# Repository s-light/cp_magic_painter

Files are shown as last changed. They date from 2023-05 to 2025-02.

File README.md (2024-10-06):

# cp_magic_painter - Malen mit Licht
POV (Persistance Of Vision) Zauberstab

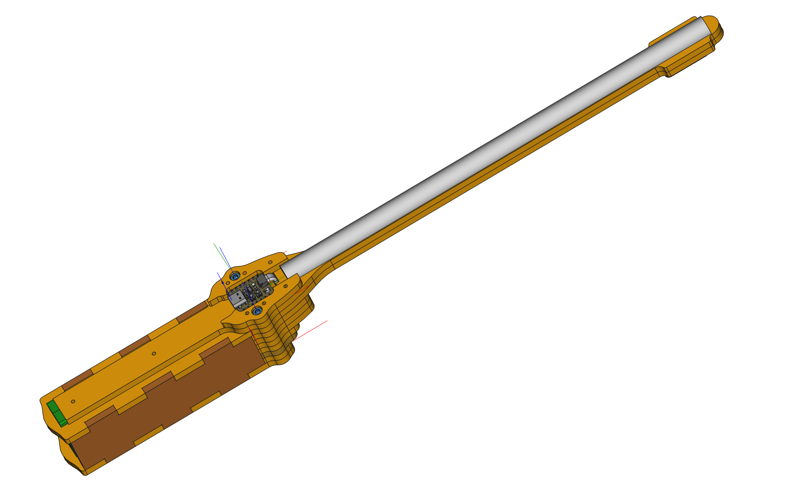
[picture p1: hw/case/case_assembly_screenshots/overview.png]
Zauberstab (CAD)

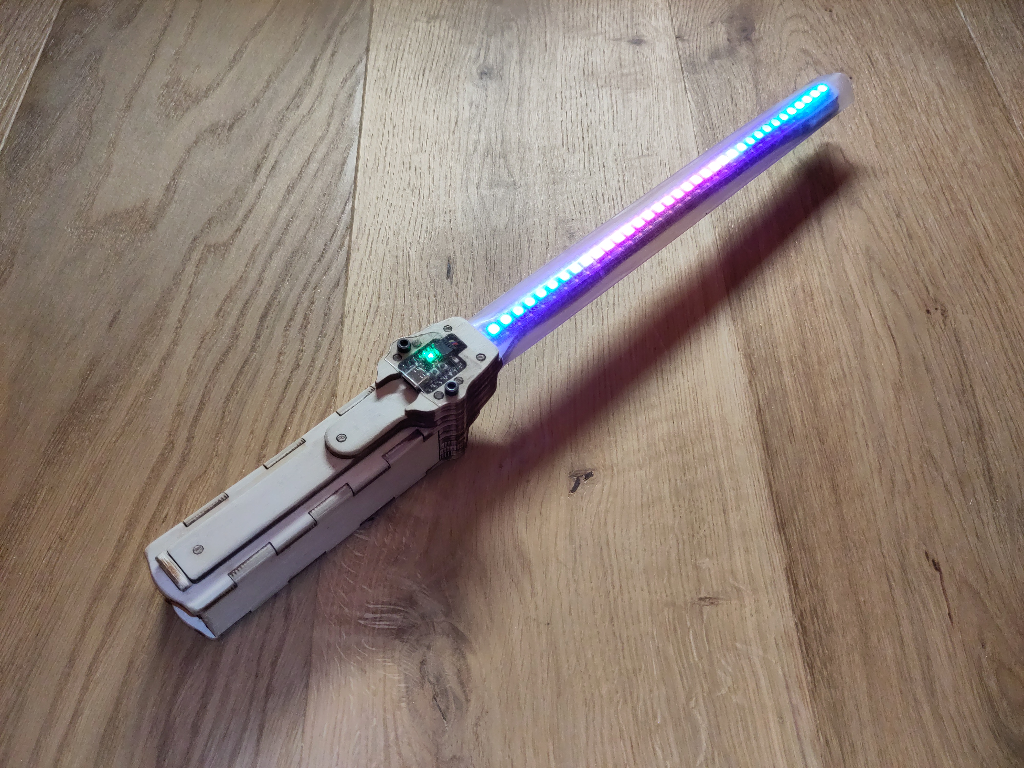
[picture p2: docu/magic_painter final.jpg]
Zauberstab Photo


https://github.com/s-light/cp_magic_painter/assets/1340319/28aa995e-11ee-43ee-a761-ba1665ddfda5

## documentation
have a look at [the documentation](https://s-light.github.io/cp_magic_painter/docu/)

Wichtige Dokumentations-Seiten:
- [Firmware Aktualisieren](https://s-light.github.io/cp_magic_painter/docu/update_firmware/de.html)
- [Bilder Vorbereiten](https://s-light.github.io/cp_magic_painter/docu/prepare_images/de.html)
- [Bedienung](https://s-light.github.io/cp_magic_painter/docu/usage/de.html)

## origin
this project / Workshop was first created for the [`Make Your School MakerFestival 2023`](https://www.makeyourschool.de/maker-festival/)

it is based on these two excellent Adafruit tutorials:
- [circuitpython painter](https://learn.adafruit.com/circuitpython-painter)
- [clue light paintstick](https://learn.adafruit.com/clue-light-paintstick)

## needed circuitpython libraries

- nonblocking_serialinput
- adafruit_lis3dh
- adafruit_pioasm
- adafruit_debouncer
- adafruit_pixelbuf
- adafruit_neopxl8
- adafruit_dotstar
- adafruit_ticks
- neopixel
- adafruit_msa3xx
- adafruit_bus_device
- ansi_escape_code
- adafruit_fancyled
- adafruit_imageload
- adafruit_register

## HW
have a look in [hw/](./hw/)

- uC: [Adafruit QT Py S3](https://learn.adafruit.com/adafruit-qt-py-esp32-s3/)
- sensor: [Adafruit LIS3DH Triple-Axis Accelerometer Breakout](https://learn.adafruit.com/adafruit-lis3dh-triple-axis-accelerometer-breakout/overview)
- LEDs: APA102 / Dotstar ([z.B. this one](https://www.adafruit.com/product/2241) - we need 36Pixel (25cm))

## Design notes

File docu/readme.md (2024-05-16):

# cp_magic_painter - Malen mit Licht 
POV (Persistance Of Vision) Zauberstab

Zauberstab (CAD)
Zauberstab Photo
<video src="mode%20POVPainter.mp4" controls title="Mode: POVPainter - showing two different images"></video>

currently some documentation is only written in german.
an english version will follow hopefully some day...

## Build / Zusammenbauen
- [build documentation / Bau-Workshop Anleitung (DE)](workshop_DE.md)

## Prepare / Vorbereitungen

- [prepare images / Bilder Vorbereiten (DE)](prepare_images/de.md)
- [update firmware / Software Aktualisiseren (DE)](update_firmware/de.md)

## Usage / Benutzung

- [Benutzung (DE)](usage/de.md)
- [usage (EN)](usage/en.md)

to take lightpainting photos have a look at [my simple lightpaint web-app](https://s-light.github.io/quasar_lightpaint/dist/spa/#/)
([repro](https://github.com/s-light/quasar_lightpaint))

## HW

-   APA102 ('Dotstar') LED-Pixel-Strip 144Pixel/m - **36 LEDs**
-   [Adafruit QT Py ESP32-S3](https://www.adafruit.com/product/5426) as controller
-   [Adafruit LIS3DH Triple-Axis Accelerometer](https://www.adafruit.com/product/2809)
-   USB PowerBank [PNY PowerPack T2600 (P-B-2600-1-K01-RL)](https://www.pny.com/File%20Library/Support/PNY%20Products/Resource%20Center/PowerPacks/PowerPack_T-Series_web.pdf) i got some old stock - nice form factor: 101,9 mm x 24 mm x 22,3 mm
  sadly its getting hard to get these Lithium-ion cylindrical cell packs..
-   some [lasercut wood](hw/case/export/case_parts_mod.svg) for the case..

for more details have a look at the [order_overview.pdf](hw/order__overview.pdf)

## project state

next steps
- firmware
  - fix touch buttons
  - add gesture recognition
- docu
  - how to update firmware
  - how to change configuration

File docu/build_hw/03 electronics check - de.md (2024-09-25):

# Elektronik vorbereiten

<style>
    html, body {
        background: hsl(270,100%,10%);
        color: hsl(40, 100%, 50%);
        font-size: 1.2em;
    }
    img {
        max-width: 90vw;
        max-height: 60vh;
    }
</style>

<!-- LED-Streifen
![LED-Streifen](<pictures/03 test electronics/20230913_132513_HDR.jpg>)
Controller
![Controller](<pictures/03 test electronics/20230916_224711.jpg>)
adapter
![adapter](<pictures/03 test electronics/20230917_012738.jpg>) -->

alle bauteile zurecht legen
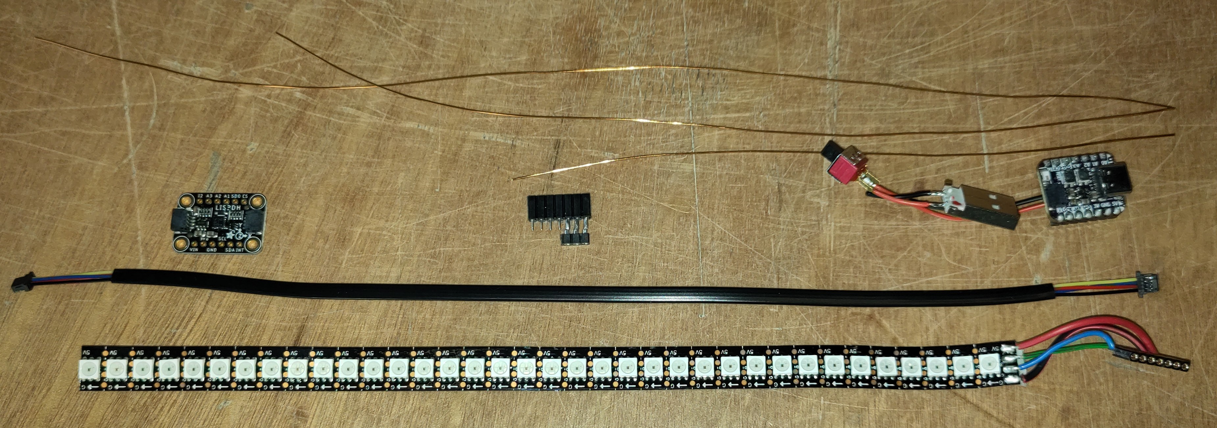
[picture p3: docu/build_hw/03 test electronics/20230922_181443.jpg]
electronic parts


In den Fotos sind noch \*Touch-Buttons zu sehen.
Diese habe ich wegen unzuverlässigkeit raus genommen.

## Beschleunigungssensor

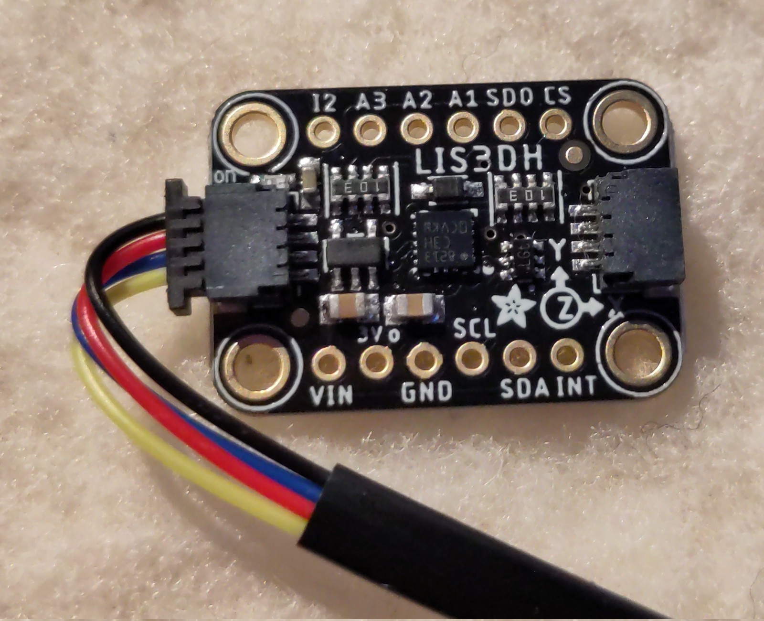
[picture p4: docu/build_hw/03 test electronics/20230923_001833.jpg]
sensor


im bild oben rechts ist die Power-LED sichtbar.
Unten auf der Platine ist `VIN` aufgedruckt.
auf dieser Seite möchte das Kabel eingesteckt werden.
schon mal etwas vorsichtig umbiegen wie im bild hilft später für die Positionierung.

# Elektronik testen

## LED-Streifen

nun den led-streifen an den controller anschließen
dabei auf die beschriftungen auf der Controller-Platine achten:

-   rotes Kabel auf +5V
-   schwarzes Kabel auf GND
-   Blaue sollte bei SCK (clock) landen
-   Grün bei MOSI (Master Out Slave In)

## Beschleunigungssensor

das freie Ende nun in den Controller stecken

## Buttons

falls vorhanden:
die drei Buttons kommen in die Pins mit den Namen

-   `SDA` unterster Button
-   `SCL` mittlerer Button
-   `TX` oberer Button

## alle bauteile zusammengesteckt

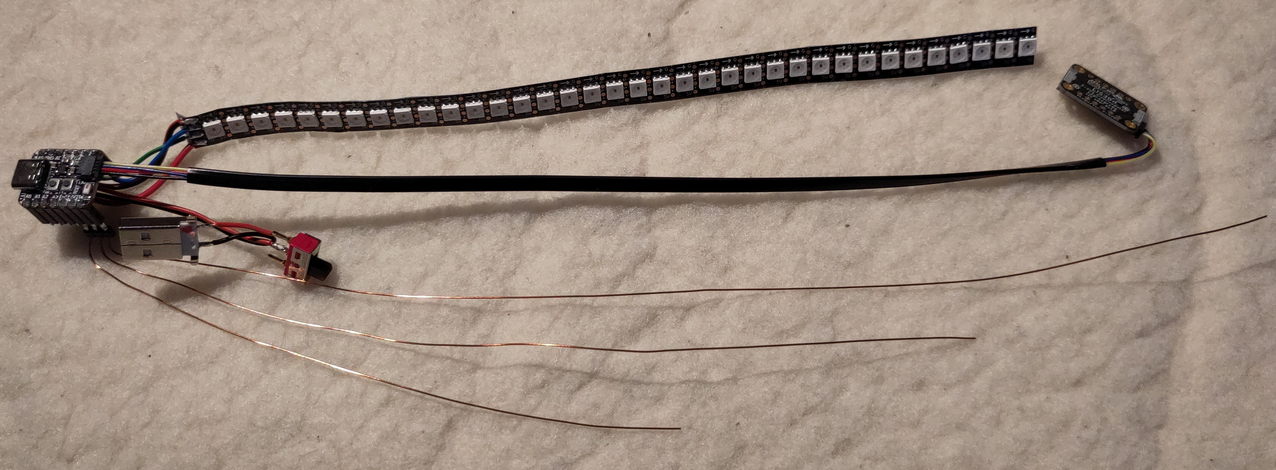
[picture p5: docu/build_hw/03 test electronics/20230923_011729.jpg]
alle bauteile zusammengesteckt


> vorsichtig das sich keine metallteile berühren!

nun Vorsichtig die Powerbank anstecken..
Schalter einschalten
und....

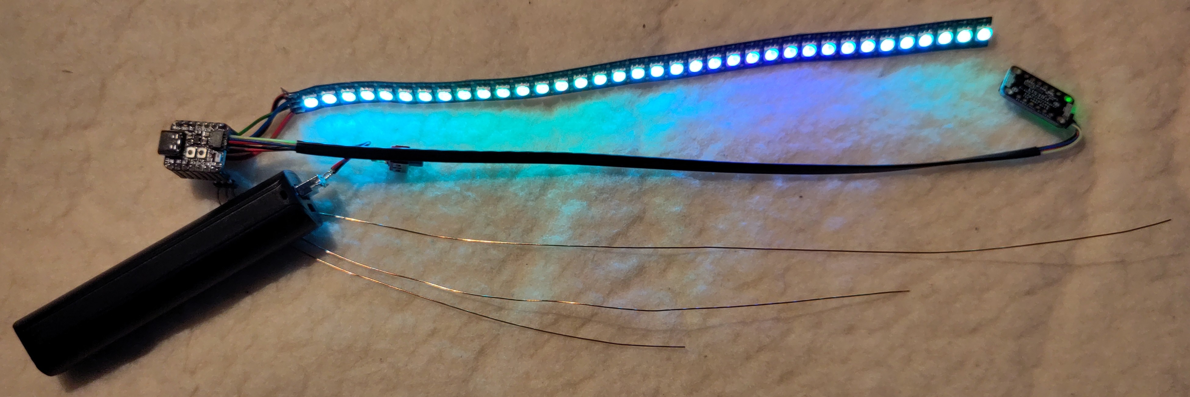
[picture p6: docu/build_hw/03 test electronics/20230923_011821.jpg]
und einmal testen

und alles geht :-)

## Test

-   erst sollte auf dem Controller die LED in verschiedenen Farben Leuchten.
-   dann der Streifen einen grünen _ladebalken_ anzeigen
-   dann einmal vorsichtig den Sensor in der Y-Achse schütteln
-   darauf hin sollte der Streifen flackern
-   dann den Taster D0 auf dem Controller drücken
-   dies schaltet in den Lampen modus um
-   nun leuchtet eine LED ganz am ende des Streifens
-   nun den längsten Draht / Button _oben_ mehrfach berühren
-   darauf hin sollten auf dem Streifen immer mehr LEDs an gehen / es wird heller
-   beim mittleren Button sollten diese wieder ausgehen / dunkler werden
-   beim untersten Button sollte die Helligkeit wieder auf minimum (1 LED) springen

damit sind alle Funktionen getestet.
→ Power-Schalter wieder ausschalten und Powerbank abziehen

→ Bauteile wieder auseinander stecken !!

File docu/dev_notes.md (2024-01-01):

# Notes from development

## Gesture / Sensor Data / Filter
- https://courses.ideate.cmu.edu/16-223/f2021/text/code/pico-signals.html#hysteresis-py
- https://stackoverflow.com/questions/4611599/smoothing-data-from-a-sensor
- https://hackaday.com/2019/09/06/sensor-filters-for-coders/    
- https://stackoverflow.com/questions/29330792/weighted-averaging-a-list
- https://stackoverflow.com/questions/18517722/weighted-moving-average-in-python

## Others
- https://learn.adafruit.com/key-pad-matrix-scanning-in-circuitpython/keys-one-key-per-pin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
- [Cooperative Multitasking in CircuitPython with asyncio](https://learn.adafruit.com/cooperative-multitasking-in-circuitpython-with-asyncio/communicating-between-tasks)
    - https://github.com/adafruit/Adafruit_CircuitPython_asyncio/blob/main/examples/serial_examples.py
- https://learn.adafruit.com/clue-light-paintstick/make-pixel-art
- https://github.com/adafruit/Adafruit_CircuitPython_DotStar/issues/64
- https://github.com/hfg-gmuend/openmoji.org/issues/182

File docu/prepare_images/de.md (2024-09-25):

<style>
    html, body {
        background: hsl(270,100%,10%);
        color: hsl(40, 100%, 50%);
        font-size: 1.2em;
    }
    img {
        max-width: 80vw;
        max-height: 50vh;
    }
</style>

# Vorbereitung der Bilder

Momentan werden Bilder in Folgendem Format unterstützt:

```
Datei-Typ: BMP
Farb-Tiefe: 3x8bit
Auflösung: 36x36 Pixel
```

als Symbole eignen sich _icons_ aus dem Schriftsatz Bereich -
das was wir als _emoji_ & _smiley_ kennen...
diese sind optimiert in sehr klein - also mit wenig Pixeln - gut erkennbar zu sein.

alternativ kannst du natürlich auch andere bild-quellen nehmen oder etwas selbst malen..

Damit der Zauberstab die Bilder anzeigen kann müssen diese in einem Speziellen Format gepeichert sein.
dieses nennt sich `Windows Bitmap` - und es ist wichtig das es als `24bits` `8R 8G 8B` gespeichert wird.

ich habe dir eine Anleitung geschrieben die genau das mit eben einem emoji macht.

am einfachsten ist es du suchst dir solch ein symbol auf dieser Website heraus:
https://openmoji.org/

alternative gibt es auch apps für den computer um diese als eine liste zu haben..
für linux z.B. den `emoji selector`

## Video Anleitung

Ich habe dir zwei kurze Videos gemacht:

1. Emoji suchen und kopieren
   <video src="openmoji.org%20search%20and%20copy%20%20candle.mp4" controls title="Title"></video>
2. Gimp - einfügen und ausrichten
   <video src="gimp%20paste%20candle.mp4" controls title="Title"></video>

## Text Anleitung

und hier als schritt für schritt text Anleitung:

1. Emoji suchen und kopieren

-   rufe die website [openmoji.org](https://openmoji.org/) auf
-   suche nach einem begriff (englisch)
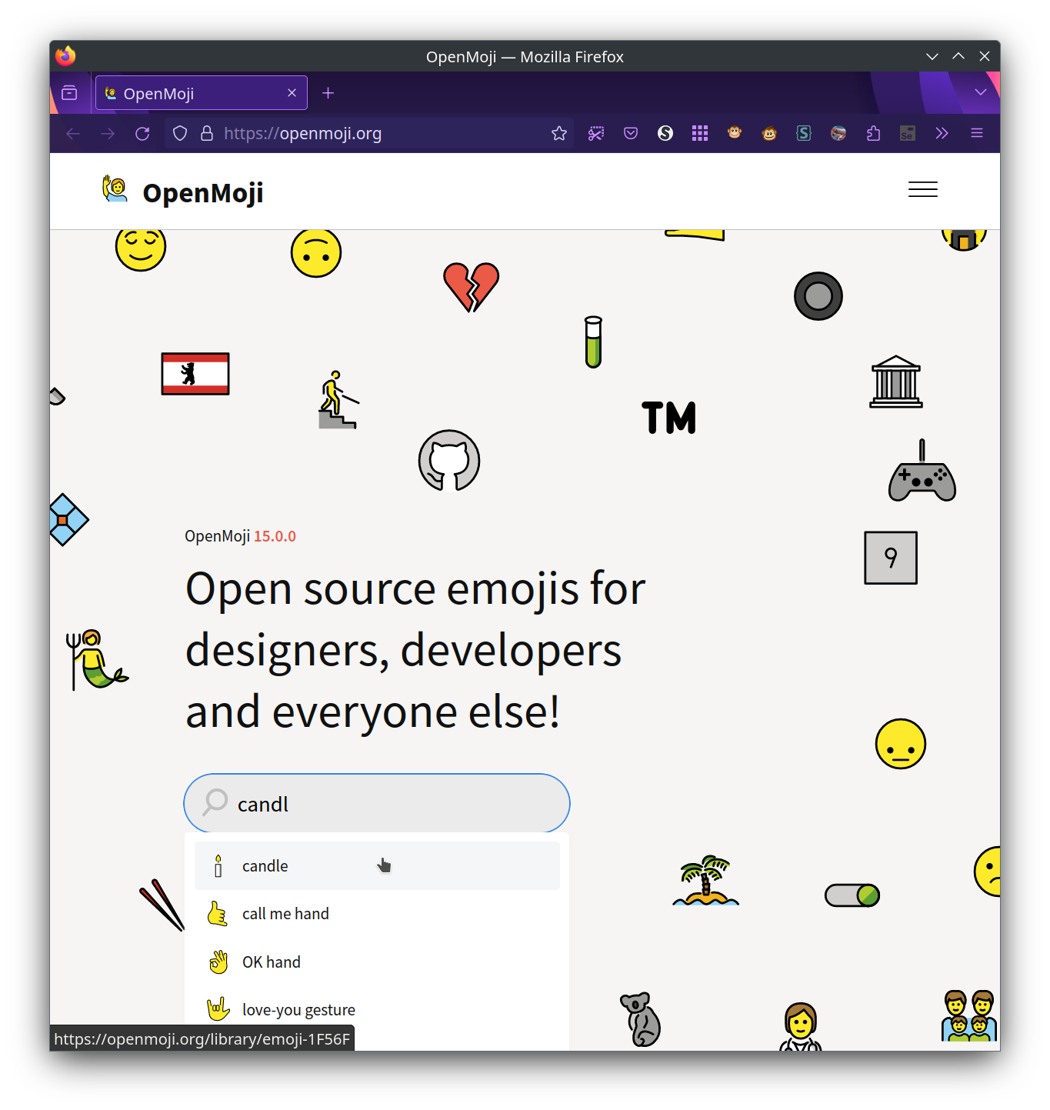
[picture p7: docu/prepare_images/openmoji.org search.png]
openmoji.org search
    
-   und öffne die detail Ansicht des emoji
-   nun in die zwischenablage kopiere 
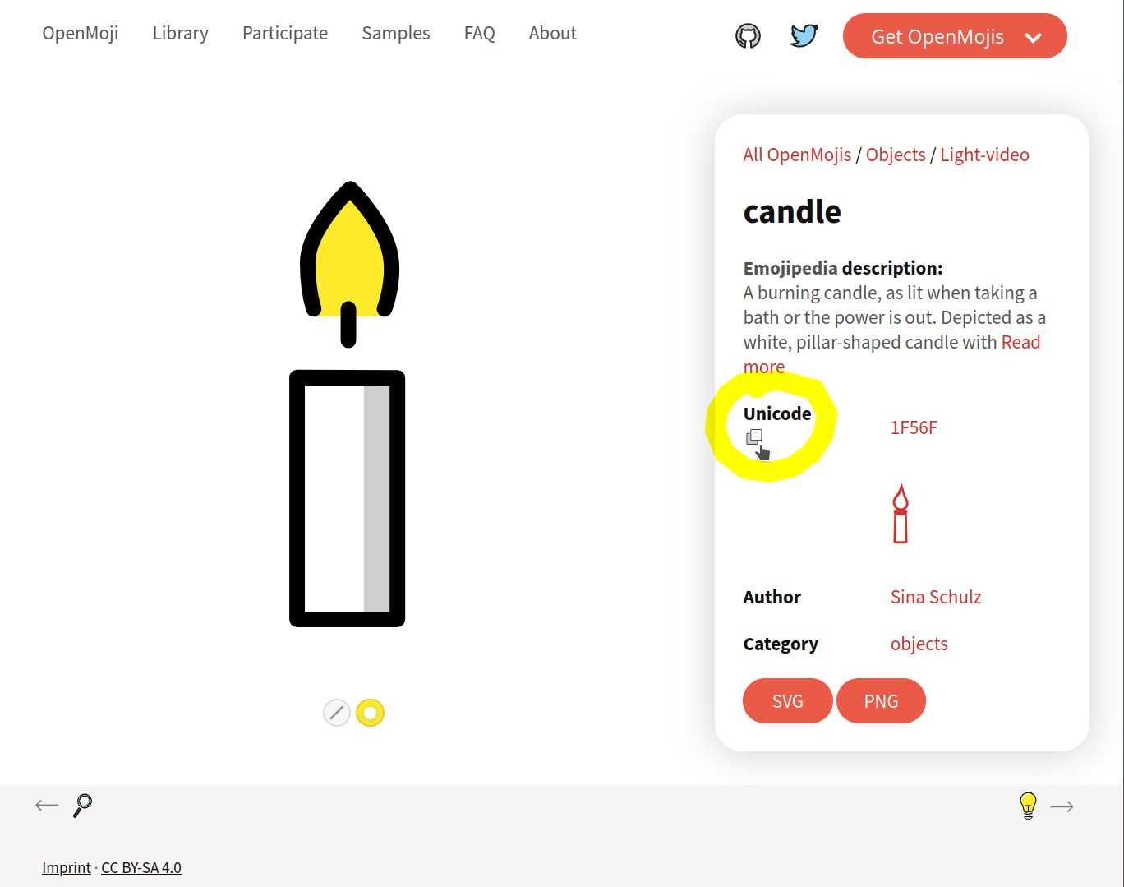
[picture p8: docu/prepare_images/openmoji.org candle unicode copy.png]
openmoji.org candle
    
-   das *Unicode-Zeichen* mit dem kleinen *CopyButton*
    <!-- - **oder** alternative das openmoji Bild mit Strg + click auf den PNG button -->

2. Gimp - einfügen und ausrichten

ich verwende hier [Gimp (GNU Image Manipulation Program)](https://www.gimp.org/).
dies ist ein Frei Verfügbares Bild-Bearbeitungsprogramm welches auf allen gängigen PCs laufen sollte.
die Schritte können jedoch ansich auch mit jedem anderen Grafik-Program durchgeführt werden.

-   [Gimp (GNU Image Manipulation Program) installieren](https://www.gimp.org/)
-   Gimp Starten
-   lade das Beispielbild [`images/01_testpattern_smile.xcf`](./../../CIRCUITPY_disc/images/01_testpattern_smile.xcf) herunter
-   das Beispielbild `01_testpattern_smile.xcf` öffnen: `Datei - Öffnen`
-   dort gibt es nun ein _text_ object.
-   aktivieren des `text tool` (shortcut: `t`):
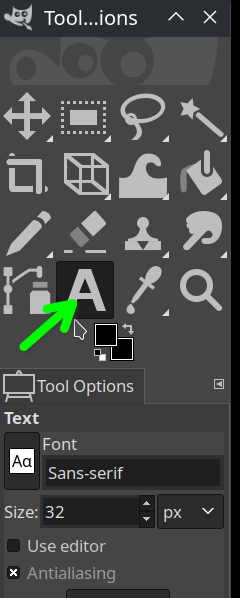
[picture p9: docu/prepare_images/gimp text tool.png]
text tool anwählen
    
-   nun mit einem click auf den smiley das object anwählen
-   nun ist der Text Modus aktiv.
-   unsere Schrift Größe ist ca 32pixel - so füllt das symbol die ganze Höhe aus.
-   du kannst jetzt das alte symbol löschen
-   und mit `Strg + V` das neue aus der zwischenablage einfügen
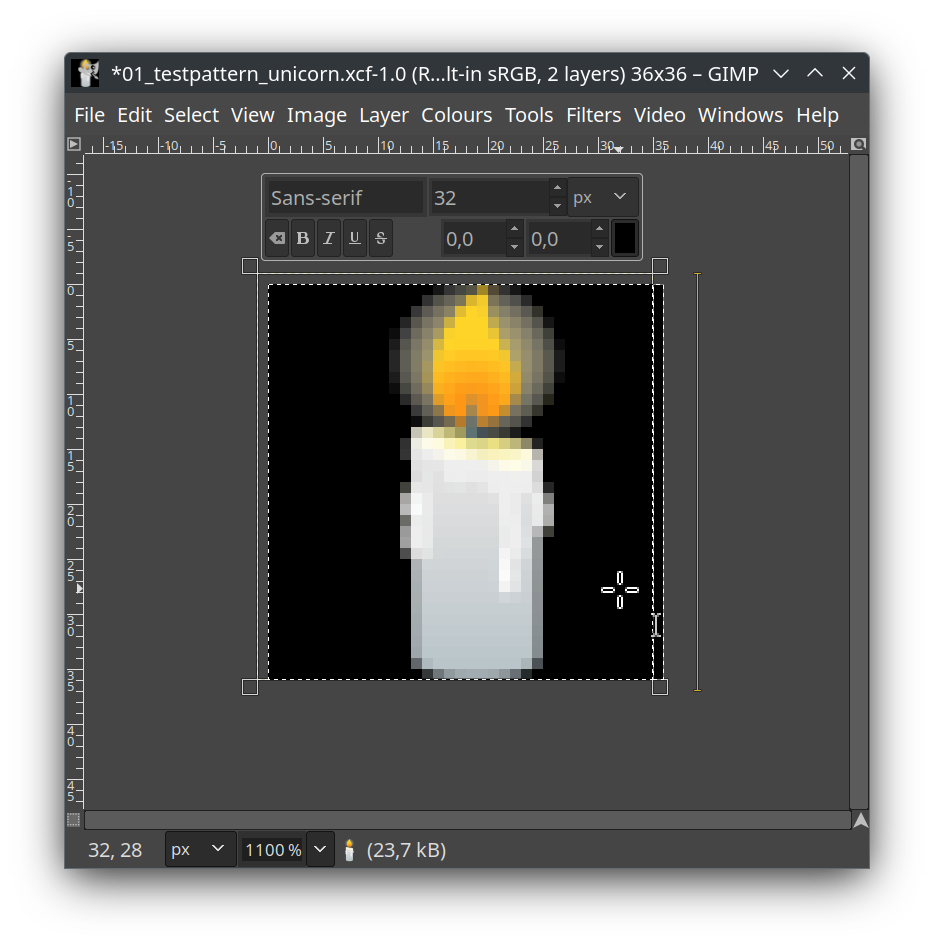
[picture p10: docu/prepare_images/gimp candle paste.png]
gimp pasted
    
-   eventuell jetzt noch die font-größe anpassen..
-   und dann falls nötig mit dem verschiebe tool passend positionieren:
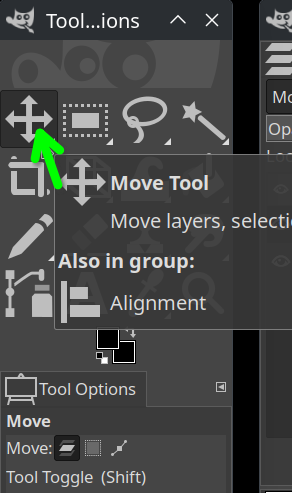
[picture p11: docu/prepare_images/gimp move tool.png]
gimp move tool
    
-   am einfachsten lässt es sich mit den pfeiltasten verschieben..
-   nun noch speichern: `Datei - Exportieren als`
    -   name wählen und als Dateiendung `bmp` angeben.
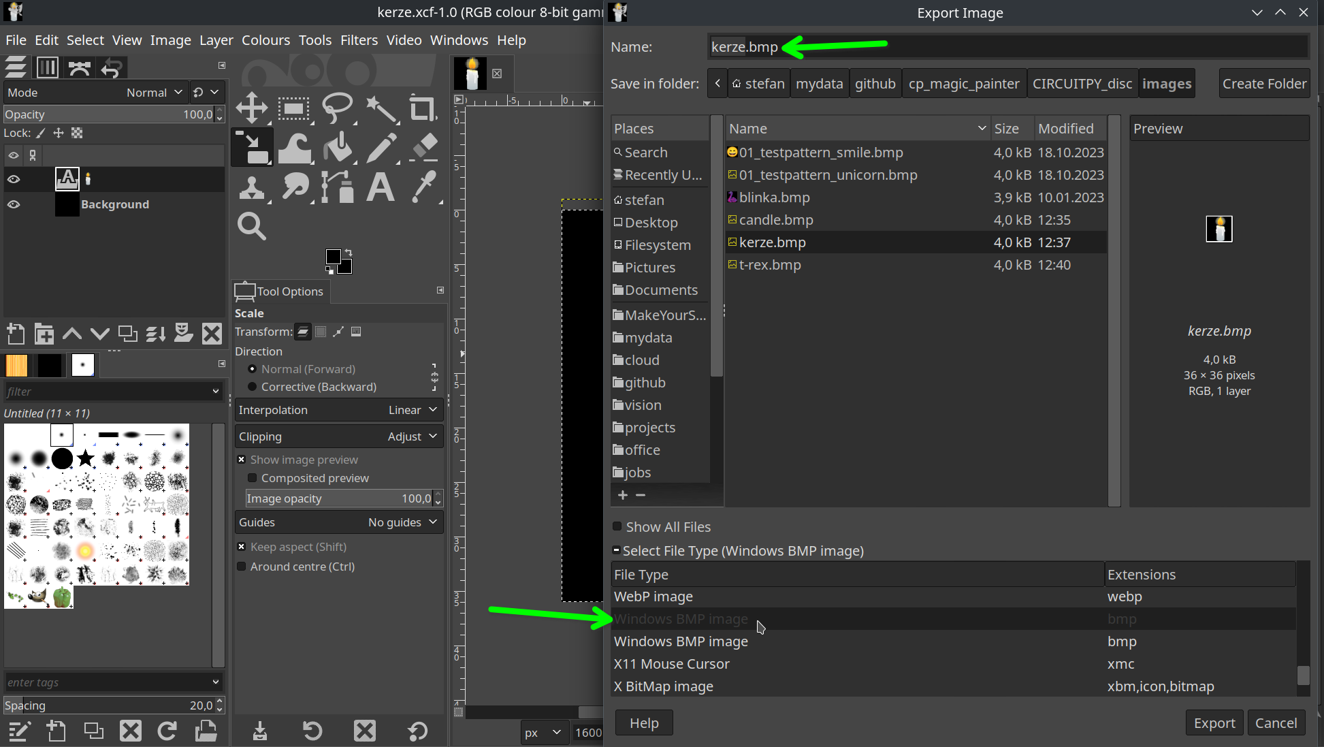
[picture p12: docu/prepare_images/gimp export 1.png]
gimp export 1
        
    -   export drücken
    -   und nun `advanced options` aufklappen und `24bits` `8R 8G 8B` auswählen
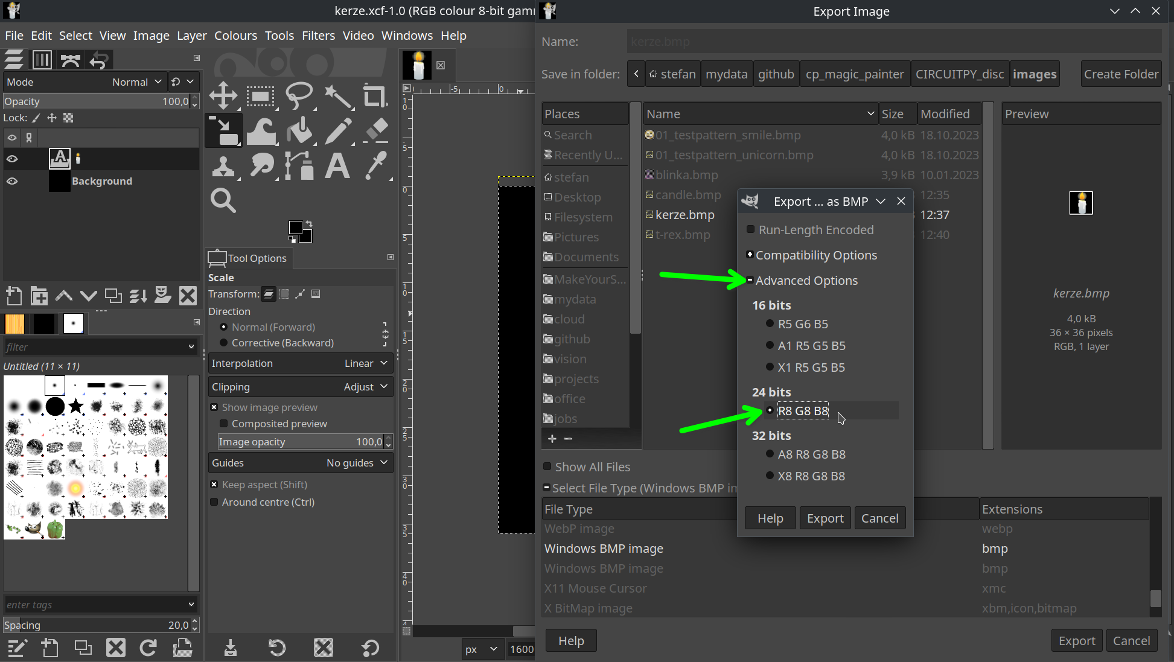
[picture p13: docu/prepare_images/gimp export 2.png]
gimp export 2
        
-   nun noch das neue Bild auf den Zauberstab kopieren
    -   dafür den Zauberstab an den computer anschließen
    -   den Datei-Explorer öffnen
    -   es sollte ein neuer USB-Speicherstick mit dem Namen `CIRCUITPY` erschienen sein.
    -   dort gibt es einen Ordner `images`
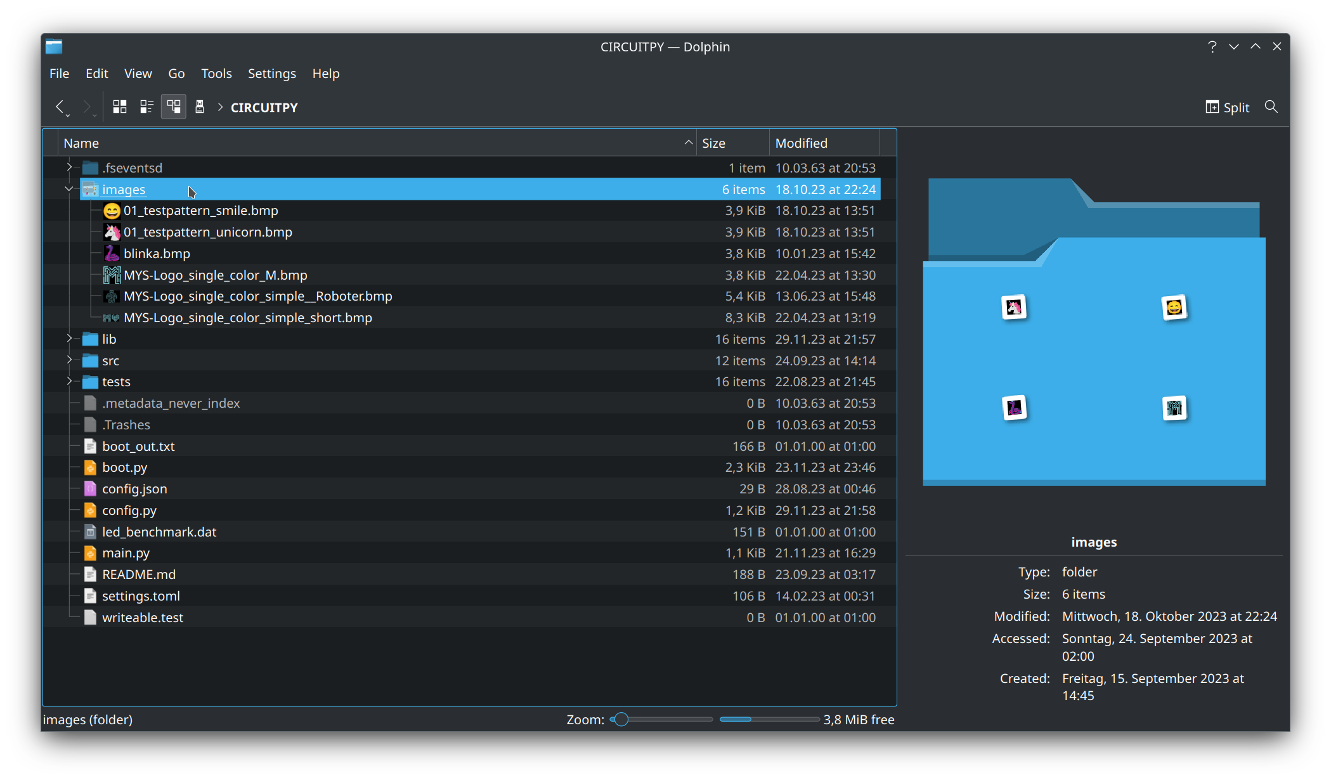
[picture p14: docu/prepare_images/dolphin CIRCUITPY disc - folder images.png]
CIRCUITPY disc - folder images
        
    -   dort hinein gehört das neue bild.

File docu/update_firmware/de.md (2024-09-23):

# Update *Firmware*

hier eine kurze Anleitung wie du die Firmware - 
also das Program auf dem Zauberstab-controller -
auf die neuste Version aktualisierst:

hier im beispiel auf meinem Linux System - 
doch ich denke das du das gut auf dein eigenes System übertragen kannst..

## Video

<video src="update_firmware.mp4" controls title="Update Firmware"></video>

## Schritt für Schritt Text

- download der aktuellen version von [github.com/s-light/cp_magic_painter](https://github.com/s-light/cp_magic_painter)
- entpacken des ZIP-Archives
- in den unterordner `CIRCUITPY_disc` gehen
- dort alle Dateien markieren
- kopieren (RechtsClick `Kopieren` oder mit Tastatur: `Strg+C`)
- den Zauberstab mit dem Computer verbinden
- es taucht ein neues USB-Massenspeicher-Laufwerk mit dem Namen `CIRCUITPY` auf
- dort RechtsClick einfügen oder ShortCut `STrg+V`
- abfrage: alles überschreiben? `JA`
- prüfen das KEIN `code.py` vorhanden ist.

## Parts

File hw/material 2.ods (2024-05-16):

Material übersicht / Sammlung |  |  | bestellt am | preis |  |  | anteil je TN |  | für WS je TN |  | Für WS ges.
 |  |  |  | gesamt |  |  |  |  |  |  | Menge | Summe
Bereich | Produkt | url |  | inkl. vers. | menge | Preis | anteil | preis | verwendet | 55,04 € | 12TN | 662,05 € | comment 1 | comment 2 | comment 3
 | Powerbank Sacramento - blau | https://www.highflyers.de/product_info.php/products_id/122607 | - | 93,97 € | 23 | 4,09 € | 1 | 4,09 € |  |  |  |  | 92 mm x 25 mm x 25 mm | 2200mAh, microUSB, 1A, min 22x | mind. 23
 | Aluminium Powerbank POWERALU - silber matt | https://www.highflyers.de/product_info.php/products_id/89293 | - | 96,31 € | 18 | 5,35 € | 1 | 5,35 € |  |  |  |  | 95 mm x 21 mm x 21 mm | 2200mAh, microUSB, 1A, min 16x | mind. 18
 | Powerbank ENDURANCE - blau (metal) | https://www.highflyers.de/product_info.php/products_id/75415 | - | 216,52 € | 50 | 4,33 € | 1 | 4,33 € |  |  |  |  | 100 mm x 20 mm x 20 mm | 2200mAh, microUSB, 1A, min 50x | mind. 50
 | Metallpowerbank Port Hope | https://www.highflyers.de/product_info.php/products_id/112119 | - | 93,12 € | 21 | 4,43 € | 1 | 4,43 € |  |  |  |  | 95 mm x 21 mm x 22 mm | 2200mAh, microUSB | mind. 21
 | Livepac Office - Powerbank aus Aluminium | https://www.ebay.de/itm/125127449122?itmmeta=01HRJJ77C5Z9E78R9E8C7FH46N | - | 61,83 € | 12 | 5,15 € | 1 | 5,15 € |  |  |  |  | 95 mm x 21 mm x 22 mm | 2200mAh, microUSB
 | Powerbank aus Aluminium 2.200 mAh Einzeln Restposten | https://www.amazon.de/gp/product/B07RS3WMG1 | 10.03.24 | 60,00 € | 12 | 5,00 € | 1 | 5,00 € | 1 | 5,00 € | 12 | 60,00 € | 95 mm x 21 mm x 22 mm | 2200mAh, microUSB
 | Powerbank aus Aluminium 2.200 mAh 20Stück | https://www.amazon.de/gp/product/B07H36LNGX | - | 85,00 € | 20 | 4,25 € | 1 | 4,25 € |  |  |  |  | 95 mm x 21 mm x 22 mm | 2200mAh, microUSB
 | Powerbank aus Aluminium 2.200 mAh Einzeln | https://www.amazon.de/gp/product/B076TGKS37 | - | 62,88 € | 12 | 5,24 € | 1 | 5,24 € |  |  |  |  | 95 mm x 21 mm x 22 mm | 2200mAh, microUSB
LEDs | SK9822 144LEDs/m offen | https://www.amazon.de/dp/B07BPX2KFD | 10.03.24 | 112,29 € | 3 | 37,43 € | 0,25 | 9,36 € | 1 | 9,36 € | 12 | 112,29 € | BFT-Lighting bekannter amazon shop
 | SK9822 144LEDs/m offen | https://www.amazon.de/dp/B0BYSHDDWT?th=1 | - | 83,70 € | 3 | 27,90 € | 0,25 | 6,98 € |  |  |  |  | unbekannter amazon shop
 | APA102 Narrow 5mm 2020SMD 200LEDs/M | https://www.superlightingled.com/apa102-narrow-5mm019in-wide-2020smd-high-density-200ledsm-dc5v-individually-addressable-rgb-led-strip-lights-p-3353.html | - | 201,07 € | 3 | 67,02 € | 0,2 | 13,40 € |  |  |  |  | unbekannter shop | higher density - a little more pixels: nicer picture..
 | APA102 Narrow 5mm 2020SMD 200LEDs/M | https://www.ledlightinghut.com/apa102-2020-digital-rgb-led-strip.html | - | 208,50 € | 3 | 69,50 € | 0,2 | 13,90 € |  |  |  |  | unbekannter shop | higher density - a little more pixels: nicer picture..
controller | Adafruit QT Py ESP32-S3 | https://www.mouser.de/ProductDetail/Adafruit/5700?qs=mELouGlnn3fE0chohESxSg%3D%3D | - | 166,08 € | 12 | 13,84 € | 1 | 13,84 € |  |  |  |  | 4MB Flash 2MB PSRAM | not in stock :-(
 | Adafruit QT Py S3 2MB PSRAM | https://eckstein-shop.de/Adafruit-QT-Py-S3-WiFi-Dev-Board-with-2MB-PSRAM-STEMMA-QT | 11.03.24 | 186,00 € | 12 | 15,50 € | 1 | 15,50 € | 1 | 15,50 € | 12 | 186,00 € | 4MB Flash 2MB PSRAM | in stock
accel sensor | LIS3DH Triple-Axis Accelerometer | https://www.mouser.de/ProductDetail/485-2809 | 10.03.24 | 65,69 € | 12 | 5,47 € | 1 | 5,47 € | 1 | 5,47 € | 12 | 65,69 € | very common part
cable / power | STEMMA QT JST SH 4-pin Cable - 300mm | https://eckstein-shop.de/Adafruit-STEMMA-QT-Qwiic-JST-SH-4Pin-Cable-300mm-Long | - | 33,60 € | 12 | 2,80 € | 1 | 2,80 € |  |  |  |  | für sensor..
 | STEMMA QT JST SH 4-pin Cable - 300mm | https://www.mouser.de/ProductDetail/485-5384 | 10.03.24 | 16,56 € | 12 | 1,38 € | 1 | 1,38 € | 1 | 1,38 € | 12 | 16,56 € | für sensor..
 | SS 13ASP Schiebeschalter 1x UM, stehend, Print, RM 4,7 | https://www.reichelt.de/schiebeschalter-1x-um-stehend-print-rm-4-7-ss-13asp-p112182.html?trstct=pol_13&nbc=1 | 12.03.24 | 20,40 € | 12 | 1,70 € | 1 | 1,70 € | 1 | 1,70 € | 12 | 20,40 € | powerbank - controller | simple on off switch..
 | USB AWF USB-Einbaustecker, Serie A, gewinkelt, ultraflach | https://www.reichelt.de/usb-einbaustecker-serie-a-gewinkelt-ultraflach-usb-awf-p51993.html?&nbc=1 | 12.03.24 | 9,67 € | 12 | 0,81 € | 1 | 0,81 € | 1 | 0,81 € | 12 | 9,67 € | powerbank - controller | hier versand reichelt mit drin.
gehäuse & co | SDB 19,1 TR (5m, transparent, Ø19,1mm) | https://www.reichelt.de/schrumpfschlauch-box-5m-transparent-19-1mm-sdb-19-1-tr-p53814.html | 13.03.24 | 5,45 € | 5 | 1,09 € | 0,3 | 0,33 € | 1 | 0,33 € | 12 | 5,45 €
 | holz | https://cwwh.de/ |  | 185,99 € | 12 | 15,50 € | 1 | 15,50 € | 1 | 15,50 € | 12 | 185,99 €
 |  |  |  | 95,96 €

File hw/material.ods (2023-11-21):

Material übersicht / Sammlung |  |  |  |  |  | Für WS
 |  |  |  |  |  | Menge | Summe |  |  |  | order
Bereich | Produkt | url | Preis | menge je TN | preis TN | 10TN | 261,30 € | comment 1 | comment 2 | comment 3 | date | shop | orig manufacture link
Power | INTENSO Powerbank 10000mAh (https://www.reichelt.de/powerbank-li-po-10000-mah-usb-c-petrol-intenso-7313537-p283039.html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) | https://www.reichelt.de/powerbank-li-po-10000-mah-usb-c-petrol-intenso-7313537-p283039.html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 | 16,95 € | 0 | 0,00 € | 0 | 0,00 € | 91 mm x 63 mm x 22 mm | 10000mAh, USB-C, 2,4A | housing to big
 | INTENSO Powerbank 5000mAh (https://www.reichelt.de/powerbank-li-po-5000-mah-usb-c-petrol-intenso-7313527-p283036.html) | https://www.reichelt.de/powerbank-li-po-5000-mah-usb-c-petrol-intenso-7313527-p283036.html | 12,80 € | 0 | 0,00 € | 0 | 0,00 € | 90 mm x 63 mm x 12,6 mm | 5000mAh, USB-C, 2,4A | housing to big
 | NanoWave 3 5000mAh USB-C | https://shop.pimoroni.com/products/nanowave-3-5000mah-usb-c-a-power-bank | 15,39 € | 0 | 0,00 € | 0 | 0,00 € | 76 mm x 35 mm x 27 mm | 5000mAh, USB-C, 2,4A
 | Realpower PB-Lipstick | https://www.smdv.de/products/869639/RealPower-PB-Lipstick-Powerbank-2500-mAh-Li-Ion-Gruen.html | 6,90 € | 0 | 0,00 € | 0 | 0,00 € | 93 mm x 22 mm x 22 mm | 2500mAh, microUSB, 1A
 | Powerbank Sacramento - schwarz | https://www.highflyers.de/product_info.php/products_id/122606 | 3,23 € | 0 | 0,00 € | 0 | 0,00 € | 92 mm x 25 mm x 25 mm | 2200mAh, microUSB, 1A, min 22x
 | Aluminium Powerbank POWERALU - silber matt | https://www.highflyers.de/product_info.php/products_id/89293 | 4,58 € | 0 | 0,00 € | 0 | 0,00 € | 95 mm x 21 mm x 21 mm | 2200mAh, microUSB, 1A, min 16x
 | Powerbank ENDURANCE - blau (metal) | https://www.highflyers.de/product_info.php/products_id/75415 | 3,50 € | 0 | 0,00 € | 0 | 0,00 € | 100 mm x 20 mm x 20 mm | 2200mAh, microUSB, 1A, min 50x
 | EnergyQC USB C 5000mAh | https://www.amazon.de/dp/B0B158K8KK/ | 18,99 € | 0 | 0,00 € | 0 | 0,00 € | 110 mm x 27 mm x 27 mm | 5000mAh, USB-C, 2,4A
 | EnergyQC Slim 2 5000mAh | https://www.amazon.de/dp/B0BNDLT6TB/?th=1 | 16,99 € | 0 | 0,00 € | 0 | 0,00 € | 105 mm x 27 mm x 29 mm | 5000mAh, microUSB, 2,1A
 | REALPOWER PB-5000mini | https://www.mediamarkt.de/de/product/_realpower-pb-5000mini-2472251.html | 10,98 € | 0 | 0,00 € | 0 | 0,00 € | 96 mm x 45mm x 23mm | 5000mAh, microUSB, 2,1A
 | Realpower PB-5000mini | https://www.amazon.de/dp/B07HRVKZ3G | 13,80 € | 0 | 0,00 € | 0 | 0,00 € | 96 mm x 45mm x 23mm | 5000mAh, microUSB, 2,1A | this seems to be the best in between version..
 | RealPower PB-260 ALU Multipack 3x | https://shop.okluge.de/realpower-pb-260-alu-multipack-3x-2600mah-powerbank-mobiles-ladegeraet-taschenlampe.html | 3,30 € | 0 | 0,00 € | 0 | 0,00 € | 102 mm x 28 mm x 28 mm | 2600mAh, microUSB, 1A
 | PNY Tseries T2600 | https://talk-point.de/products/10052260-0 | 1,99 € | 1 | 1,99 € | 10 | 19,90 € | 101,9 mm x 24 mm x 22,3 mm | 2600mAh, microUSB, 1A | 10€ versand
LEDs | SK9822 144LEDs/m offen | https://www.amazon.de/dp/B07BPX2KFD | 39,00 € | 0,25 | 9,75 € | 2,5 | 97,50 € | BFT-Lighting bekannter amazon shop
 | SK9822 144LEDs/m offen | https://www.amazon.de/dp/B0BYSHDDWT?th=1 | 27,50 € | 0 | 0,00 € | 0 | 0,00 € | unbekannter amazon shop
 | SK9822 144LEDs/m vergossen | https://www.amazon.de/dp/B0BYSKP1TD?th=1 | 28,50 € | 0 | 0,00 € | 0 | 0,00 € | unbekannter amazon shop
 | SK9822 144LEDs/m Silikon Hülle | https://www.amazon.de/dp/B0BYSMJ8QJ | 28,50 € | 0 | 0,00 € | 0 | 0,00 € | unbekannter amazon shop
controller | Adafruit ESP32-S3 TFT reverse | https://www.adafruit.com/product/5691 | 29,67 € | 0 | 0,00 € | 0 | 0,00 € | 4MB Flash 2MB PSRAM | display, buttons, USB-C | Einfuhr Ust: 23,75€/Board + 19% = 28,26€/Board + 6€/12Boards = 28,76€ | 19.04.23 | adafruit.com |  | 23,8933333333333 | 5,76833333333333 | 29,6616666666667
 | Adafruit ESP32-S3 TFT | https://eckstein-shop.de/Adafruit-ESP32-S3-TFT-Display-Feather-Board-4MB-Flash-2MB-PSRAM-STEMMA-QT | 33,00 € | 0 | 0,00 € | 0 | 0,00 € | 4MB Flash 2MB PSRAM
 | FeatherS3 - ESP32-S3 | https://www.exp-tech.de/plattformen/esp32/10679/feathers3-esp32-s3-development-board | 29,00 € | 0 | 0,00 € | 0 | 0,00 € | 16MB Flash 8MB PSRAM | not on stock
 | Adafruit ESP32-S3 Feather 8 | https://www.exp-tech.de/plattformen/esp32/10678/adafruit-esp32-s3-feather-with-stemma-qt/qwiic | 17,50 € | 0 | 0,00 € | 0 | 0,00 € | 8MB Flash No PS | in stock
 | Adafruit ESP32-S3 Feather 4/2 | https://www.exp-tech.de/plattformen/esp32/11087/adafruit-esp32-s3-feather-with-4mb-flash-2mb-psram | 16,50 € | 0 | 0,00 € | 0 | 0,00 € | 4MB Flash 2MB PSRAM | in stock
 | ProS3 - ESP32-S3 | https://www.exp-tech.de/plattformen/esp32/10681/pros3-esp32-s3-development-board | 32,00 € | 0 | 0,00 € | 0 | 0,00 € | 16MB Flash 8MB PSRAM
 | Adafruit QT Py ESP32-S3 | https://www.adafruit.com/product/5426 | 14,39 € | 1 | 14,39 € | 10 | 143,90 € | 8 MB Flash / No PSRAM | in stock |  | 08.05.23 | adafruit.com | https://www.adafruit.com/product/5426 | 14,39 | 0
 | ESP32-S3-DevKitC-1-N8R8 | https://www.mouser.de/c/?q=ESP32-S3-DevKitC-1-N8R8 | 14,10 € | 0 | 0,00 € | 0 | 0,00 € | 8MB Flash 8MB PSRAM
 | ESP32-S3-DevKitC-1-N32R8V | https://www.mouser.de/c/?q=ESP32-S3-DevKitC-1-N32R8V | 17,00 € | 0 | 0,00 € | 0 | 0,00 € | 32MB Flash 8MB PSRAM
accel sensor | LIS3DH Triple-Axis Accelerometer | https://www.mouser.de/ProductDetail/485-2809 | 5,53 € | 1 | 5,53 € | 10 | 55,34 € | very common part
 | MSA301 Triple Axis Accelerometer | https://eckstein-shop.de/Adafruit-MSA311-Triple-Axis-Accelerometer-STEMMA-QT-Qwiic | 6,00 € | 0 | 0,00 € | 0 | 0,00 € | should work
 | BNO085 - 9-DOF Orientation IMU Fusion | https://learn.adafruit.com/adafruit-9-dof-orientation-imu-fusion-breakout-bno085/python-circuitpython | 31,00 € | 0 | 0,00 € | 0 | 0,00 € | mega nices spielzeug..
cable / power | STEMMA QT JST SH 4-pin Cable - 100mm | https://eckstein-shop.de/STEMMAQT2FQwiicJSTSH4-pinCable-100mmLongforallSensor2FDriverBoardswithQwiic | 1,50 € | 0 | 0,00 € | 0 | 0,00 € | für sensor.. | kompromiss-variante
 | STEMMA QT JST SH 4-pin Cable - 300mm | https://www.mouser.de/ProductDetail/485-5384 | 1,40 € | 1 | 1,40 € | 10 | 14,04 € | für sensor..
 | usb c - freie enden 0.2m | https://www.reichelt.de/usb-c-stecker-auf-freie-enden-sw-20-cm-usb-c-awg22-20-p292505.html | 2,05 € | 0 | 0,00 € | 0 | 0,00 € | powerbank - led streifen
 | usb c - freie enden 0.5m | https://www.reichelt.de/usb-c-stecker-auf-freie-enden-sw-50-cm-usb-c-awg22-50-p292506.html | 2,41 € | 0 | 0,00 € | 0 | 0,00 € | powerbank - led streifen
 | usb A - usb A 1 m | https://www.reichelt.de/usb-2-0-kabel-a-stecker-auf-a-stecker-1-m-ak-670-2-1-0-efb-p227384.html | 1,29 € | 0 | 0,00 € | 0 | 0,00 € | halbiert für powerbank - led streifen | und led-streifen-controller
 | usb c - usb c 0.5m | https://www.reichelt.de/usb-2-0-kabel-c-stecker-auf-c-stecker-0-5-m-efb-usbcusb20ck5-p330175.html | 3,20 € | 0 | 0,00 € | 0 | 0,00 € | powerbank - board | half: powerbank - led streifen
 | usb c - usb c 1m | https://www.reichelt.de/usb-2-0-kabel-c-stecker-auf-c-stecker-1-0-m-efb-usbcusb20ck1-p330176.html | 3,80 € | 0 | 0,00 € | 0 | 0,00 € | halbiert für powerbank - led streifen
 | usb c - usb c 2m | https://www.reichelt.de/usb-2-0-kabel-c-stecker-auf-c-stecker-2-0-m-efb-usbcusb20ck2-p330177.html | 5,30 € | 0 | 0,00 € | 0 | 0,00 € | praktisch fürs testen
 | usb c - usb a 1.0m 3A | https://www.reichelt.de/sync-ladekabel-usb-a-usb-c-1-0m-schwarz-vt-5322-b-p287217.html | 1,65 €
 | usb c - usb a 1.8m 3A | https://www.reichelt.de/sync-ladekabel-usb-a-usb-c-8482-1-8-m-schwarz-goobay-55468-p231527.html | 3,30 €
 | usb c - usb a 2.0m 3A | https://www.reichelt.de/sync-ladekabel-usb-a-usb-c-8482-2-0-m-schwarz-goobay-59122-p215848.html | 3,59 €
 | usb c - usb a 0.2m 3A → 5X → 1,54€/stück | https://www.amazon.de/dp/B08QM7MY26 | 7,70 € | 0 | 0,00 € | 0 | 0,00 € | powerbank - controller
 | usb c - usb a 0.3m 3A → 5X → 1,6€/stück | https://www.amazon.de/dp/B08RXQJJ9Z/ | 7,99 €
 | usb c - usb a 1.8m 3A → 2X →5€/stück | https://www.amazon.de/dp/B0BPCZLFS4/ | 9,99 €
 | usb c - usb a 1-2m 3A → 4X →3,25€/stück | https://www.amazon.de/dp/B07Y2R5FDY/ | 12,99 €
 | usb c - usb a 2.0m 3A → 3X →3€/stück | https://www.amazon.de/dp/B0BRXKZYLP/ | 8,99 €
 | high side switch - AP228X4AW5-7 | https://www.mouser.de/ProductDetail/Diodes-Incorporated/AP22814BW5-7?qs=lqAf%2FiVYw9gFAqm%252B3YvdqA%3D%3D | 0,44 € | 0 | 0,00 € | 0 | 0,00 € | led strip power controll | combine with QT Py ESP32-S3 | discussion for high side switch: https://electronics.stackexchange.com/questions/664527/irlml9301pbf-as-high-side-switching-for-5-v-2-a-load-from-a-3-3-v-uc
 | 1N 4001 Gleichrichterdiode, 50 V, 1 A, DO-41 | https://www.reichelt.de/gleichrichterdiode-50-v-1-a-do-41-1n-4001-p1723.html?&trstct=pos_0&nbc=1 | 0,05 € | 0 | 0,00 € | 0 | 0,00 € | led-streifen - controller | combine with ESP32-S3 TFT reverse | to protect against reverse powering the powerbank when the controller is connected to a computer
 | SS 13ASP Schiebeschalter 1x UM, stehend, Print, RM 4,7 | https://www.reichelt.de/schiebeschalter-1x-um-stehend-print-rm-4-7-ss-13asp-p112182.html?trstct=pol_13&nbc=1 | 1,80 € | 1 | 1,80 € | 10 | 18,00 € | powerbank - controller | simple on off switch..
 | USB AWF USB-Einbaustecker, Serie A, gewinkelt, ultraflach | https://www.reichelt.de/usb-einbaustecker-serie-a-gewinkelt-ultraflach-usb-awf-p51993.html?&nbc=1 | 0,31 € | 1 | 0,31 € | 10 | 3,10 € | powerbank - controller
 | KB 1181 12MM Kupferband, glatt, 12 mm x 16,5 m | https://www.reichelt.de/kupferband-glatt-12-mm-x-16-5-m-kb-1181-12mm-p220526.html | 3,18 € | 0,2 | 0,64 € | 2 | 6,35 € | touch sensoren
gehäuse & co | Schrumpfschlauch transparent - Ø25,4mm 2:1; 5m | https://www.reichelt.de/schrumpfschlauch-box-5m-transparent-25-4mm-sdb-25-4-tr-p53815.html?trstct=pos_7&nbc=1 | 7,01 € | 0 | 0,00 € |  |  | zu groß
 | SDB 19,1 TR (5m, transparent, Ø19,1mm) | https://www.reichelt.de/schrumpfschlauch-box-5m-transparent-19-1mm-sdb-19-1-tr-p53814.html | 5,45 € | 0,08 | 0,44 €
 | holz | https://cwwh.de/ | 10,00 € | 1 | 10,00 € |  |  | TO BE DEFINED
Summe |  |  |  |  | 46,25 €

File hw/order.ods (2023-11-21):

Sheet: overview
 |  |  |  |  | . |  |  | . | bestell status |  |  |  |  |  |  |  |  |  |  |  |  |  |  |  |  |  |  |  | .
 |  |  |  |  |  |  |  |  | date |  | 21.04.23 |  | 08.05.23 |  | 08.05.23 |  | 08.05.23 |  | 30.05.23 |  | 30.05.23 |  | 06.07.23 |  | 01.08.23 |  | ??
 |  |  |  |  |  |  |  |  | shop |  | mouser.de |  | adafruit |  | smdv.de |  | reichelt.de |  | reichelt.de |  | amazon |  | Talk-Point |  | ??? |  | ???
 |  |  | ~ je TN |  |  | benötigt für WS | Für WS |  | ordered by |  | stefan |  | stefan |  | stefan |  | stefan |  | stefan |  | micha |  | stefan |  | ?? |  | ??
Bereich | Produkt | Preis | menge | preis |  | Menge | Summe |  | sum | 703,2524 |  | 83,25 € |  | 208,00 € |  | 18,00 € |  | 14,47 € |  | 48,65 € |  | 117,00 € |  | 33,88 € |  | 180,00 € |  | 0,00 € |  | comment 1 | comment 2 | shop url
 |  |  |  | 51,51 € |  | 11 TN | 577,35 € |  | offen |  | count | price | count | price | count | price | count | price | count | price | count | price | count | price | count | price | count | price |  |  |  |  | orig manufacture link
Power | PNY Tseries T2600 | 1,99 € | 1 | 1,99 € |  | 11 | 21,89 € |  | -3 |  |  |  |  |  | 2 | 12,00 € |  |  |  |  |  |  | 12 | 23,88 € |  |  |  |  |  | 101,9 mm x 24 mm x 22,3 mm | 2600mAh, microUSB, 1A | https://talk-point.de/products/10052260-0
controller | Adafruit QT Py ESP32-S3 | 14,00 € | 1 | 14,00 € |  | 11 | 154,00 € |  | -1 |  |  |  | 12 | 168,00 € |  |  |  |  |  |  |  |  |  |  |  |  |  |  |  | 8 MB Flash / No PSRAM | in stock | https://www.adafruit.com/product/5426 | https://www.adafruit.com/product/5426 | #VALUE! | 0
accel sensor | LIS3DH Triple-Axis Accelerometer | 5,53 € | 1 | 5,53 € |  | 11 | 60,87 € |  | -1 |  | 12 | 66,40 € |  |  |  |  |  |  |  |  |  |  |  |  |  |  |  |  |  | very common part →lots of tutorials |  | https://www.mouser.de/ProductDetail/485-2809
cable | STEMMA QT JST SH 4-pin Cable - 300mm | 1,40 € | 1 | 1,40 € |  | 11 | 15,45 € |  | -1 |  | 12 | 16,85 € |  |  |  |  |  |  |  |  |  |  |  |  |  |  |  |  |  | sensor - controller |  | https://www.mouser.de/ProductDetail/485-5384
cable | KUPFER 0,5MM Kupferlackdraht, Ø 0,5mm, Länge: 23M | 2,60 € | 0,04 | 0,11 € |  | 1 | 2,60 € |  | 0 |  |  |  |  |  |  |  |  |  | 1 | 2,60 € |  |  |  |  |  |  |  |  |  |  |  | https://www.reichelt.de/kupferlackdraht-0-5mm-laenge-23m-kupfer-0-5mm-p9617.html?&trstct=pol_4&nbc=1
 | LITZE SWGNRTBL Kupferlitze isoliert, 10 m, 4 x 0,25 mm² | 9,70 € | 0,02 | 0,19 € |  | 1 | 9,70 € |  | 0 |  |  |  |  |  |  |  |  |  | 1 | 9,70 € |  |  |  |  |  |  |  |  |  | verbindung controller- led-streifen |  | https://www.reichelt.de/kupferlitze-isoliert-10-m-4-x-0-25-mm-sw-gn-rt-bl-litze-swgnrtbl-p245114.html?nbc=1
mounting | SDB 19,1 TR (5m, transparent, Ø19,1mm) | 5,45 € | 0,08 | 0,44 € |  | 1 | 5,45 € |  | 0 |  |  |  |  |  |  |  |  |  | 1 | 5,45 € |  |  |  |  |  |  |  |  |  | montage & schutz led-streifen |  | https://www.reichelt.de/schrumpfschlauch-box-5m-transparent-19-1mm-sdb-19-1-tr-p53814.html
 | MPE 006-1-050 Präzisions-Sockelstreifen 2,54 mm, 50-polig | 2,79 € | 0,16 | 0,45 € |  | 2 | 5,58 € |  | 0 |  |  |  |  |  |  |  |  |  | 2 | 5,58 € |  |  |  |  |  |  |  |  |  | verbindung controller - touch stellen |  | https://www.reichelt.de/praezisions-sockelstreifen-2-54-mm-50-polig-mpe-006-1-050-p119951.html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
 | Präz.-Buchsenleisten 2,54 mm, 1X36, gerade | 2,12 € | 0,25 | 0,53 € |  | 3 | 6,36 € |  | 0 |  |  |  |  |  |  |  | 3 | 6,36 € |  |  |  |  |  |  |  |  |  |  |  | verbindung controller- led-streifen |  | https://www.reichelt.de/praez-buchsenleisten-2-54-mm-1x36-gerade-mpe-115-1-036-p119957.html
LEDs | SK9822 144LEDs/m offen | 39,00 € | 0,25 | 9,75 € |  | 2,75 | 107,25 € |  | -0,25 |  |  |  |  |  |  |  |  |  |  |  | 3 | 117,00 € |  |  |  |  |  |  |  | BTF-Lighting amazon shop - bekannt |  | https://www.amazon.de/dp/B07BPX2KFD
power | USB AWF USB-Einbaustecker, Serie A, gewinkelt, ultraflach | 0,31 € | 1 | 0,31 € |  | 11 | 3,41 € |  | -2 |  |  |  |  |  |  |  | 1 | 0,31 € | 12 | 3,72 € |  |  |  |  |  |  |  |  |  | powerbank - controller |  | https://www.reichelt.de/usb-einbaustecker-serie-a-gewinkelt-ultraflach-usb-awf-p51993.html
power | SS 13ASP Schiebeschalter 1x UM, stehend, Print, RM 4,7 | 1,80 € | 1 | 1,80 € |  | 11 | 19,80 € |  | -2 |  |  |  |  |  |  |  | 1 | 1,80 € | 12 | 21,60 € |  |  |  |  |  |  |  |  |  | sytem power |  | https://www.reichelt.de/schiebeschalter-1x-um-stehend-print-rm-4-7-ss-13asp-p112182.html?trstct=pol_13&nbc=1
gehäuse | holz gehäuse | 15,00 € | 1 | 15,00 € |  | 11 | 165,00 € |  | -1 |  |  |  |  |  |  |  |  |  |  |  |  |  |  |  | 12 | 180,00 € |  |  |  | Bestellt Stefan - fertigungs Kapazitäten sind bestätigt. | CWWH: pers. Kontakt | https://cwwh.de/
sonstiges
versand |  |  |  |  |  |  |  |  |  |  | 0 | 0,00 € | 1 | 20,00 € | 1 | 6,00 € | 1 | 6,00 € | 1 |  | 1 | 0,00 € | 1 | 10,00 € | 1 | 0,00 € | 1 | 0,00 €
extras
Zoll |  |  |  |  |  |  |  |  |  |  | 0 | 0,00 € | 1 | 20,00 € | 0 | 0,00 € | 0 | 0,00 € | 0 | 0,00 € | 0 | 0,00 € | 0 | 0 | 0,00 € | 0 | 0,00 € | 0

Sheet: mail
Produkt | Preis | Menge | comment 1 | shop url
 |  | 12 |  |  | orig manufacture link
RealPower PB-Lipstick Powerbank 2500 mAh Li-Ion Grün | 5,48 € | 10 | 93 mm x 22 mm x 22 mm | https://www.smdv.de/products/869639/RealPower-PB-Lipstick-Powerbank-2500-mAh-Li-Ion-Gruen.html
KUPFER 0,5MM Kupferlackdraht, Ø 0,5mm, Länge: 23M | 2,60 € | 1 |  | https://www.reichelt.de/kupferlackdraht-0-5mm-laenge-23m-kupfer-0-5mm-p9617.html?&trstct=pol_4&nbc=1
LITZE SWGNRTBL Kupferlitze isoliert, 10 m, 4 x 0,25 mm², sw/gn/rt/bl | 9,70 € | 1 | verbindung controller- led-streifen | https://www.reichelt.de/kupferlitze-isoliert-10-m-4-x-0-25-mm-sw-gn-rt-bl-litze-swgnrtbl-p245114.html?nbc=1
MPE 006-1-050 Präzisions-Sockelstreifen 2,54 mm, 50-polig | 2,79 € | 1 | verbindung controller - touch stellen | https://www.reichelt.de/praezisions-sockelstreifen-2-54-mm-50-polig-mpe-006-1-050-p119951.html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
SDB 19,1 TR (5m, transparent, Ø19,1mm) | 5,45 € | 1 | mounting led-streifen | https://www.reichelt.de/schrumpfschlauch-box-5m-transparent-19-1mm-sdb-19-1-tr-p53814.html
SK9822 144LEDs/m offen | 39,00 € | 0 | BTF-Lighting amazon shop - hier hab ich schon mal bestellt.. | https://www.amazon.de/dp/B07BPX2KFD
SK9822 144LEDs/m offen | 27,50 € | 3 | unbekannter amazon shop | https://www.amazon.de/dp/B0BYSHDDWT
USB AWF USB-Einbaustecker, Serie A, gewinkelt, ultraflach | 0,31 € | 12 | powerbank - controller | https://www.reichelt.de/usb-einbaustecker-serie-a-gewinkelt-ultraflach-usb-awf-p51993.html
SS 13ASP Schiebeschalter 1x UM, stehend, Print, RM 4,7 | 1,80 € | 12 | sytem power | https://www.reichelt.de/schiebeschalter-1x-um-stehend-print-rm-4-7-ss-13asp-p112182.html
holz gehäuse | 10,00 € | 12 | Bestellt Stefan - fertigungs Kapazitäten sind schon angefragt und bestätigt. CWWH: persönllicher Kontakt | https://cwwh.de/

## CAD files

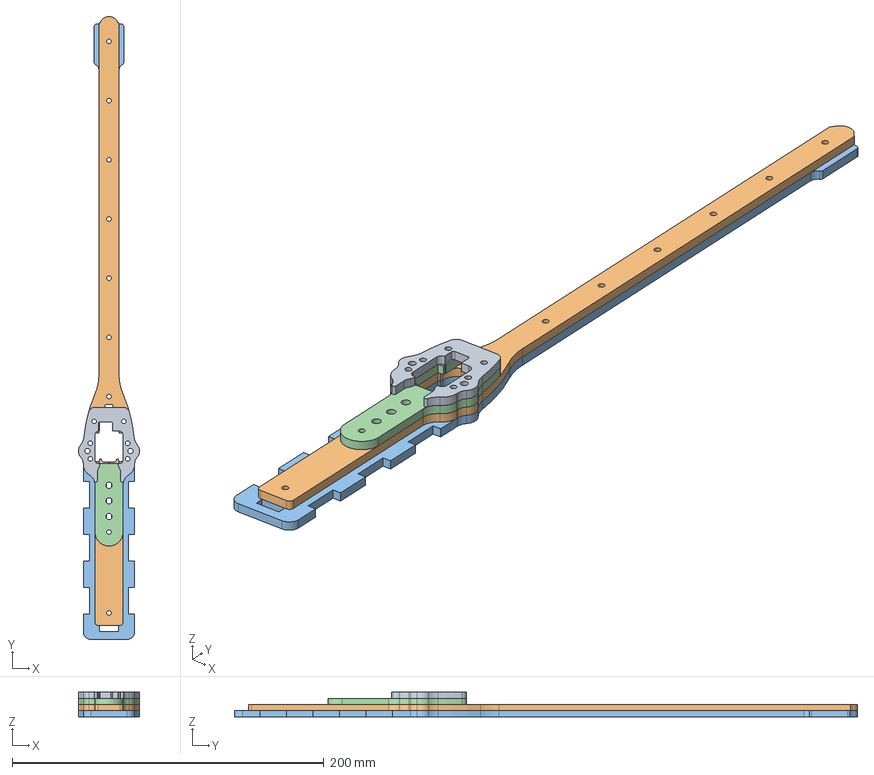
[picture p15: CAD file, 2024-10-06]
hw/case/export/case_assembly__layer-2-101.step
39.3 x 400.0 x 16.0 mm
case_layer_-2
case_layer_0
case_layer_1
case_layer_-1

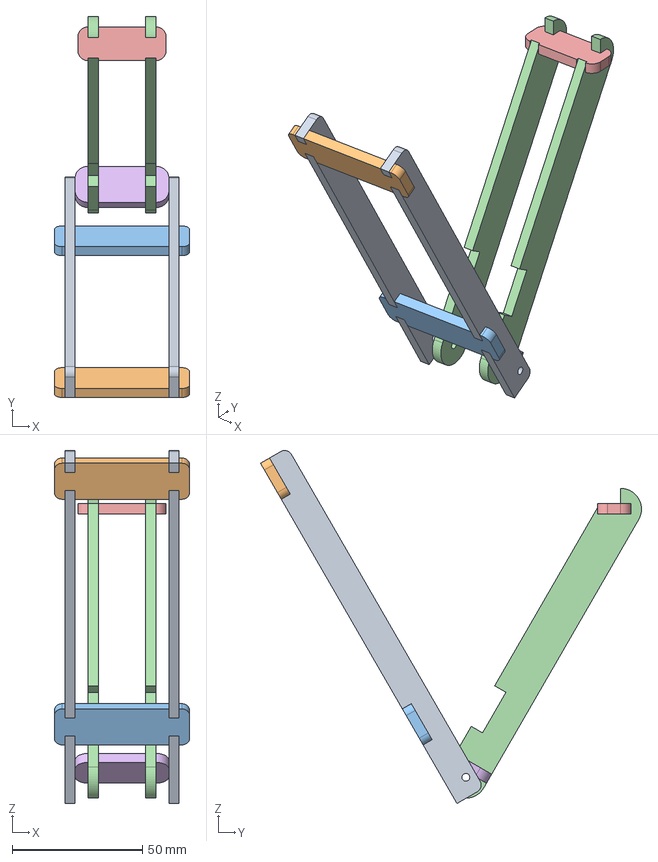
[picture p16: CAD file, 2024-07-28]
hw/case/case_assembly.FCStd
52.0 x 146.4 x 135.7 mm
bottom_join_Body x 2
bottom_front_Body
bottom_back_Body
top_attach_Body x 2
top_attach_bar_Body
top_attach_bar_bottom_body

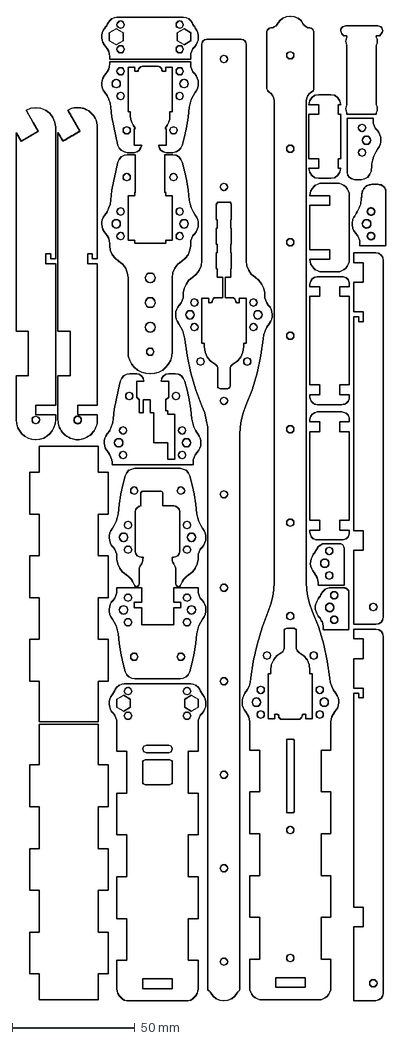
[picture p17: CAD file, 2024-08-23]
hw/case/export/case_parts_4mm.dxf
150.3 x 400.5 mm

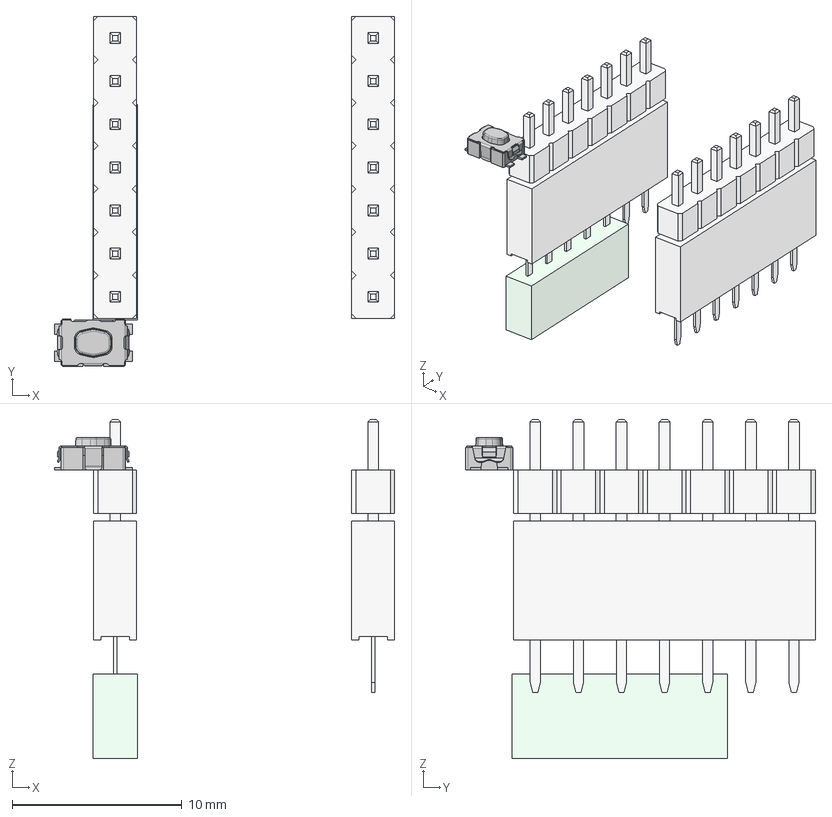
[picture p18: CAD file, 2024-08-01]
hw/case/QT Py ESP32-S3.FCStd
20.1 x 20.6 x 20.0 mm
0805-NO
BTN_KMR2_4.6X2.8
SOD-323_MINI
PinHeader_1x07_P254mm_Vertical x 2
PinSocket_1x07_P254mm_Vertical x 2

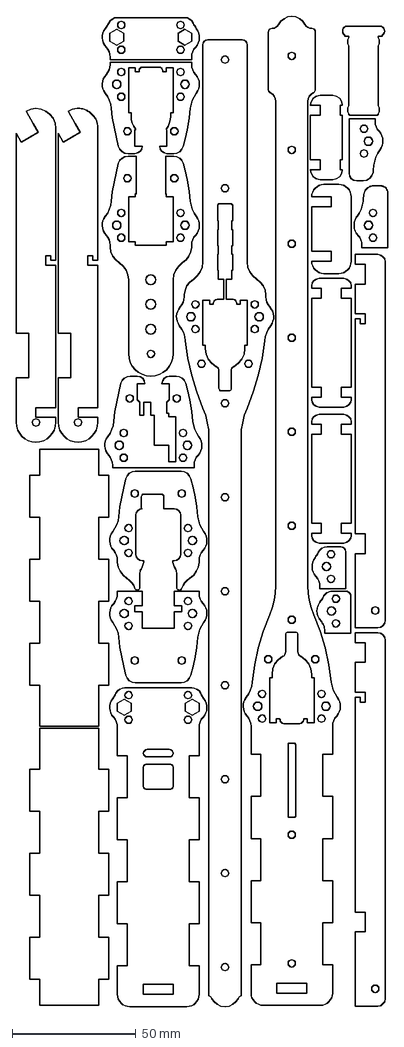
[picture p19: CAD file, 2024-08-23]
hw/case/export/case_parts_4mm_manual_cleaned.dxf
150.3 x 400.5 mm

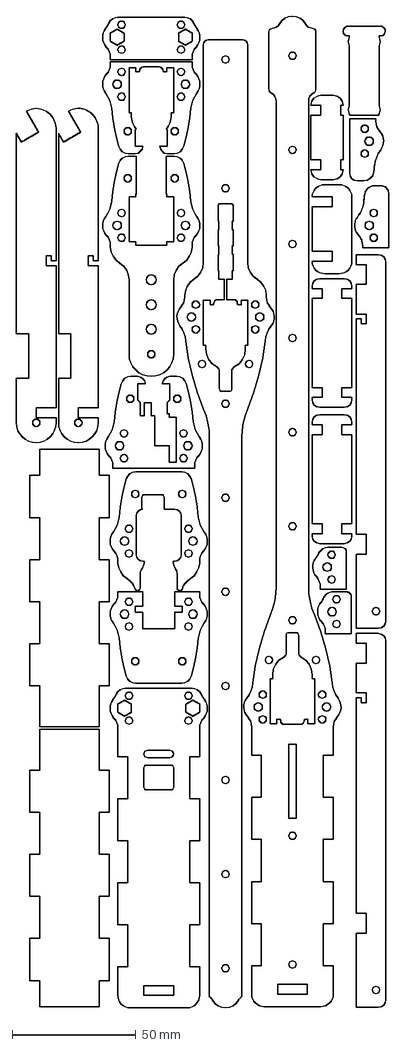
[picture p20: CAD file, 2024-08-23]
hw/case/export/case_parts_4mm_manual_cleaned freecad.dxf
150.3 x 400.5 mm

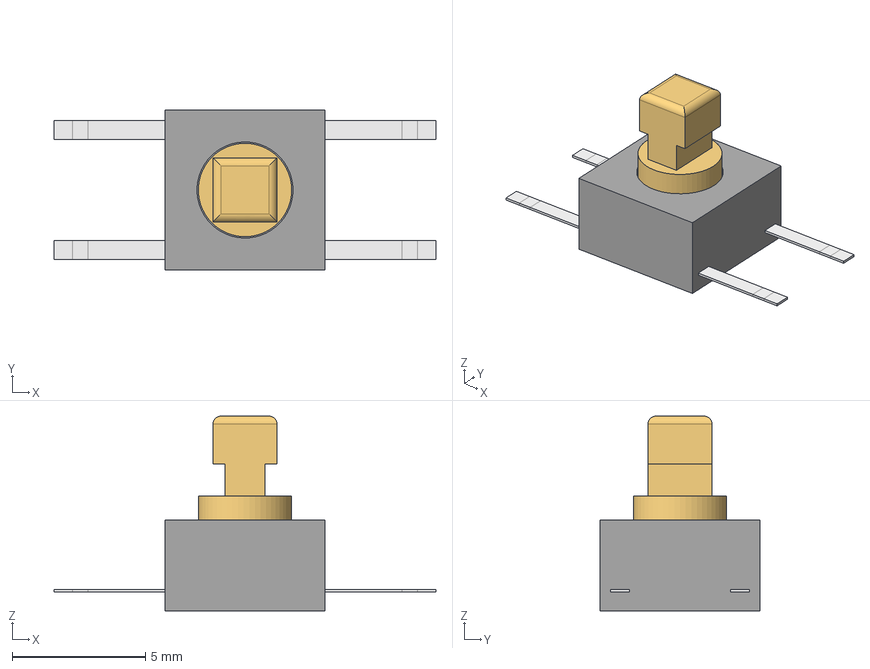
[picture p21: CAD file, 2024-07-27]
hw/case/OMRON_BF3-105x.FCStd
14.3 x 6.00 x 7.30 mm
plastic_body
plunger
pin_12_flat
pin_34_flat

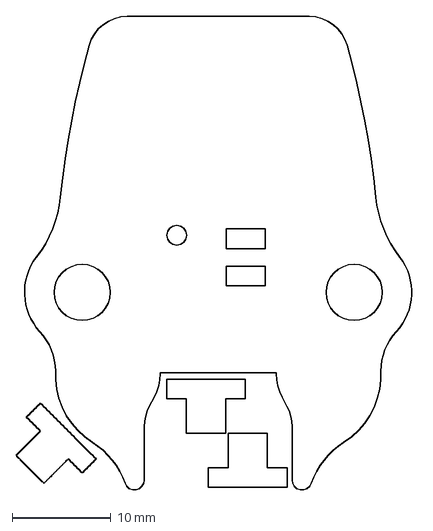
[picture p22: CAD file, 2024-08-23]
hw/case/export/case_parts_2mm_Birke4Schicht.dxf
40.7 x 48.1 mm

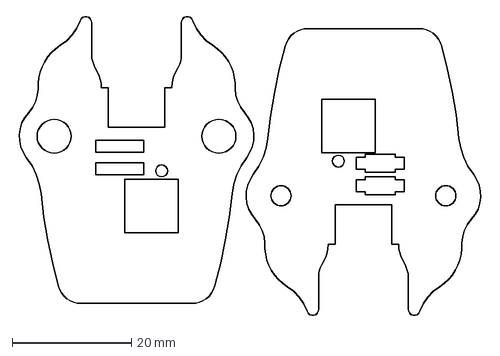
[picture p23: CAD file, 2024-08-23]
hw/case/export/case_parts_1,5mm_Kraftplex.dxf
78.4 x 50.2 mm

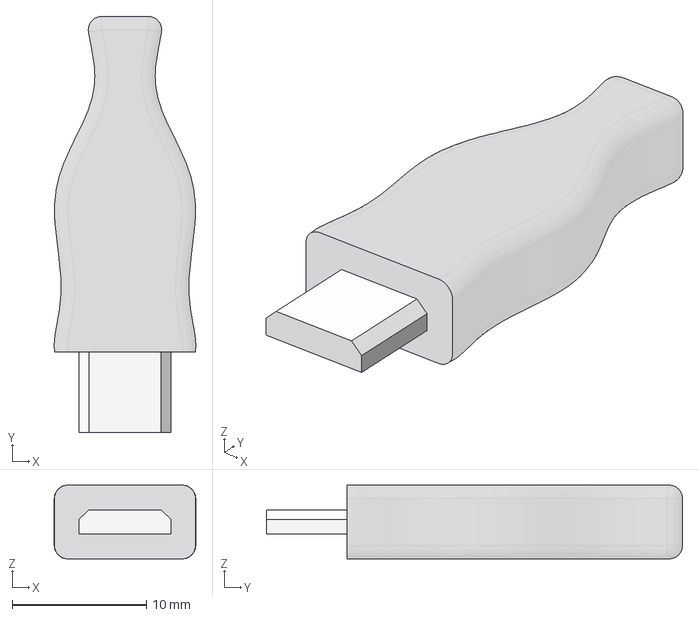
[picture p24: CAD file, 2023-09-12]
hw/case/microUSB_cable.FCStd
10.6 x 31.0 x 5.50 mm
plug_metal
plug_plastic

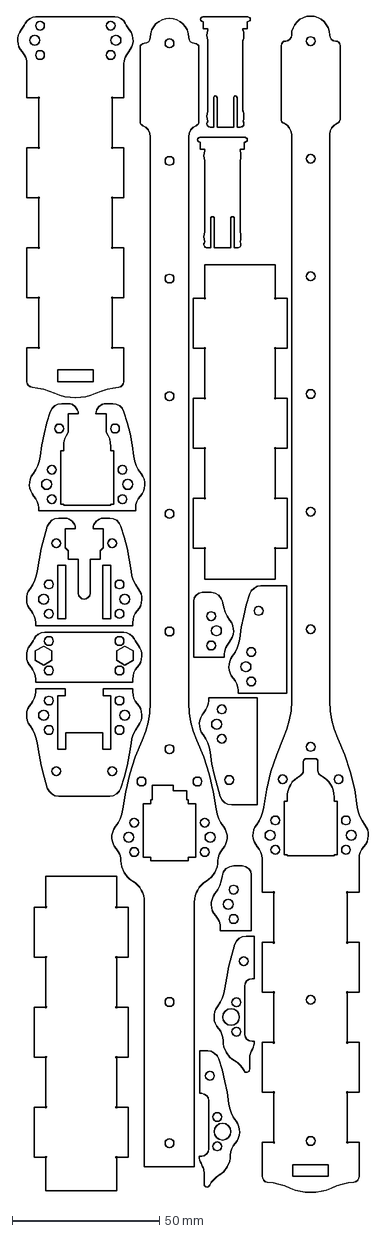
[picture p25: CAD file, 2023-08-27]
hw/case/export/case_parts_mod__test__R14.dxf
120.3 x 400.5 mm

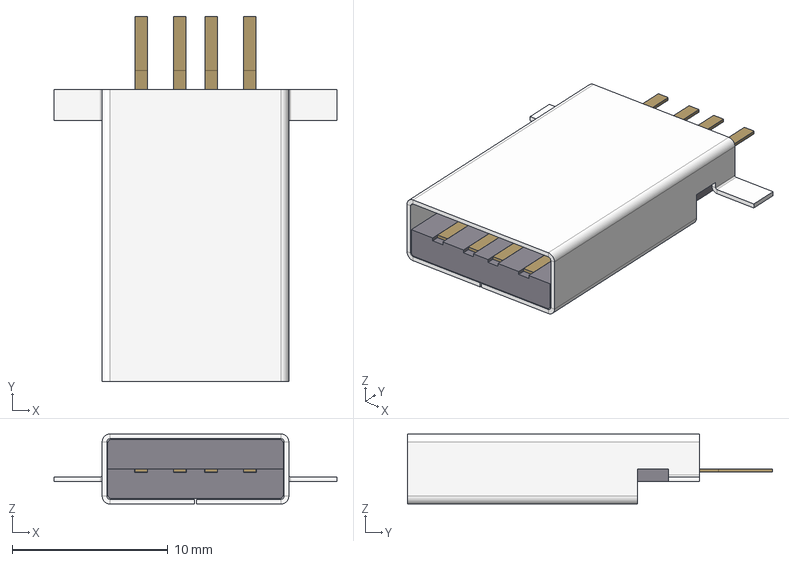
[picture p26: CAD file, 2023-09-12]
hw/case/usb_plug__mod.FCStd
18.2 x 23.5 x 4.50 mm
pin_Body x 4
fill_Body

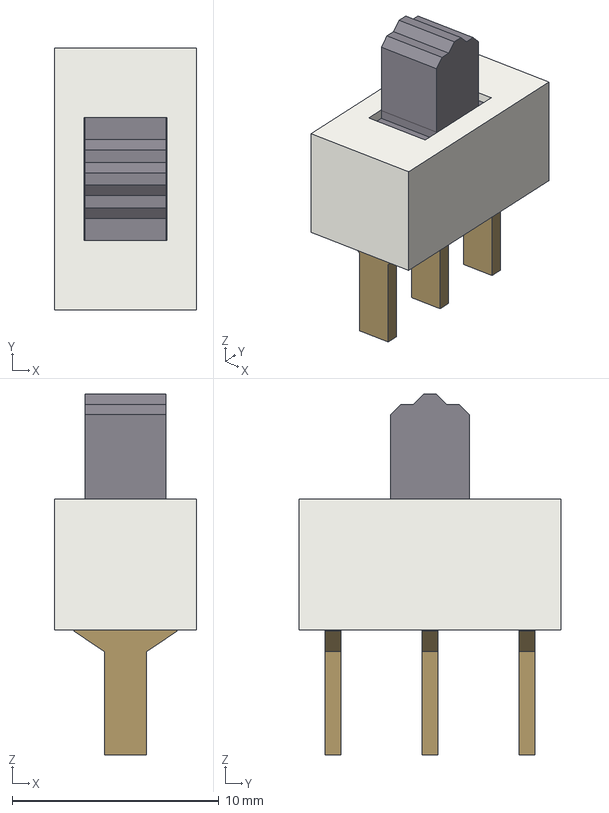
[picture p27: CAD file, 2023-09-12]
hw/case/slide_switch.FCStd
6.90 x 12.7 x 17.5 mm
pin x 3
actuator

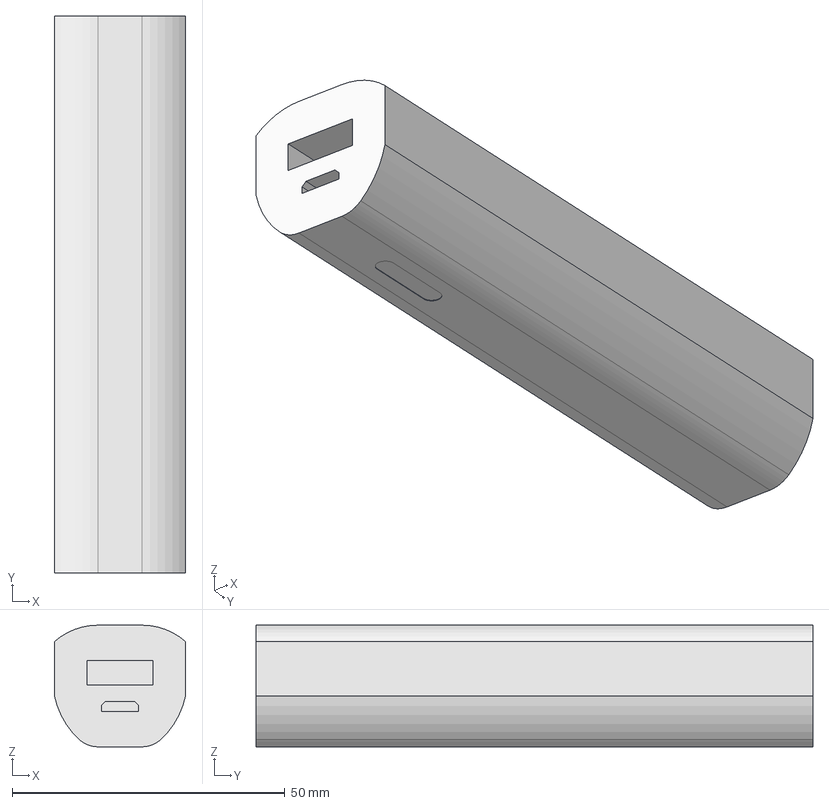
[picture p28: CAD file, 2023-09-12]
hw/case/powerbank.FCStd
24.0 x 102.0 x 22.3 mm

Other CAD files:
hw/case/case_assembly_drawings.FCStd
hw/case/case_drawings.FCStd
hw/shrinktube_check.FCStd
hw/case/led_strip.FCStd
hw/case/LIS3DH.FCStd
hw/case/case.FCStd
hw/case/cross-curve-test.FCStd
hw/case/test_LC_Interlock.FCStd
hw/case/usb_plug__original.FCStd

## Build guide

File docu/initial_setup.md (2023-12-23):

# Py QT esp32-s3 board setup

```bash
cd /circuitpython/tinyuf2-adafruit_qtpy_esp32s3-0.16.0
$ rsync esptool.py --port /dev/ttyACM0 write_flash 0x0 combined.bin 
esptool.py v4.6.2
Serial port /dev/ttyACM0
Connecting...
Detecting chip type... ESP32-S3
Chip is ESP32-S3 (revision v0.1)
Features: WiFi, BLE
Crystal is 40MHz
MAC: f4:12:fa:8d:98:88
Uploading stub...
Running stub...
Stub running...
Configuring flash size...
Flash will be erased from 0x00000000 to 0x0043afff...
Compressed 4433760 bytes to 131067...
Wrote 4433760 bytes (131067 compressed) at 0x00000000 in 12.5 seconds (effective 2834.0 kbit/s)...
Hash of data verified.

Leaving...
Hard resetting via RTS pin...
$ 
$ rsync -r --info=progress2 --info=name0  ../adafruit-circuitpython-adafruit_qtpy_esp32s3_nopsram-en_GB-8.2.6.uf2 /media/$USER/QTPYS3BOOT/
      2.809.856 100%  313,56kB/s    0:00:08 (xfr#1, to-chk=0/1)
$ rsync rsync -r --info=progress2 --info=name0 --exclude '/tests' ~/mydata/github/cp_magic_painter/fw/* /media/$USER/CIRCUITPY/
rsync: [Receiver] mkdir "/media/$USER/CIRCUITPY" failed: Permission denied (13)
rsync error: error in file IO (code 11) at main.c(791) [Receiver=3.2.7]
$ rsync -r --info=progress2 --info=name0 --exclude '/tests' ~/mydata/github/cp_magic_painter/fw/* /media/$USER/CIRCUITPY/
rsync: [Receiver] change_dir#1 "/media/$USER/CIRCUITPY/" failed: Permission denied (13)
rsync error: errors selecting input/output files, dirs (code 3) at main.c(751) [Receiver=3.2.7]
$ rsync -r --info=progress2 --info=name0 --exclude '/tests' ~/mydata/github/cp_magic_painter/fw/* /media/$USER/CIRCUITPY/
        176.743 100%   12,28kB/s    0:00:13 (xfr#56, to-chk=0/67) 
$ rsync rm /media/$USER/CIRCUITPY/code.py 
$ sync
$ 
```

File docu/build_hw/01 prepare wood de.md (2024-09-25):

# Holz Zusammenbauen

<style>
    html, body {
        background: hsl(270,100%,10%);
        color: hsl(40, 100%, 50%);
        font-size: 1.2em;
    }
    img {
        max-width: 90vw;
        max-height: 60vh;
    }
</style>

## Holz Vorbereitung

bausatz

alle einzelteile vorbereitet

### Positionierungsstifte

Dann die Positionierung-Stifte vorbereiten.
die länge lässt sich mit dem Seitenschneider am besten an den Holz-Schichten abmessen und direkt schneiden.
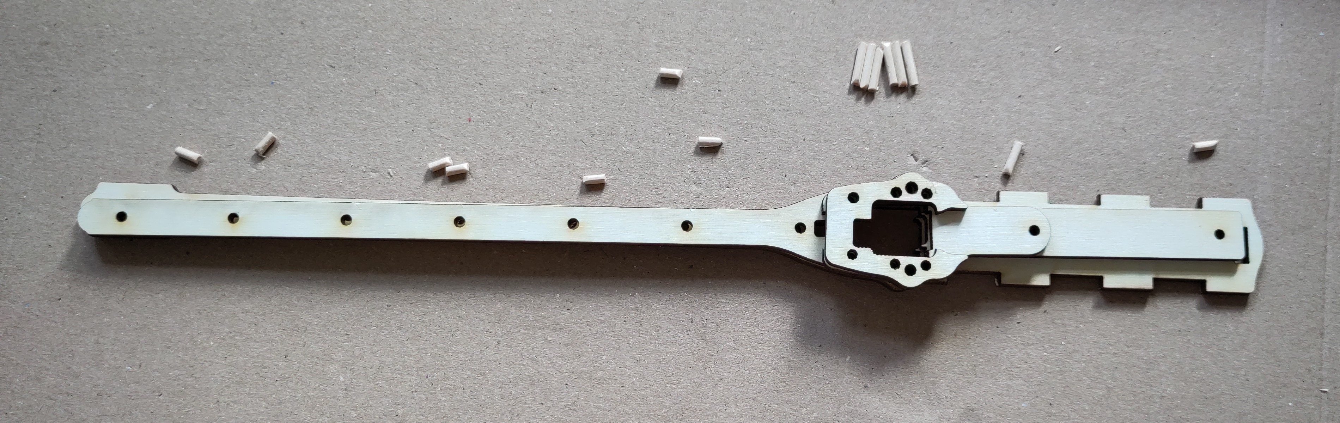
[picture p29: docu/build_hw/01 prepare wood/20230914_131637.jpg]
Positionierungsstifte


## oben

nun die oberen Teile Zusammenleimen

> WICHTIG:
> Layer 1 & 2 werden miteinander verleimt.
> und Layer 3 & 4 werden miteinader verleimt.
> Allerdings möchten die Positionierungsstifte durch alle 4 Durchgehen..

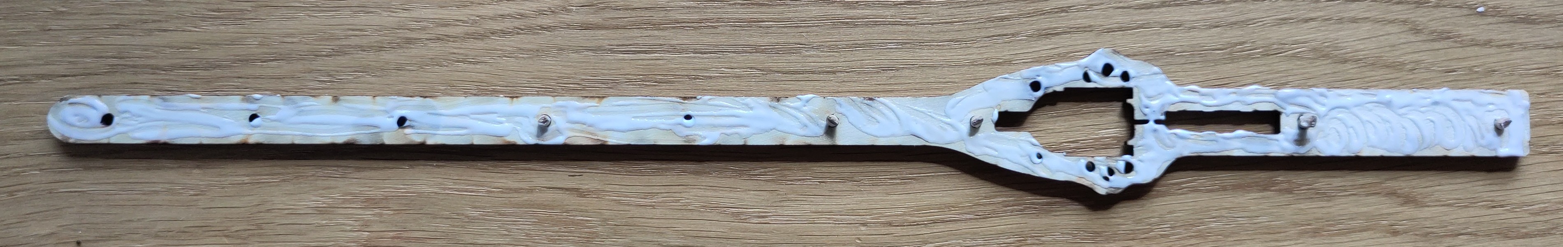
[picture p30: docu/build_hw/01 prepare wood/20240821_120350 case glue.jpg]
prepare wood - top layer glueing

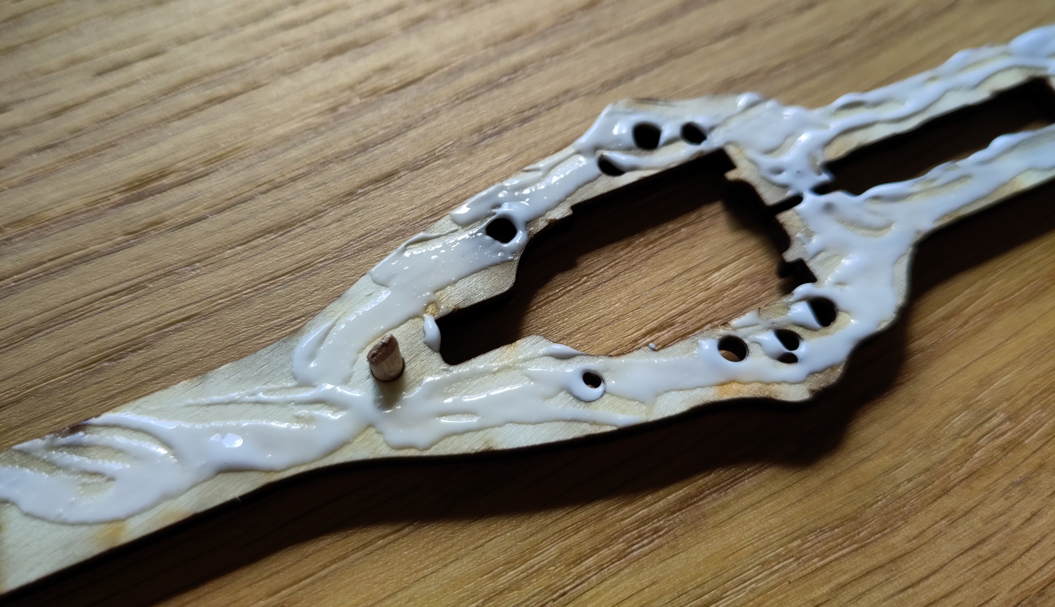
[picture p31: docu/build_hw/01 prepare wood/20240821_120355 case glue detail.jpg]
prepare wood - top layer glueing

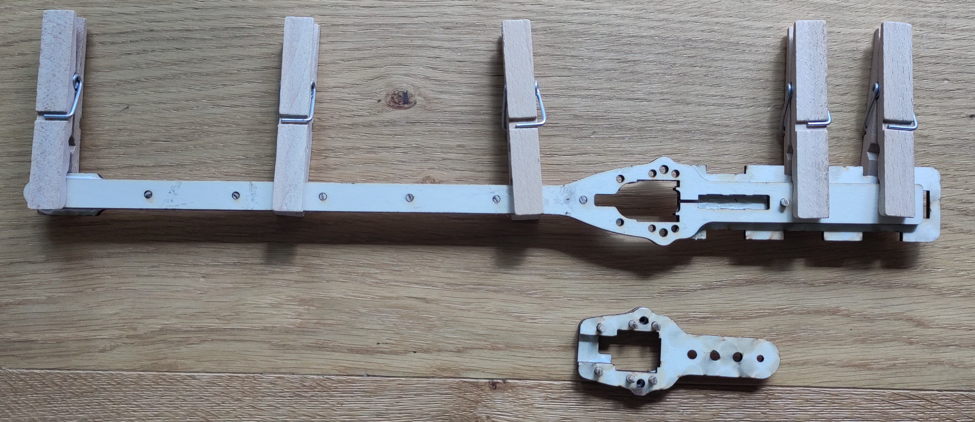
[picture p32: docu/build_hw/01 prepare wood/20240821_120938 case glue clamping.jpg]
prepare wood - top layer glueing


### unten

dann das gleiche spiel mit den unteren teilen
(drei layer)

untere Teile Leimen

### USB-Slide-In

hier werden wieder die jeweiligen zwei Layer mit einander verleimt -
die unteren beiden Layer und die Oberen beiden Layer.
diese beiden _Pakete_ werden dann später nur auf die Stifte aufgesteckt.

einschub

#### obere layer

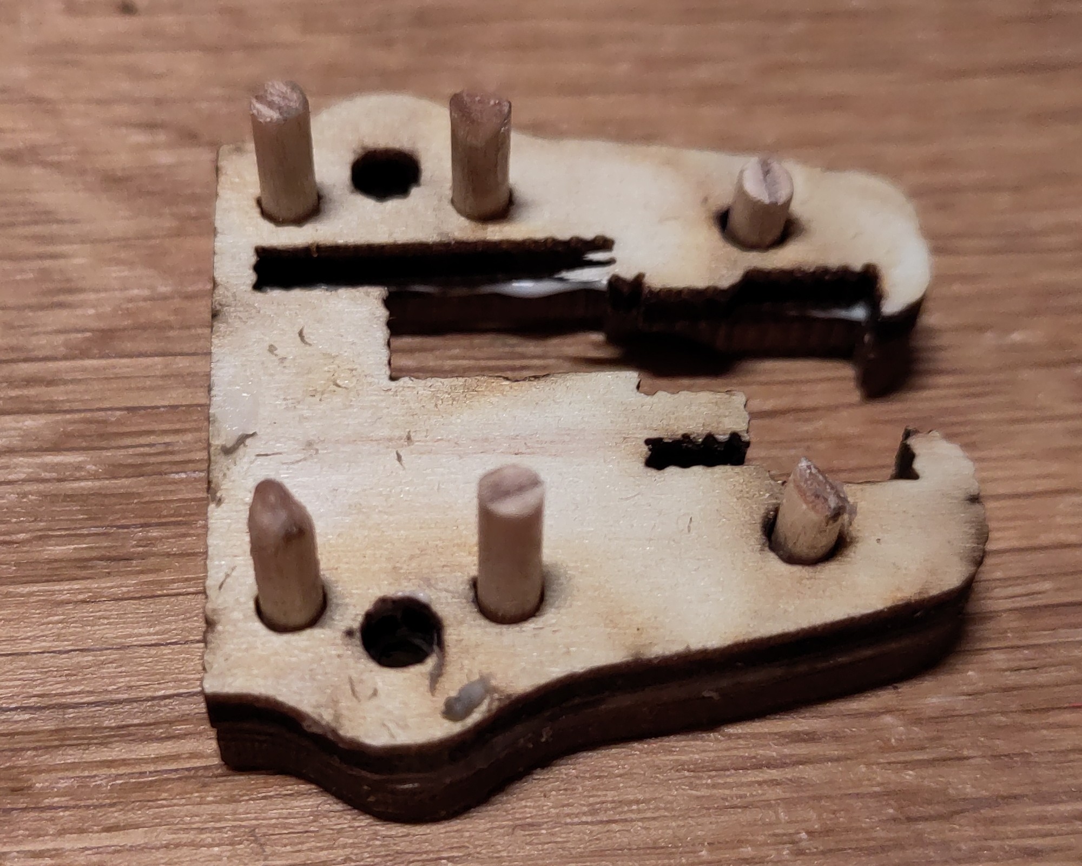
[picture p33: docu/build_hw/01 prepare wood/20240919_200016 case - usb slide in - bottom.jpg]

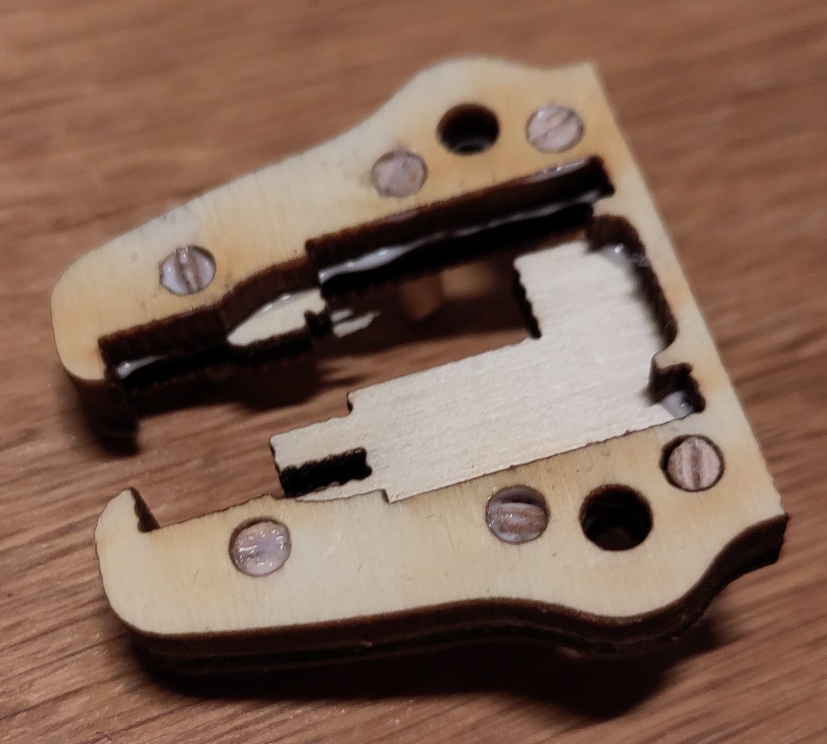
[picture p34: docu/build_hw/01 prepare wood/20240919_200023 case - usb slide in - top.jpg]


#### untere layer

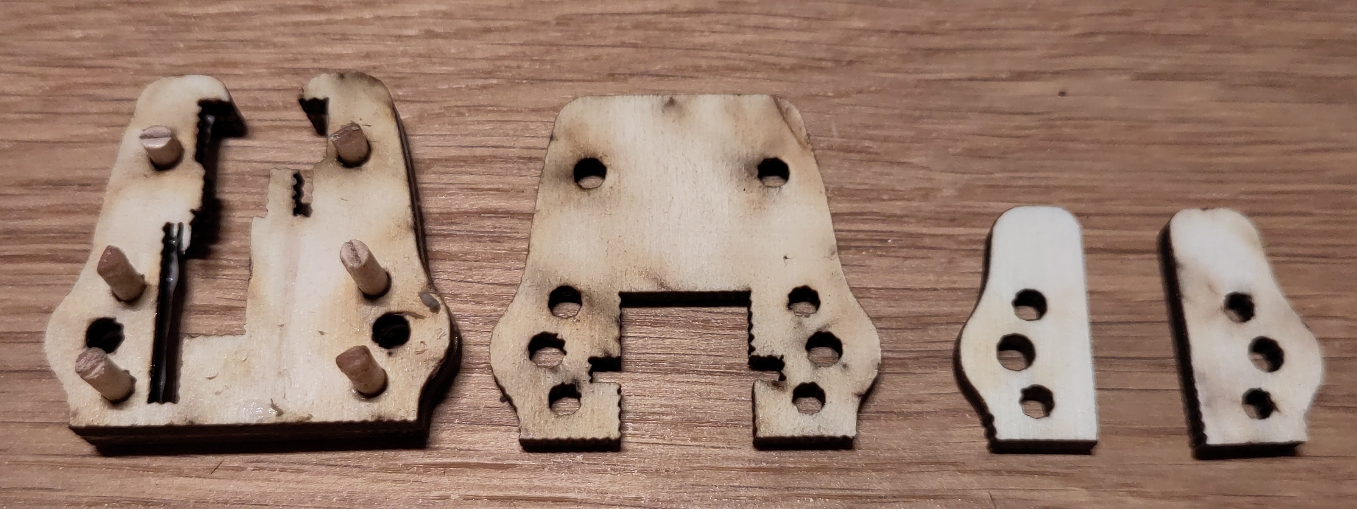
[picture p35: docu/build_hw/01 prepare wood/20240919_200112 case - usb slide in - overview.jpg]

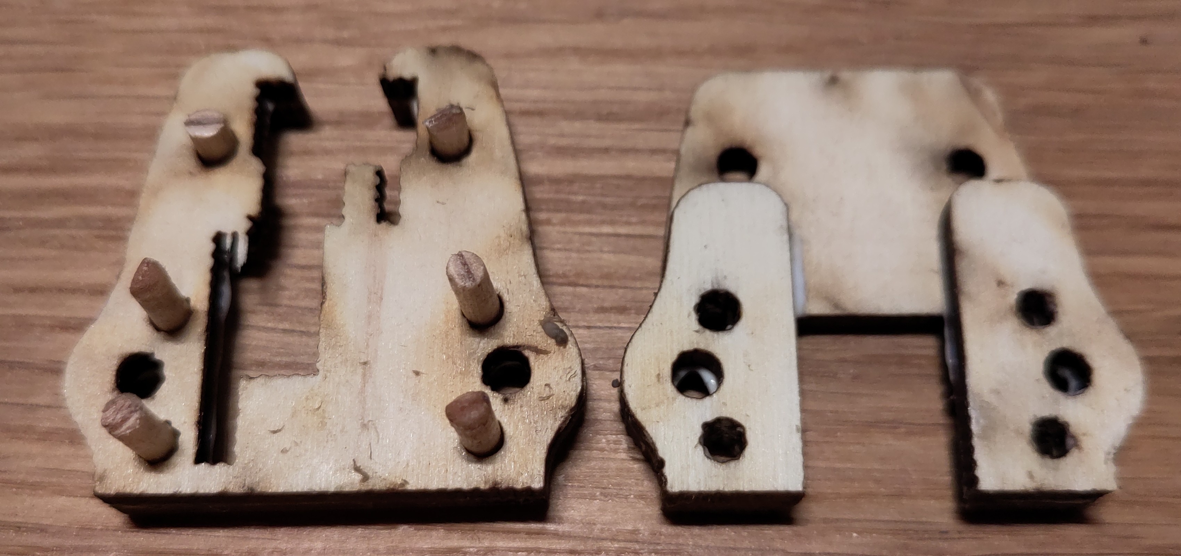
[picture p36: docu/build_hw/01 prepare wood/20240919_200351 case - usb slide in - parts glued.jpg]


### zwischenstand

zwischenstand

### box

wenn die oberen und unteren teile fest sind kommt als letzter schritt die box:

vorbereitung box

mit hilfe der gummies auch die box leimen
hier darauf achten das diese rechtwinkelig ist.
box leimen

### Cover

> Falls Vorhanden

als letztes noch die _cover-layer_ miteinander verleimen..
dabei sehr sehr sorgfältig arbeiten so das die Holz-Stößel sich frei bewegen können...
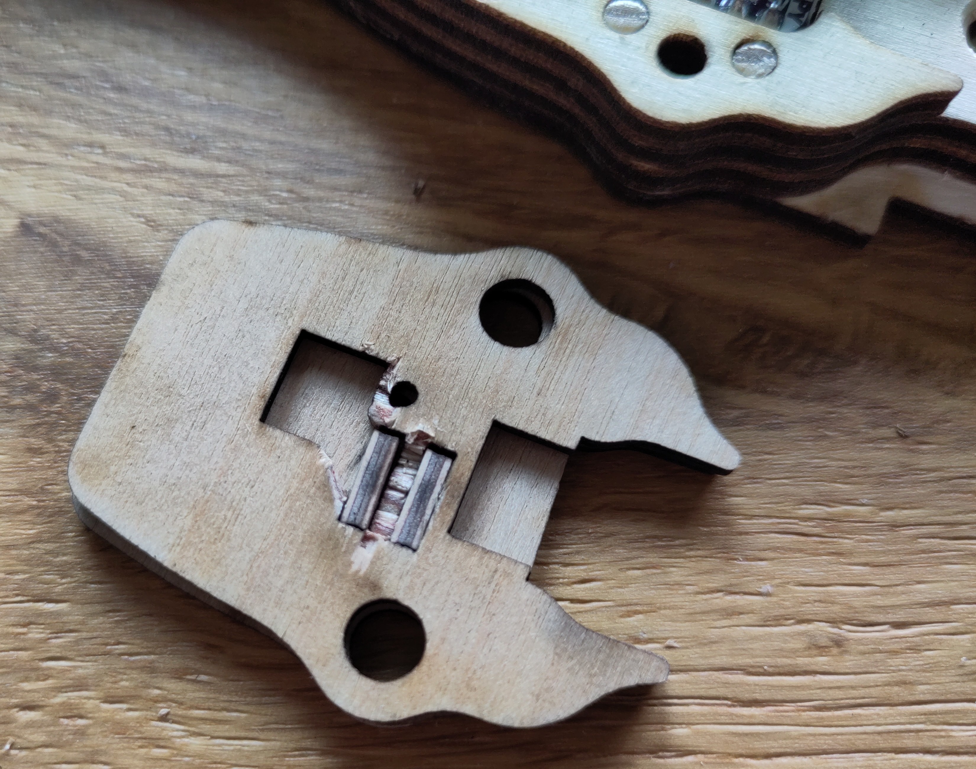
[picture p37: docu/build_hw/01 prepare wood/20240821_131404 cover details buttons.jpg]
prepare wood -

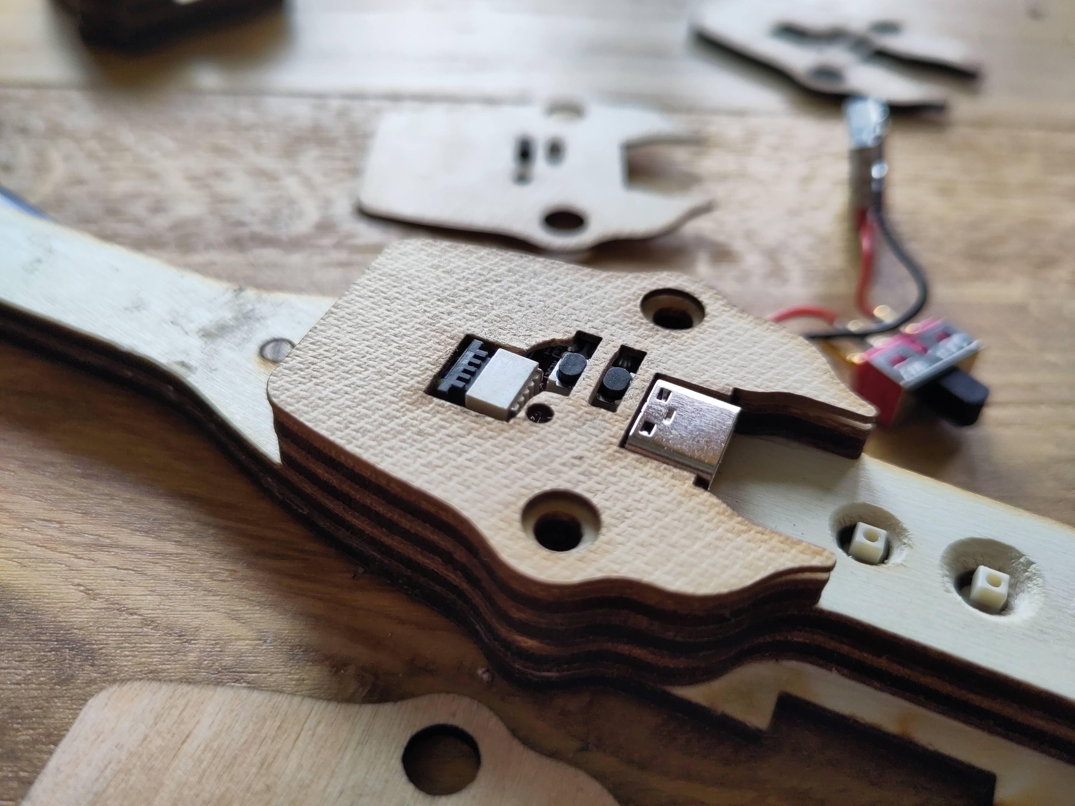
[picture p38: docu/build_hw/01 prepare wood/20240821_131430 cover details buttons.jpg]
prepare wood -


## Weiter
weiter mit [03 test electronics - de]()

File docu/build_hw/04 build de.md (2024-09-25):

# Zusammenbauen

<style>
    html, body {
        background: hsl(270,100%,10%);
        color: hsl(40, 100%, 50%);
        font-size: 1.2em;
    }
    img {
        max-width: 90vw;
        max-height: 60vh;
    }
</style>

# zusammen bauen Teil1

ein Stück Schrumpfschlauch auf Länge schneiden und bereit legen

## LED-streifen

als erstes den LED-Streifen so positionieren das alle LEDs herausschauen und dieser gut auf dem Holz aufliegt.
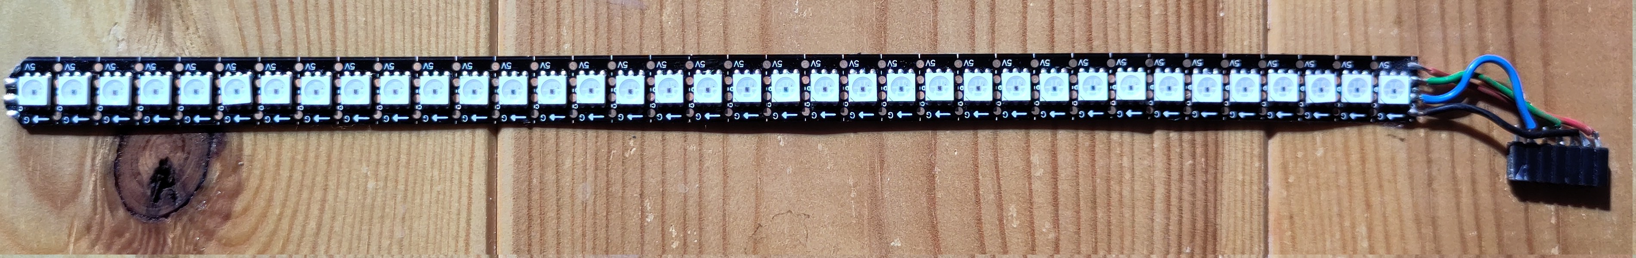
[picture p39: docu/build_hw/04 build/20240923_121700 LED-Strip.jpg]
LED-Strip

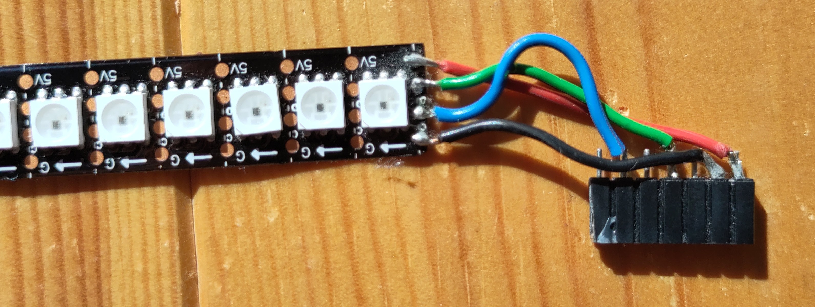
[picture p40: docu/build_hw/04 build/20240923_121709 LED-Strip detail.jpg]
LED-Strip detail


falls die oberen Beiden Layer fest verleimt sind muss der LED-Streifen durchgeschoben werden:
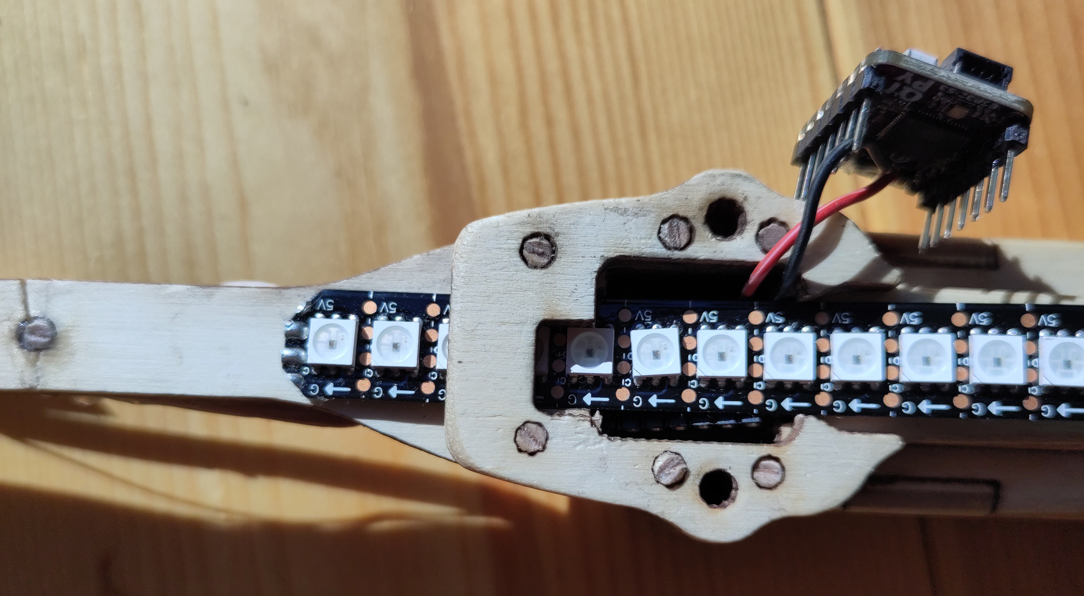
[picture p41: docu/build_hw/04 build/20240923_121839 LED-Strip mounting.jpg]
mounting if glued


## Buttons

die Buttons in die Aussparung im Gehäuse legen und dann die obersten beiden Layer zusammen stecken.

## Sensor

die Sensor Platine von Unten auf dem oberen Ende des Stabes positionieren -
eventuell mit etwas Kleber dort fixieren.
das Kabel am Stab entlang durch das Loch nach oben führen (siehe auch nächstes Bild)

## Oberer Stab fertig Vorbereitet

Das ganze sollte nun so in etwa Ausschauen:
build

zum Schluss alle steck-elemente nach oben führen
alle steck-elemente nach oben führen

# zusammen bauen Teil2

nun werden wir den USB-Stecker und Power-Schalter im Mittleren Holz-Stück befestigen.
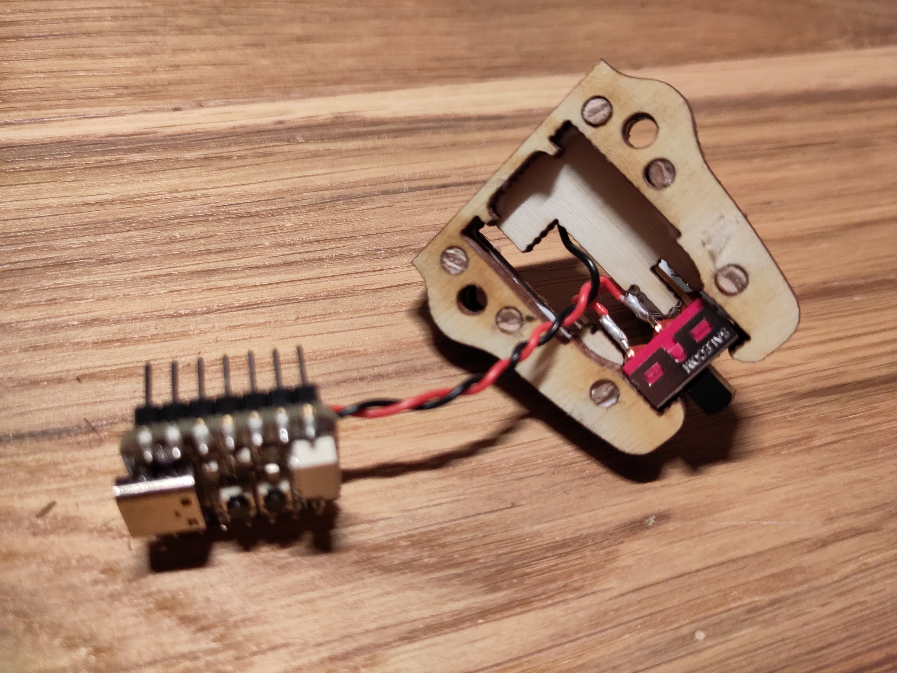
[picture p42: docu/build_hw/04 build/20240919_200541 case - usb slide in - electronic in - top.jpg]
usb slide-in mounting

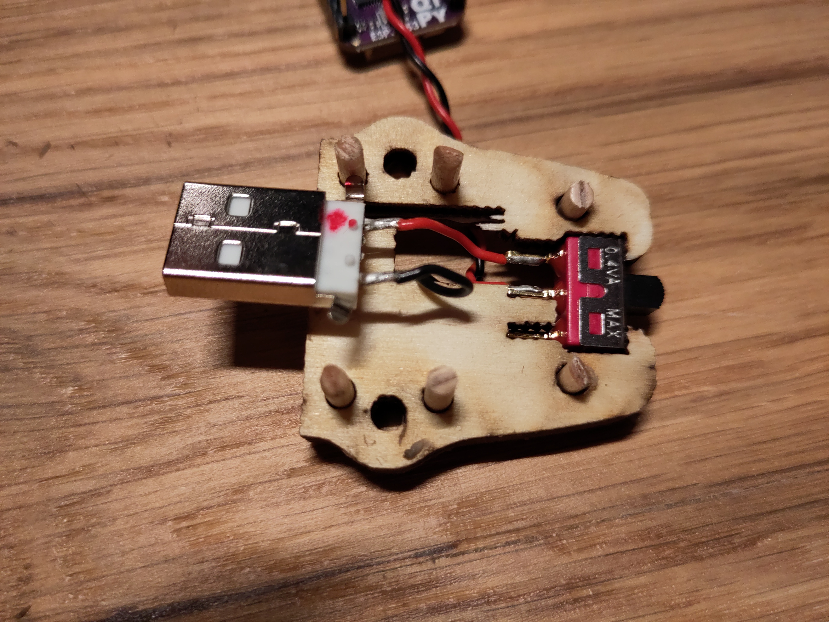
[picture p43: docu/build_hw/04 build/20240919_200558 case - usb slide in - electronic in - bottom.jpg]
usb slide-in mounting

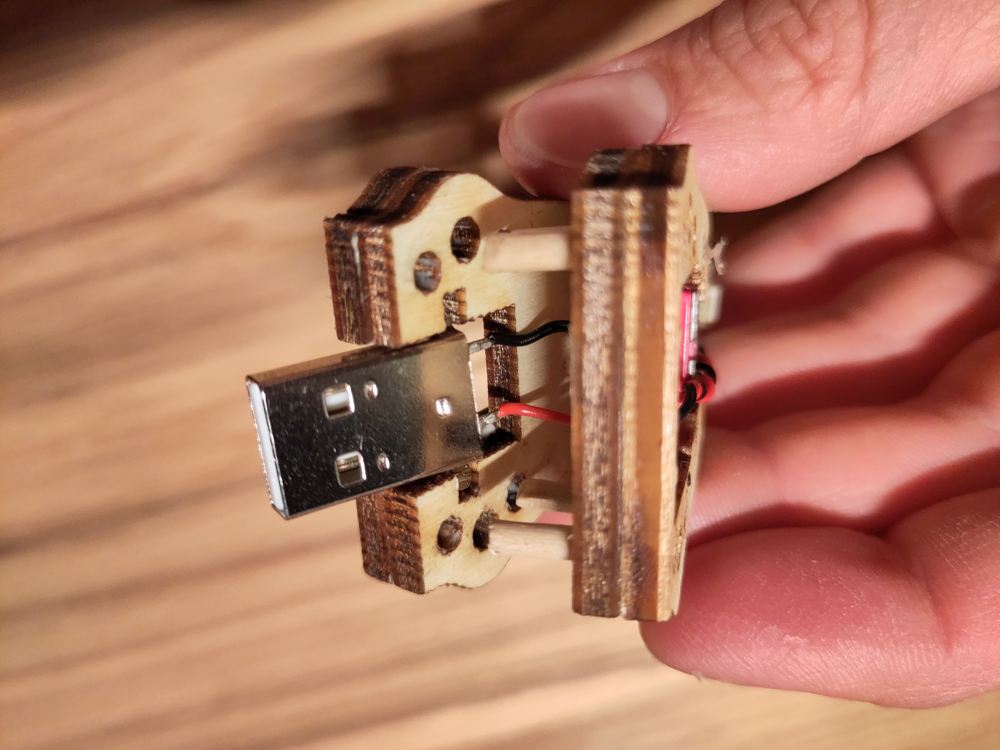
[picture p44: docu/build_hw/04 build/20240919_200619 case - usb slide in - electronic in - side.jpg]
usb slide-in mounting

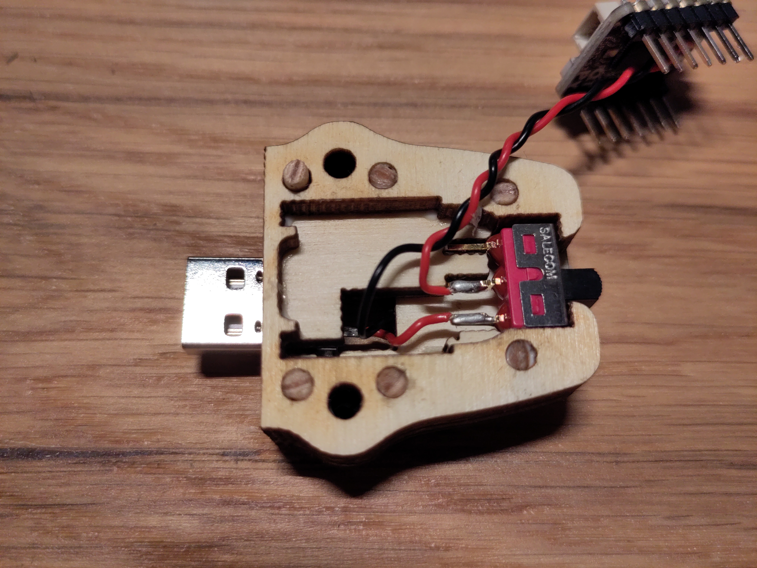
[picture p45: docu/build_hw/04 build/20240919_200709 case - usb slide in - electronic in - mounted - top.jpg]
usb slide-in mounting

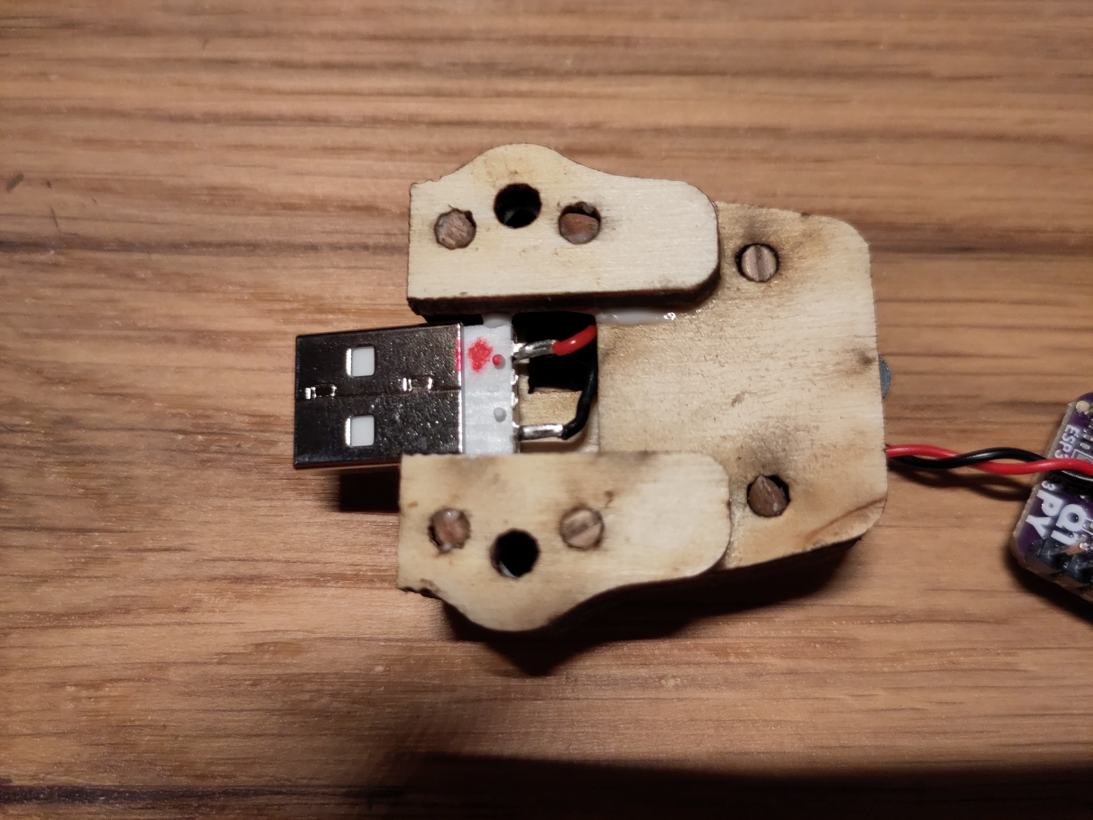
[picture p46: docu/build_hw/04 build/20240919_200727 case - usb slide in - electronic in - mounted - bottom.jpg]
usb slide-in mounting


# zusammen bauen Teil3

nun wird alles vereint

als erstes den controller vorsichtig hindurch fädeln
controller einbau

controller fertig durchgefädelt
controller fertig durchgefädelt

nun die steckverbindungen wieder achtsam zusammenfügen.
fertig
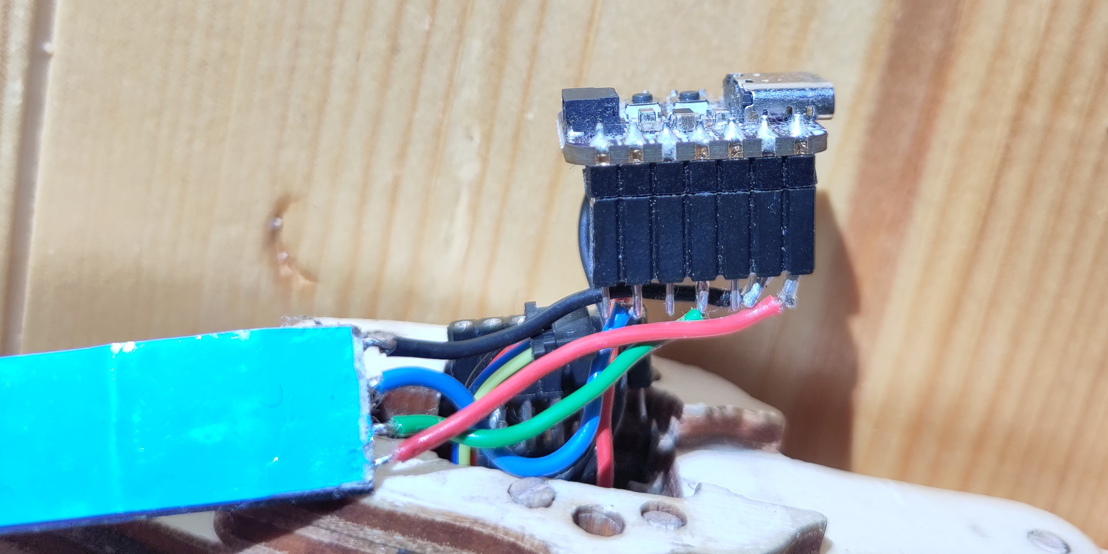
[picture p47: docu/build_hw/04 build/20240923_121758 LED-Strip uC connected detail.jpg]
LED-Strip connected

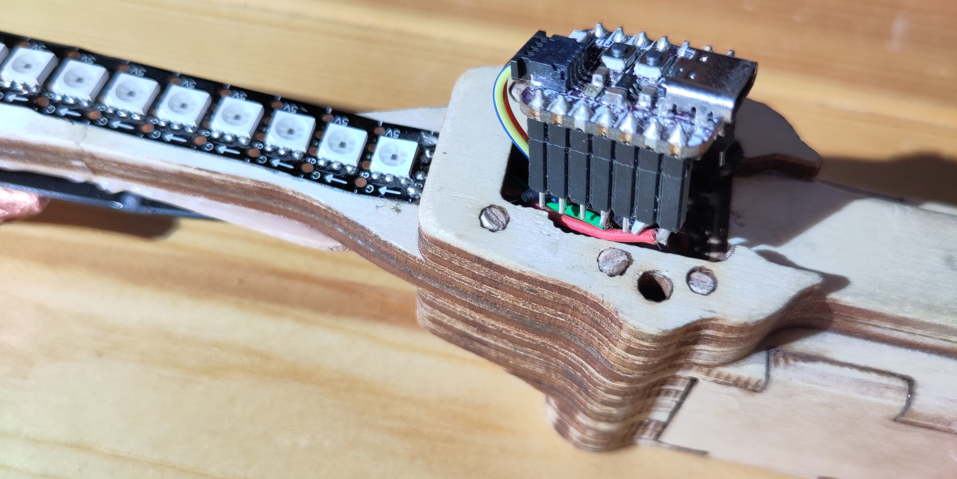
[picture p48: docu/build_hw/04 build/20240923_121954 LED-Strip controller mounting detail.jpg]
controller mounting


und dann den controller vorsichtig in den stab drücken
(am besten auf der USB-Buchse und gleichzeitig auf dem Sensor-Anschluss)
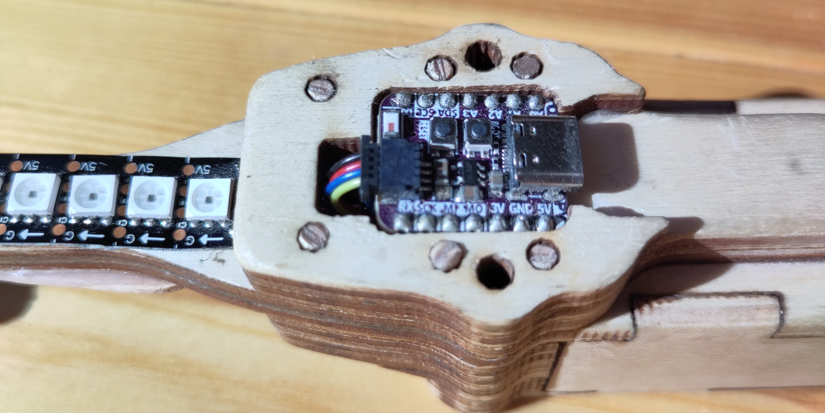
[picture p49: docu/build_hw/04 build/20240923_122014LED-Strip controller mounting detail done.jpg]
controller mounting done


# zusammen bauen Teil4
nun noch von Unten zwei Muttern in die löcher einfügen

Wenn hier noch Zeit übrig ist kann gern aus dem Kuststoff oder Schrumpfschlauch eine Abdeckung ausgeschnitten werden. (siehe [_layer-4 cover_ Schnitt-Vorlage](./../../hw/case/export/case_layer-4_mod_small_cover.svg))
diese wird dann auch mit den Schrauben fixiert.

von Oben die Schrauben durchstecken und mit einem 1,5mm Imbus fest ziehen.
Somit ist das Mittlere Holz-Teil fixiert.

Fertig ist dein Zauberstab :-)

# Weiter 
[in der Übersicht](workshop_DE.md)

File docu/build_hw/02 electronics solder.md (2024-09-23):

# Solder Electronics

## solder controller pins
solder controller pins 
solder controller pins 
solder controller pins 

## solder LED-Strip
solder LED-Strip 
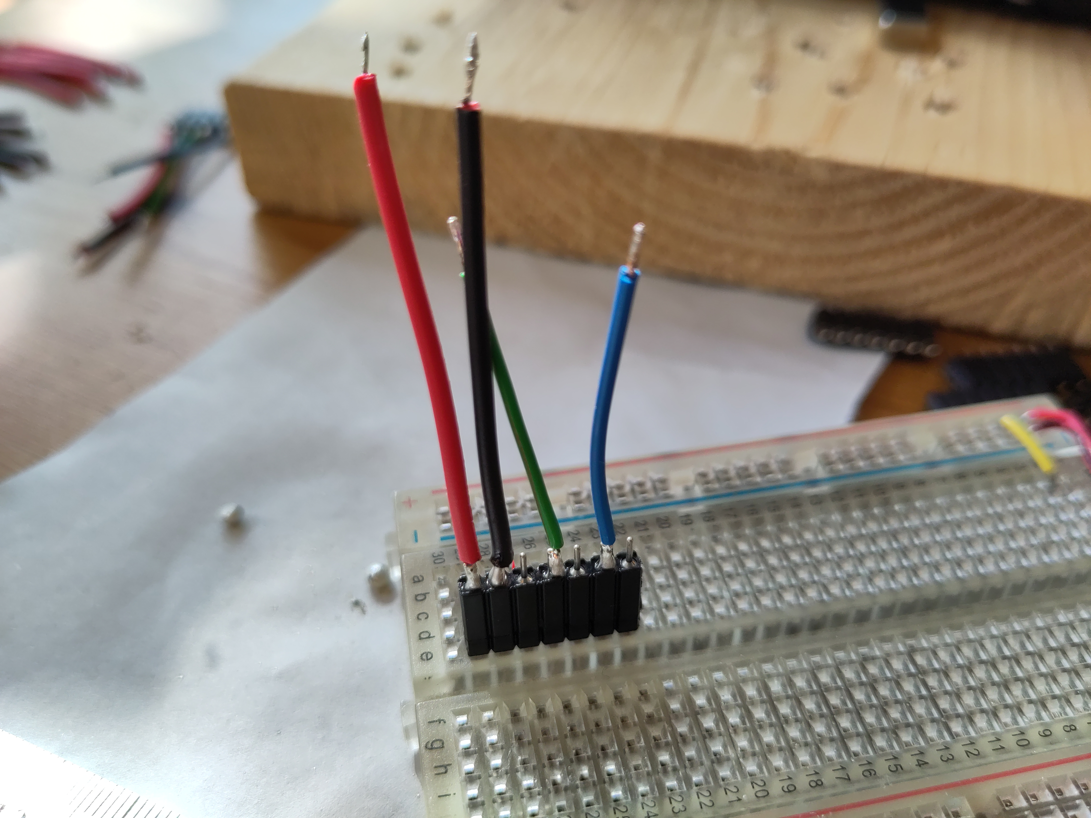
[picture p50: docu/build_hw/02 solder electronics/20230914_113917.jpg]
solder LED-Strip
 
solder LED-Strip 
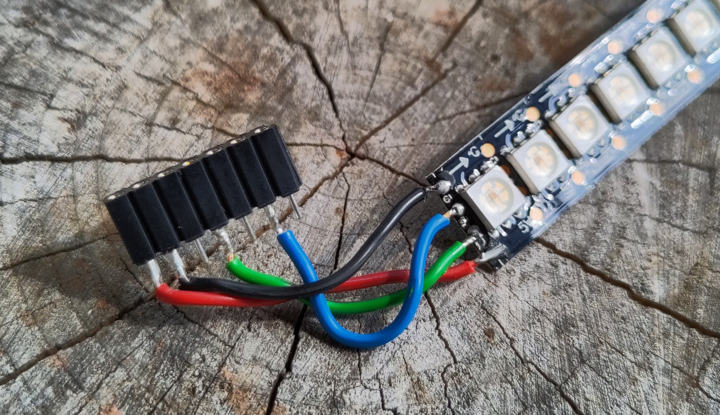
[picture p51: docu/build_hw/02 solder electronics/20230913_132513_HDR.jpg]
solder LED-Strip


## solder power cable
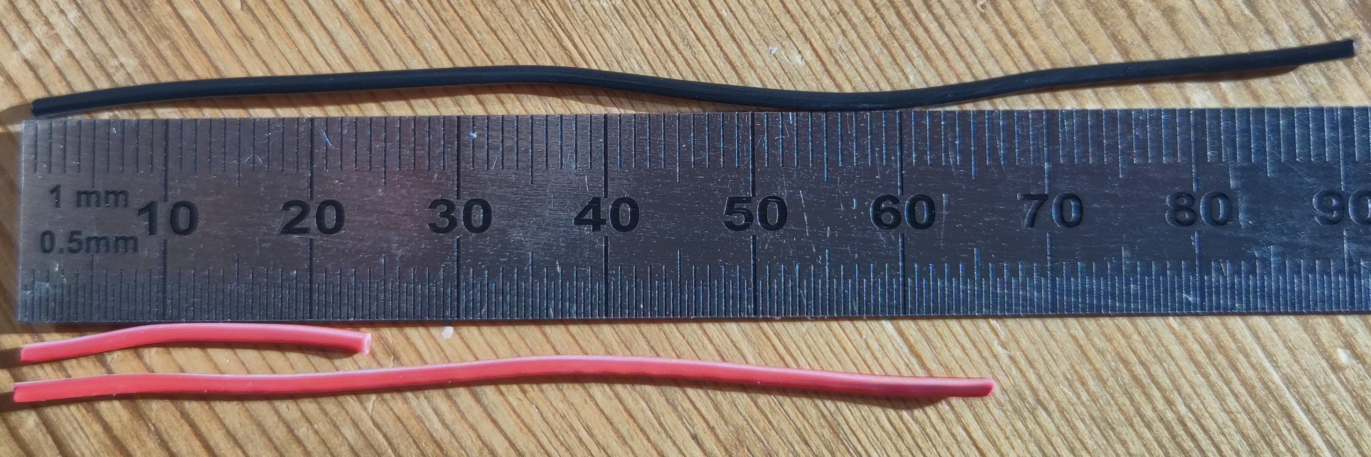
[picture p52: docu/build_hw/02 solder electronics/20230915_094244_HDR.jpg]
solder power cable
 
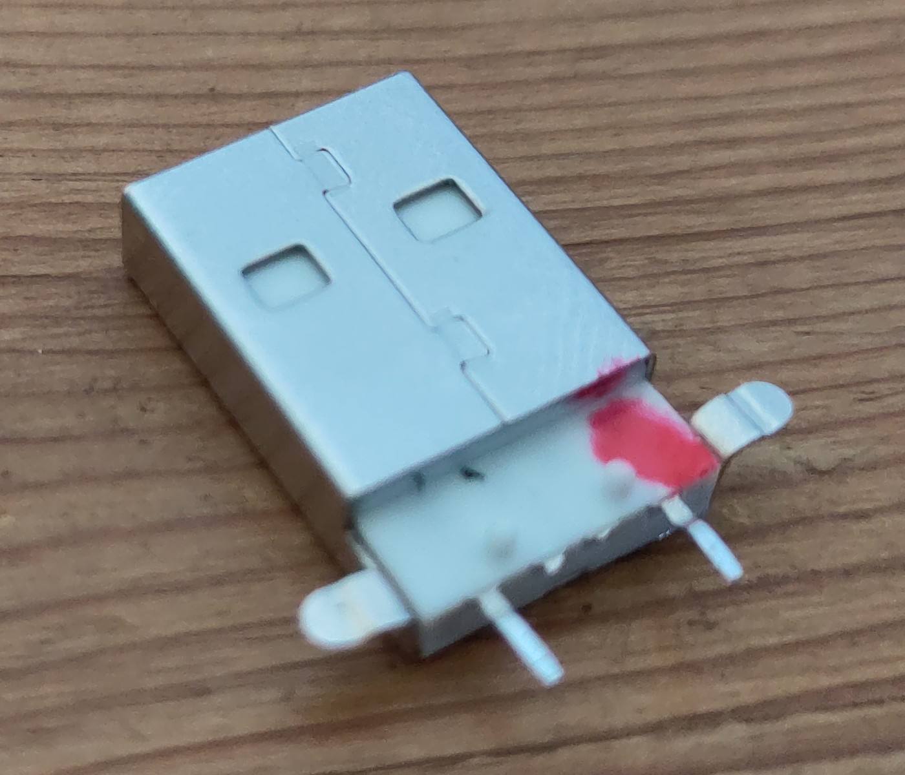
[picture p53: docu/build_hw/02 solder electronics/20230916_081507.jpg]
solder power cable
 
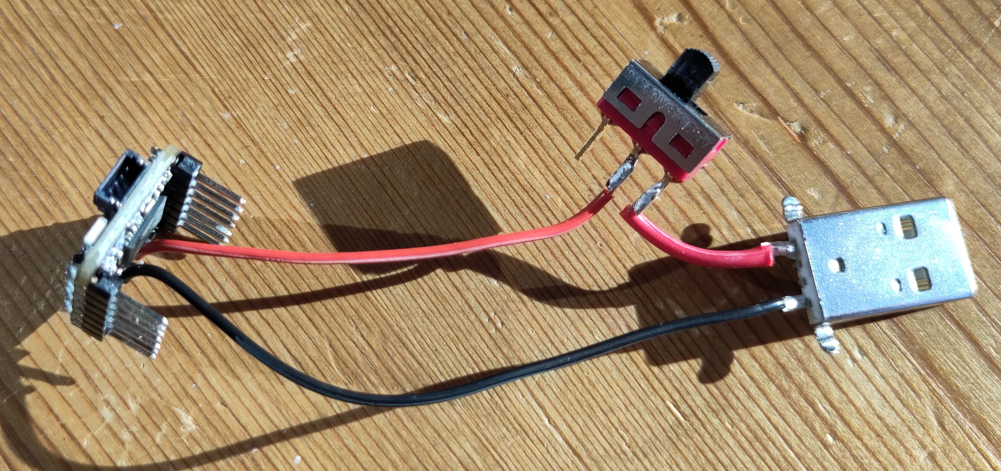
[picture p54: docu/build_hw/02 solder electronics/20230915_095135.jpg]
solder power cable
 
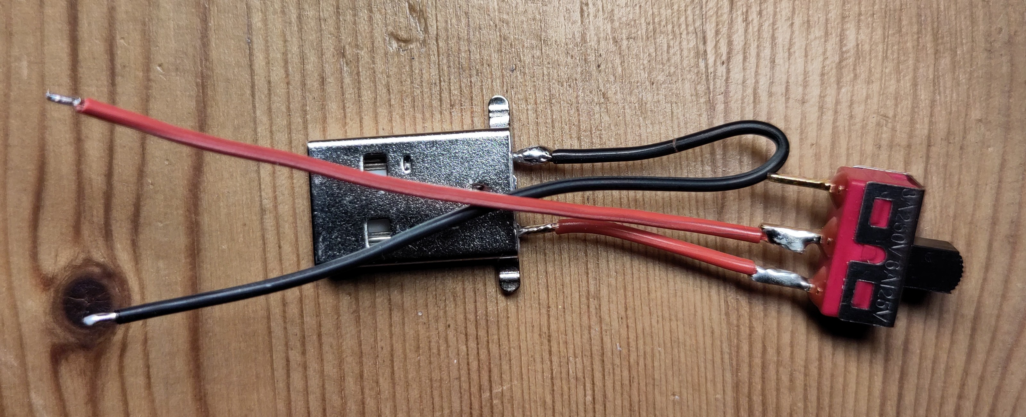
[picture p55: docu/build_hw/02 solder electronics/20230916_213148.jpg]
solder power cable
 
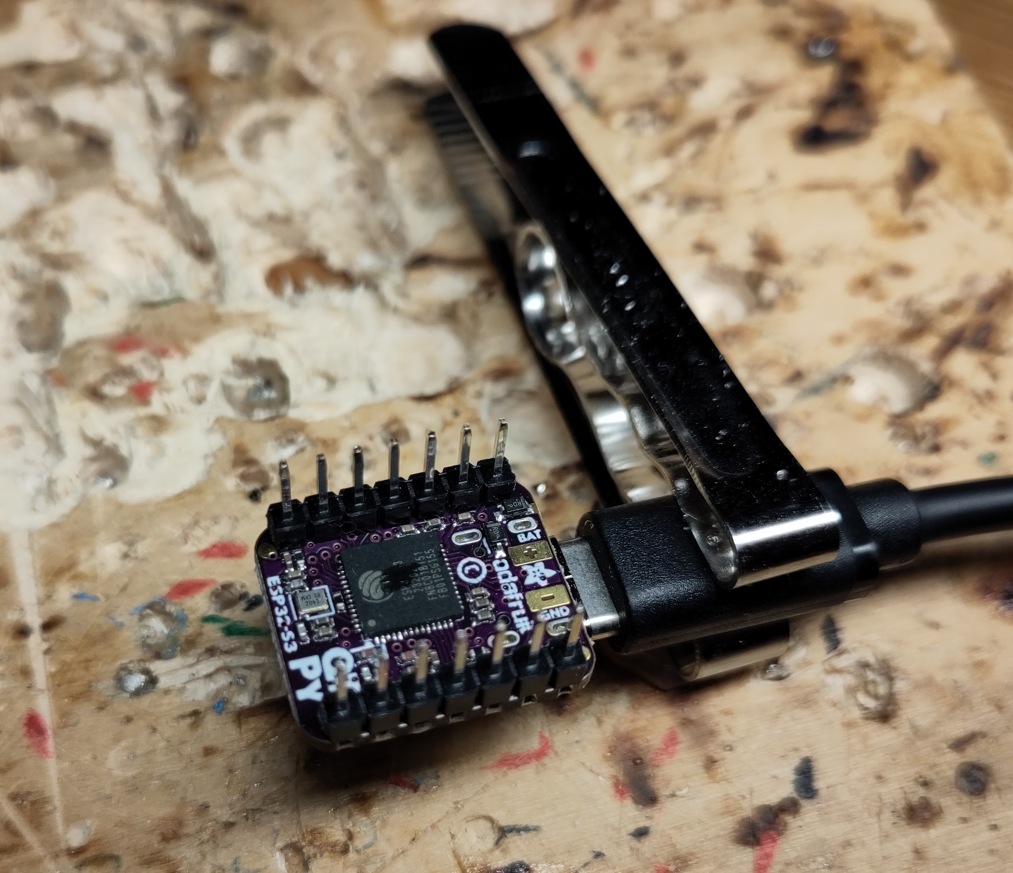
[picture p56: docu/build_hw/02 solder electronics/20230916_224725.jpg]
solder power cable
 
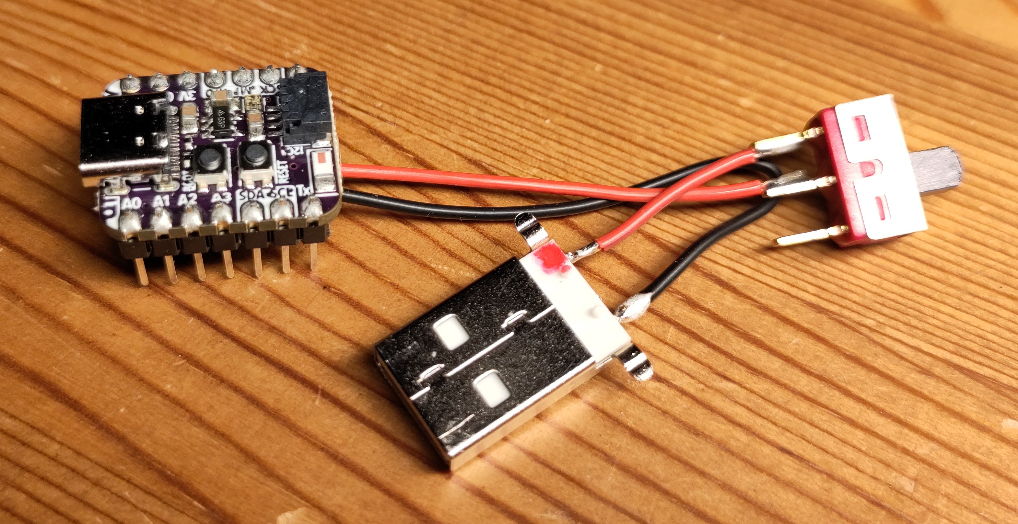
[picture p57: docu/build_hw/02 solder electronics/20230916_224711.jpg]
solder power cable


### its a good idea to strengthen the usb-power-connections with some hot-glue:
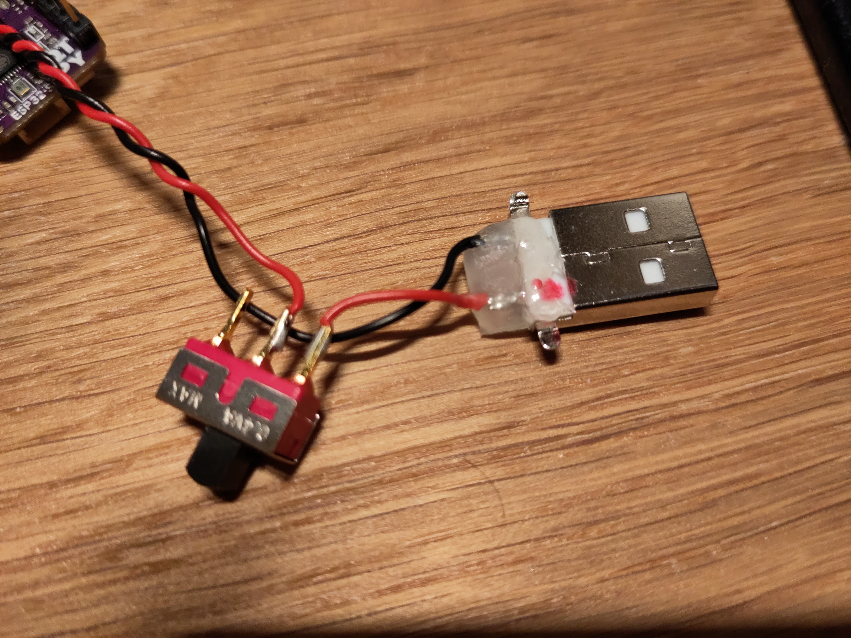
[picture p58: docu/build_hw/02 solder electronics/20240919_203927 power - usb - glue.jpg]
power - usb - hot-glue

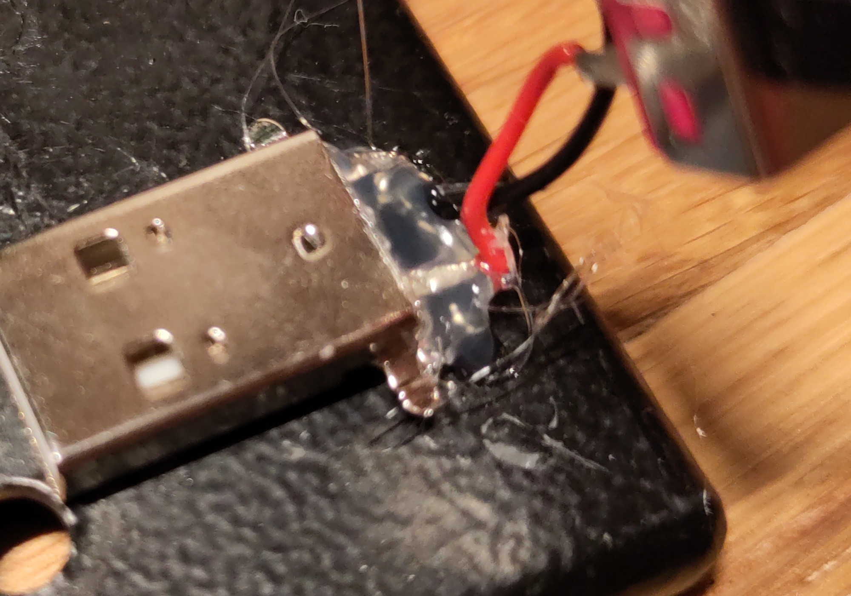
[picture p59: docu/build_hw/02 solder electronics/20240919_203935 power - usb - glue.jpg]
power - usb - hot-glue


<!-- 
not used anymore
## solder touch sensor adapter
![Alt text](<02 solder electronics/20230917_012738.jpg>) 

## prepare touch buttons
![Enameled copper wire lengths](<02 solder electronics/20230915_122823_mod.png>)
remove the enamel at both ends with some fine (320) sandpaper.
at one end 5mm at the other 40-50mm at all three peaces.

-->

## solder buttons

### cable length
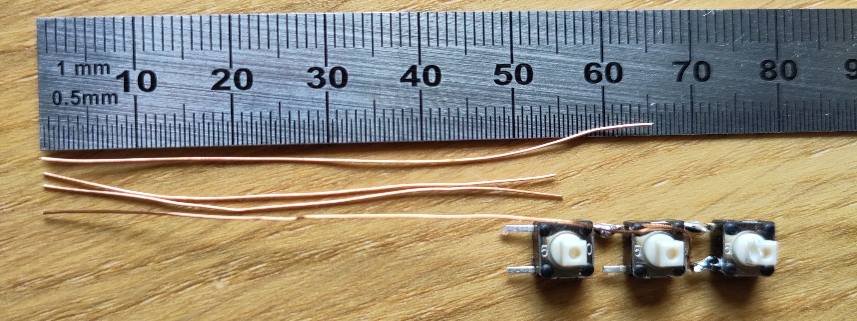
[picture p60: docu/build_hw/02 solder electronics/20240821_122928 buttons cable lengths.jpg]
buttons cable lengths.
 

- 2x 55mm
- 1x 65mm
- 1x 75mm

### solder with the help of the case

#### back
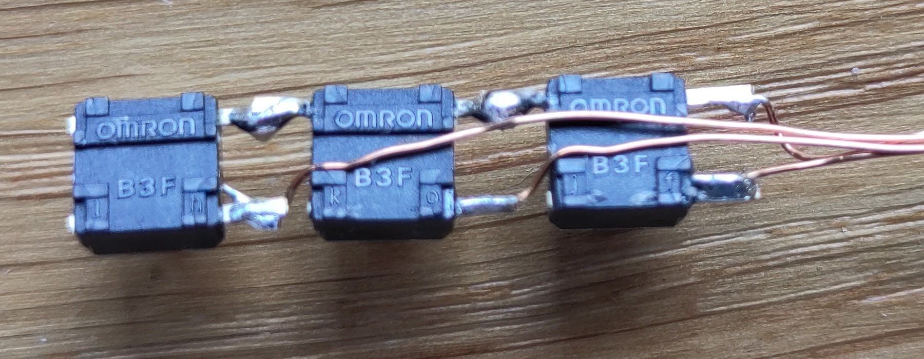
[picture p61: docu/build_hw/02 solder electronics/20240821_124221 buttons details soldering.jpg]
buttons details soldering

all wires should go in the center on the bottom of the buttons.
(in the case layer under the buttons is a slit to give space for the wires)

### mount in case
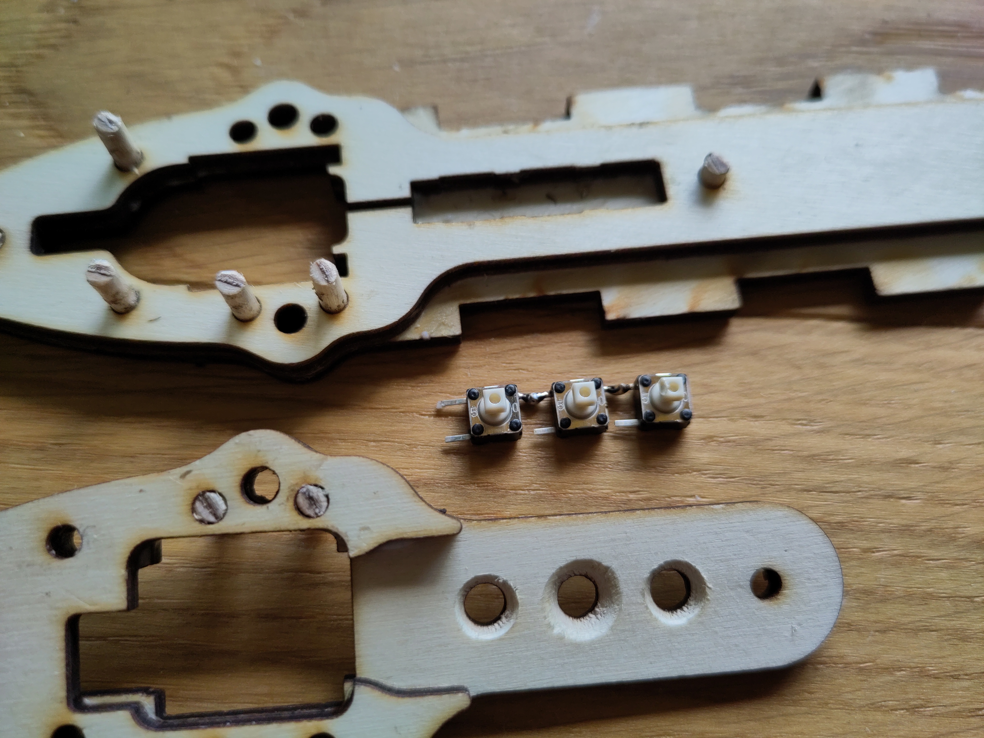
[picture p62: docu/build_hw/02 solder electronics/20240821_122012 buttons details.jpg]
buttons details.
 
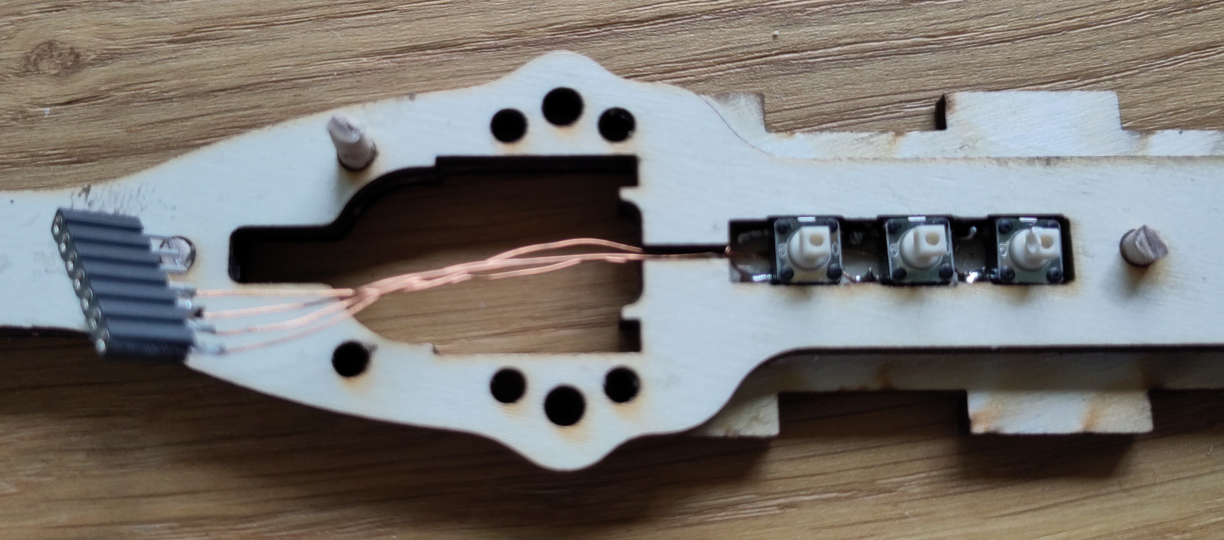
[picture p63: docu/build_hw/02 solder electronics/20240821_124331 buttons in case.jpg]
buttons in case.


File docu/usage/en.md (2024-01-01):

## Usage

The Software has 2 Modes:
- Lamp
- POV (Persistence Of Vision) 

you can switch between these two with the small button on the controller `D0`

TODO: this is outdated! currently only the german version is up to date. sorry!

### Mode: Lamp 
the three touch buttons are used to change settings:
- top: brighntess higher
- center: brighntess lower
- bottom: brighntess minimum
<!-- - top: higher
- center: lower 
- bottom: settings mode [brightness | color] (currently fixed to brighntess) -->

currently to change the color connect to a computer and open the [`config.py`](config.py) file found on the `CIRCUITPY` *usb-stick* device.
there you find a line 
```python
        "color_range": {
            "min": CHSV(0.08),
            "max": CHSV(0.12),
        },
```
define the base color hue as following:  
hue color  
(the shown example is a warm orange-yellow range..)
save the file and 
make sure you use the *safe remove* option of your system before resetting the board or unplugging!

### Mode: POV

~~the three touch buttons are used to change settings:~~
- ~~top: higher~~
- ~~center: lower~~
- ~~bottom: settings mode (brightness, color)~~

touch buttons currently deactivated as they have falls positiv during shaking..

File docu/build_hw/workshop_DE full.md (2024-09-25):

# MYS MakerFestival Workshop

<style>
    html, body {
        background: hsl(270,100%,10%);
        color: hsl(40, 100%, 50%);
        font-size: 1.2em;
    }
    img {
        max-width: 90vw;
        max-height: 60vh;
    }
</style>

@import "01 prepare wood de.md"

@import "02 electronics solder.md"

@import "03 electronics check - de.md"

@import "04 build de.md"

Fertig ist dein Zauberstab :-)

## Programmieren

<!-- TODO -->

....
schau mal in die documente:

-   [verwendung](/docu/usage/de.md)
-   [eigene bilder aufspielen](/docu/prepare_images/de.md)
-   [software aktuallisieren](/docu/update_firmware/de.md)

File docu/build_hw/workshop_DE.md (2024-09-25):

# MYS MakerFestival Workshop

<style>
    html, body {
        background: hsl(270,100%,10%);
        color: hsl(40, 100%, 50%);
        font-size: 1.2em;
    }
    img {
        max-width: 90vw;
        max-height: 60vh;
    }
</style>

Workshop Anleitung

([es gibt die vollständige Anleitung auch als PDF](<./workshop_DE full.pdf>))

## Holz Vorbereitung
[01 prepare wood de](<01 prepare wood de.md>)

## Elektronik vorbereiten
[02 electronics solder](<02 electronics solder.md>)

## Elektronik Testen
[03 electronics check](<03 electronics check - de.md>)

## Zusammenbauen
[04 build](<04 build de.md>)

Fertig ist dein Zauberstab :-)
    
## Programmieren

<!-- TODO -->
....
schau mal in die documente:
- [verwendung](/docu/usage/de.md)
- [eigene bilder aufspielen](/docu/prepare_images/de.md)
- [software aktuallisieren](/docu/update_firmware/de.md)

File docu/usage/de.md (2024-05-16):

# Bedienung

## Grundlagen

der Zauberstab hat zwei verschiedene _Modi_:

-   RGBLamp
-   POVPainter

Umschalten kann man diese mit dem kleinen Taster knapp überhalb der USB Buchse.

<!-- TODO: FOTO EINFÜGEN! -->

Auf dem Controller gibt es des weiteren eine kleine LED die in verschiedenen Farben leuchten kann.
ich nennen sie `status_led`

Die _Touch-Tasten_ sind deaktiviert.
Sie funktionieren leider zu unzuverlässig.

Dafür ist kann der Stab nun mit (einfachen) _Gesten_ eingestellt werden.
Was genau welche Geste bewirkt kannst du unten im Abschnitt [Modi](#modi) nachlesen
Alle Gesten sollten aus einer Horizontalen Ruhe-Position angefangen werden.

Der Stab kennt:

-   `TILT_RIGHT`
-   `TILT_LEFT`
-   `SHAKE_Y`

### `TILT_RIGHT` & `TILT_LEFT`

-   halte den Stab ruhig in einer Horizontalen Position.
-   `status_led` sollte _hell_ grün leuchten
-   nun den Stab um die eigene lange Achse langsam nach Rechts oder Links drehen/kippen
-   wenn weit genug gekippt wurde wechselt die `status_led` zu
    -   gelb für Links
    -   türkis für Rechts

### `SHAKE_Y`

Gut Festhalten!!
einfach _seitlich_ schütteln / wedeln.

siehe dieses Video:
<video src="./../mode%20POVPainter.mp4" controls title="Mode: POVPainter - showing two different images"></video>

## Modi

### RGBLamp

einfach Lampen Funktion

die Farbe der Lampe hat einen leichten *Schwebe*-Effekt.
Sie variiert in einem Voreingestellten Rahmen und gibt so ein bisschen *lebendigkeit*

-   `TILT_RIGHT` → Helligkeit + 10%
-   `TILT_LEFT` → Helligkeit - 10%
-   `SHAKE_Y` → keine Funktion

<video src="usage%20gesture%20brightness%20short.mp4" controls title="brightness change"></video>

##### Besonderheit bei der Helligkeit:
um auch sehr dunkle *nachtlicht* Helligkeiten zu ermöglichen, 
werden unter 50% nur ein teil der LEDs genutzt. 
bei <=10% ist damit dann nur noch eine einzelne LED an.

### POVPainter

Persistance Of Vision = Bilder Malen :-)

jedes mal wenn ein Bild _geladen_ wird wird der Vortschitt mit einem Grünen _Lade-Balken_ auf den LEDs dargestellt.

dies passiert beim ersten starten des Modus und beim Wechseln des Bildes.

Einstellungsoptionen:

-   `TILT_RIGHT` → lade nächstes Bild.
-   `TILT_LEFT` → keine Funktion
-   `SHAKE_Y` → Zeichne Bild

Wichtig: beim `SHAKE_Y` braucht es einen kurzen moment bis das Bild erscheint.
in dieser Zeit kalibriert sich der Stab auf deine Wedel-Geschwindigkeit.
Wenn du sehr hohe Schwankungen deiner Wedel-Geschwindigkeit hast kann es sein das das Bild zwischendurch aus geht..
Probiere dann einfach _konstanter_ zu Wedeln...

## Weitere Einstellungen

es gibt noch weitere Einstellungsoptionen! Diese kann man allerdings nur über die `config.py` Datei anpassen.

- Diese Datei findest du wenn du den Stab per USB an den Computer anschließt.
- der Stab meldet sich als USB-Speicher-Stick mit dem Namen `CIRCUITPY`.
- Dort findest du die Datei `config.py`.
- öffne diese am besten mit dem `MU` editor.
    - dafür das Programm `MU` starten
    - falls die *Modus* abfrage kommt `Adafruit CircuitPython` auswählen
    - dann oben auf `Load` clicken. 
    - dann das Laufwerk `CIRCUITPY` auswählen (wahrscheinlich ist es schon ausgewählt!)
    - und die Datei `config.py` Öffnen.
- immer wenn du eine Änderung gemacht hast kannst du auf `Save` drücken.
- damit wird die Datei auf den Zauberstab gespeichert → dieser startet einmal neu und deine Änderungen sind wirksam.

Diese sieht in etwa so aus:
```python
config = {
    # in wich mode to start: (RGBLamp | POVPainter)
    # "start_mode": "RGBLamp",
    "start_mode": "POVPainter",
    "POVPainter": {
        "brightness": 1.0,
    },
    "RGBLamp": {
        "brightness": 0.2,
        # effect duration in seconds
        "effect_duration": 10 * 60,
        #
        # colors
        # https://learn.adafruit.com/fancyled-library-for-circuitpython/colors#hsv-colors-2981215
        # only specifying Hue for fully saturated color..
        # purple
        # "color_range": {
        #     "min": CHSV(0.50),
        #     "max": CHSV(0.9),
        # },
        # warm orange
        "color_range": {
            "min": CHSV(0.08),
            "max": CHSV(0.12),
        },
        # extra effects...
        "extra_effects": {
            # y_to_brightness can be used for a *candle like* effect
            "y_to_brightness": False,
            # "y_to_brightness": (0.3, 0.7),
        },
    },
}
```

ich hoffe das die meisten einstellungen selbst-erklärend sind..
wichtig ist:
es gibt für beide modi jeweils eine eigene Helligkeits einstellung:
`brightness`
der Werte Bereich geht von 0.0 bis 1.0 - du kannst da z.B. `0.01` für sehr dunkel rein schreiben.

### `povpainter`
beim `povpainter` ist hier wichtig zu beachten: 
bei niedrigen werten (z.B:`0.1`) geht die *Farb-Auflösung* verloren → weniger darstellbare Farben.
Um also alle Farben sehen zu können braucht es *mittlere* Werte. 
Ich empfehle `0.6` das passt meist..

### `rgblamp`

#### Besonderheit bei `brightness`
um auch sehr dunkle *nachtlicht* Helligkeiten zu ermöglichen, 
werden ab werten von unter `0.5` nur ein teil der leds genutzt. 
bei `0.1` ist damit dann nur noch eine einzelne LED an.

#### Einstellen der Farbe und Effekt-Geschwindigkeit
wie oben beschrieben *Schwebt* / *Wabbert* die Farbe etwas..

die Geschwindigkeit lässt sich bei `effect_duration` einstellen.
Standard sind `10 * 60` Sekunden (= 10minuten)

die Farben kannst du mit der config `color_range` einstellen.
dort gibt es eine `min` und eine `max` Farbe.
```python
        "color_range": {
            "min": CHSV(0.08),
            "max": CHSV(0.12),
        },
```
diese ist als HSV wert angegeben.
Was ist das?
- Hue → Farb-Ton
- Saturation → Sättigung (wie viel weiß Anteil)
- Value → *Helligkeit

die Werte für den Farb-Ton kannst du in dieser Grafik ablesen:
hue color

daraus ergeben sich für das Beispiel oben Rot bis Orange Töne..

Vielleicht fragst du dich nun warum bei `"min": CHSV(0.08),` nur ein Wert steht?
ganz einfach: das ist `Hue`. für S und V werden die *Standard* Werte von `1.0` angenommen.
damit ergibt sich eine vollständig Gesättigte Farbe.
wenn du mehr etwwas weißes haben möchtest ginge das z.B. so:
```python
        "color_range": {
            "min": CHSV(0.66),
            "max": CHSV(0.66, 0.2, 1.0),
        },
```
das würde ein Tief Blau bis Weiß-Blau ergeben.
es macht hier durch aus sinn etwas mit den Farben aus zu probieren & zu spielen :-)

Wenn du es gaaaaaaaaannnzzz Bunt magst - probiere doch mal
```python
        "color_range": {
            "min": CHSV(0.0),
            "max": CHSV(1.0),
        },
```

ganz unten findest du dann noch ein `extra_effects`.
```python
        # extra effects...
        "extra_effects": {
            # y_to_brightness can be used for a *candle like* effect
            "y_to_brightness": False,
            # "y_to_brightness": (0.3, 0.7),
        },
```
dort habe ich etwas lustiges ausprobiert...
der *effect* `y_to_brightness`  mapped (*überträgt*) den beschleunigungs-sensor wert der y Achse auf die Helligkeit.
der Werte Bereich des Helligkeit für das mappings ist im beispiel mit 0.3 bis 0.7. angegeben: 
- 0.3 minimale Helligkeit bei fast keiner  Bewegung
- 0.7 maximale Helligkeit bei sehr starker Bewegung

Dadurch kann man einen *Kerzen-Flicker-Effekt* erzeugen - 
wenn man den Zauberstab z.B. in einer *Sankt-Martins* Laterne durch die Gegend trägt...
(das war der Ursprung für den Effekt...)

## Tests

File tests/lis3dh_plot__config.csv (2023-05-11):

[Channels]
channel\1\color=@Variant(\0\0\0\x43\x1\xff\xff\x43\x43\xc8\xc8\0\0\0\0)
channel\1\gain=1
channel\1\gainEnabled=false
channel\1\name=X
channel\1\offset=0
channel\1\offsetEnabled=false
channel\1\visible=true
channel\10\color=@Variant(\0\0\0\x43\x1\xff\xff\x85\x85\xa9\xa9\0\0\0\0)
channel\10\gain=1
channel\10\gainEnabled=false
channel\10\name=Channel 10
channel\10\offset=0
channel\10\offsetEnabled=false
channel\10\visible=true
channel\2\color=@Variant(\0\0\0\x43\x1\xff\xff\xfe\xfe\x89\x89\0\0\0\0)
channel\2\gain=1
channel\2\gainEnabled=false
channel\2\name=Y
channel\2\offset=0
channel\2\offsetEnabled=false
channel\2\visible=true
channel\3\color=@Variant(\0\0\0\x43\x1\xff\xff\xff\xff\0\0\0\0\0\0)
channel\3\gain=1
channel\3\gainEnabled=false
channel\3\name=Z
channel\3\offset=0
channel\3\offsetEnabled=false
channel\3\visible=true
channel\4\color=@Variant(\0\0\0\x43\x1\xff\xff\0\0\0\0\xff\xff\0\0)
channel\4\gain=1
channel\4\gainEnabled=false
channel\4\name=step_name
channel\4\offset=-0.3
channel\4\offsetEnabled=true
channel\4\visible=false
channel\5\color=@Variant(\0\0\0\x43\x1\xff\xff\xaa\xaa\0\0\xff\xff\0\0)
channel\5\gain=1
channel\5\gainEnabled=false
channel\5\name=error
channel\5\offset=0
channel\5\offsetEnabled=false
channel\5\visible=true
channel\6\color=@Variant(\0\0\0\x43\x1\xff\xffjj\x82\x82ll\0\0)
channel\6\gain=1
channel\6\gainEnabled=false
channel\6\name=p_value
channel\6\offset=0
channel\6\offsetEnabled=false
channel\6\visible=false
channel\7\color=@Variant(\0\0\0\x43\x1\xff\xff\xff\xff\x2\x2\x9d\x9d\0\0)
channel\7\gain=1
channel\7\gainEnabled=false
channel\7\name=i_value
channel\7\offset=0
channel\7\offsetEnabled=false
channel\7\visible=false
channel\8\color=@Variant(\0\0\0\x43\x1\xff\xffzzGG\x82\x82\0\0)
channel\8\gain=1
channel\8\gainEnabled=false
channel\8\name=pid_error
channel\8\offset=0
channel\8\offsetEnabled=false
channel\8\visible=true
channel\9\color=@Variant(\0\0\0\x43\x1\xff\xff\0\0\xde\xde\x9b\x9b\0\0)
channel\9\gain=1
channel\9\gainEnabled=false
channel\9\name=pid_output
channel\9\offset=0
channel\9\offsetEnabled=false
channel\9\visible=false
channel\size=10
[Commands]
command\1\data=
command\1\name=Command 1
command\1\type=ascii
command\size=1
[DataFormat]
format=ascii
[DataFormat_ASCII]
customDelimiter=";"
delimiter=","
filterMode=disabled
filterPrefix=m/s^2
numOfChannels=1
[DataFormat_Binary]
endianness=little
numOfChannels=1
numberFormat=uint8
[DataFormat_CustomFrame]
checksum=false
debugMode=false
endianness=little
fixedSize=false
frameSize=1
frameStart=AA BB
numOfChannels=1
numberFormat=uint8
[MainWindow]
activePanel=Plot
hidePanels=false
maximized=true
pos=@Point(1 0)
size=@Size(3072 1670)
state=@ByteArray(\0\0\0\xff\0\0\0\0\xfd\0\0\0\0\0\0\f\0\0\0\x6'\0\0\0\x4\0\0\0\x4\0\0\0\b\0\0\0\b\xfc\0\0\0\x1\0\0\0\x2\0\0\0\x3\0\0\0\f\0t\0\x62\0P\0l\0o\0t\x1\0\0\0\0\xff\xff\xff\xff\0\0\0\0\0\0\0\0\0\0\0\x1a\0t\0\x62\0P\0o\0r\0t\0\x43\0o\0n\0t\0r\0o\0l\x1\0\0\0\xd0\xff\xff\xff\xff\0\0\0\0\0\0\0\0\0\0\0\x10\0t\0\x62\0R\0\x65\0\x63\0o\0r\0\x64\x1\0\0\x2\x92\xff\xff\xff\xff\0\0\0\0\0\0\0\0)
[Plot]
autoScale=false
darkBackground=true
decimals=2
grid=true
indexAsX=true
legend=true
minorGrid=true
multiPlot=false
numLines=1000
numOfSamples=1000
plotWidth=1000
symbols=auto
xMax=100
xMin=0
yMax=120
yMin=-120
[Port]
baudRate=115200
dataBits=8
flowControl=none
parity=none
selectedPort=ttyACM0
stopBits=1
[Record]
autoIncrement=true
decimals=2
disableBuffering=false
header=true
recordPaused=true
separator=","
stopOnClose=true
timestamp=true
timestampFormat=seconds_with_precision
[UpdateCheck]
lastCheck=2023-05-01
periodicCheck=true

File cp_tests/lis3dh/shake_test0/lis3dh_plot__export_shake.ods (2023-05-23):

time | X | Y | Z | time delta
0 | 0 | 0 | 0 | 0
3,418 | -0,258 | -0,598 | -0,61 | 3,418
7,324 | -0,258 | -1,254 | -0,821 | 3,906
11,23 | -0,223 | -1,852 | -0,985 | 3,906
15,136 | -0,246 | -2,497 | -1,16 | 3,906
19,531 | -0,223 | -2,977 | -1,36 | 4,395
23,437 | -0,223 | -3,177 | -1,571 | 3,906
27,343 | -0,199 | -3,657 | -1,629 | 3,906
31,249 | -0,188 | -3,985 | -1,7 | 3,906
35,644 | -0,141 | -4,278 | -1,676 | 4,395
37,597 | -0,152 | -4,454 | -1,571 | 1,953
40,527 | -0,152 | -4,525 | -1,383 | 2,93
43,457 | -0,152 | -4,384 | -1,207 | 2,93
46,387 | -0,188 | -4,021 | -1,078 | 2,93
49,317 | -0,258 | -3,657 | -1,032 | 2,93
52,247 | -0,375 | -3,2 | -1,032 | 2,93
55,177 | -0,516 | -2,555 | -1,137 | 2,93
58,107 | -0,586 | -1,653 | -1,278 | 2,93
61,525 | -0,574 | -0,61 | -1,465 | 3,418
64,455 | -0,527 | 0,692 | -1,676 | 2,93
67,385 | -0,375 | 2,157 | -1,793 | 2,93
70,315 | -0,223 | 3,493 | -1,782 | 2,93
73,733 | -0,094 | 4,947 | -1,688 | 3,418
76,663 | 0,105 | 6,037 | -1,547 | 2,93
79,593 | 0,199 | 6,763 | -1,407 | 2,93
82,523 | 0,199 | 7,15 | -1,184 | 2,93
86,918 | 0,246 | 7,244 | -0,891 | 4,395
89,848 | 0,211 | 7,162 | -0,727 | 2,93
93,7540000000001 | 0,129 | 6,728 | -0,481 | 3,906
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

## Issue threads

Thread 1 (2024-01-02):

POVPainter: experiment with adafruit_imageload and OnDiskBitmap

s-light, 2024-01-02:
setup a minimal example with
 [adafruit_imageload](https://docs.circuitpython.org/projects/imageload/en/latest/) and [OnDiskBitmap](https://docs.circuitpython.org/en/latest/shared-bindings/displayio/index.html#displayio.OnDiskBitmap)

and also add this to
https://github.com/adafruit/Adafruit_CircuitPython_DotStar/issues/64#issuecomment-1689309720

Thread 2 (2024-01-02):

use gyro instead of accelerometer?

s-light, 2024-01-02:
experiment with gyro instead of accelerometer -
maybe this gives better results?!
reference:
pov video at https://www.crowdsupply.com/breadstick-innovations/raspberry-breadstick
with this code:
https://github.com/Breadstick-Innovations/Raspberry-Breadstick/blob/main/Demo%20Code%20-%20rev0.2/CircuitPython/POV/code.py

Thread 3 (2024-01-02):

update docu when openmoji.org has copy button

s-light, 2024-01-02:
if https://github.com/hfg-gmuend/openmoji.org/issues/182 is resolved we need to update the bitmap preparation docu

s-light, 2024-10-05:
done..

Closed 2024-10-05.

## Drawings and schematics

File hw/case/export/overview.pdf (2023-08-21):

400

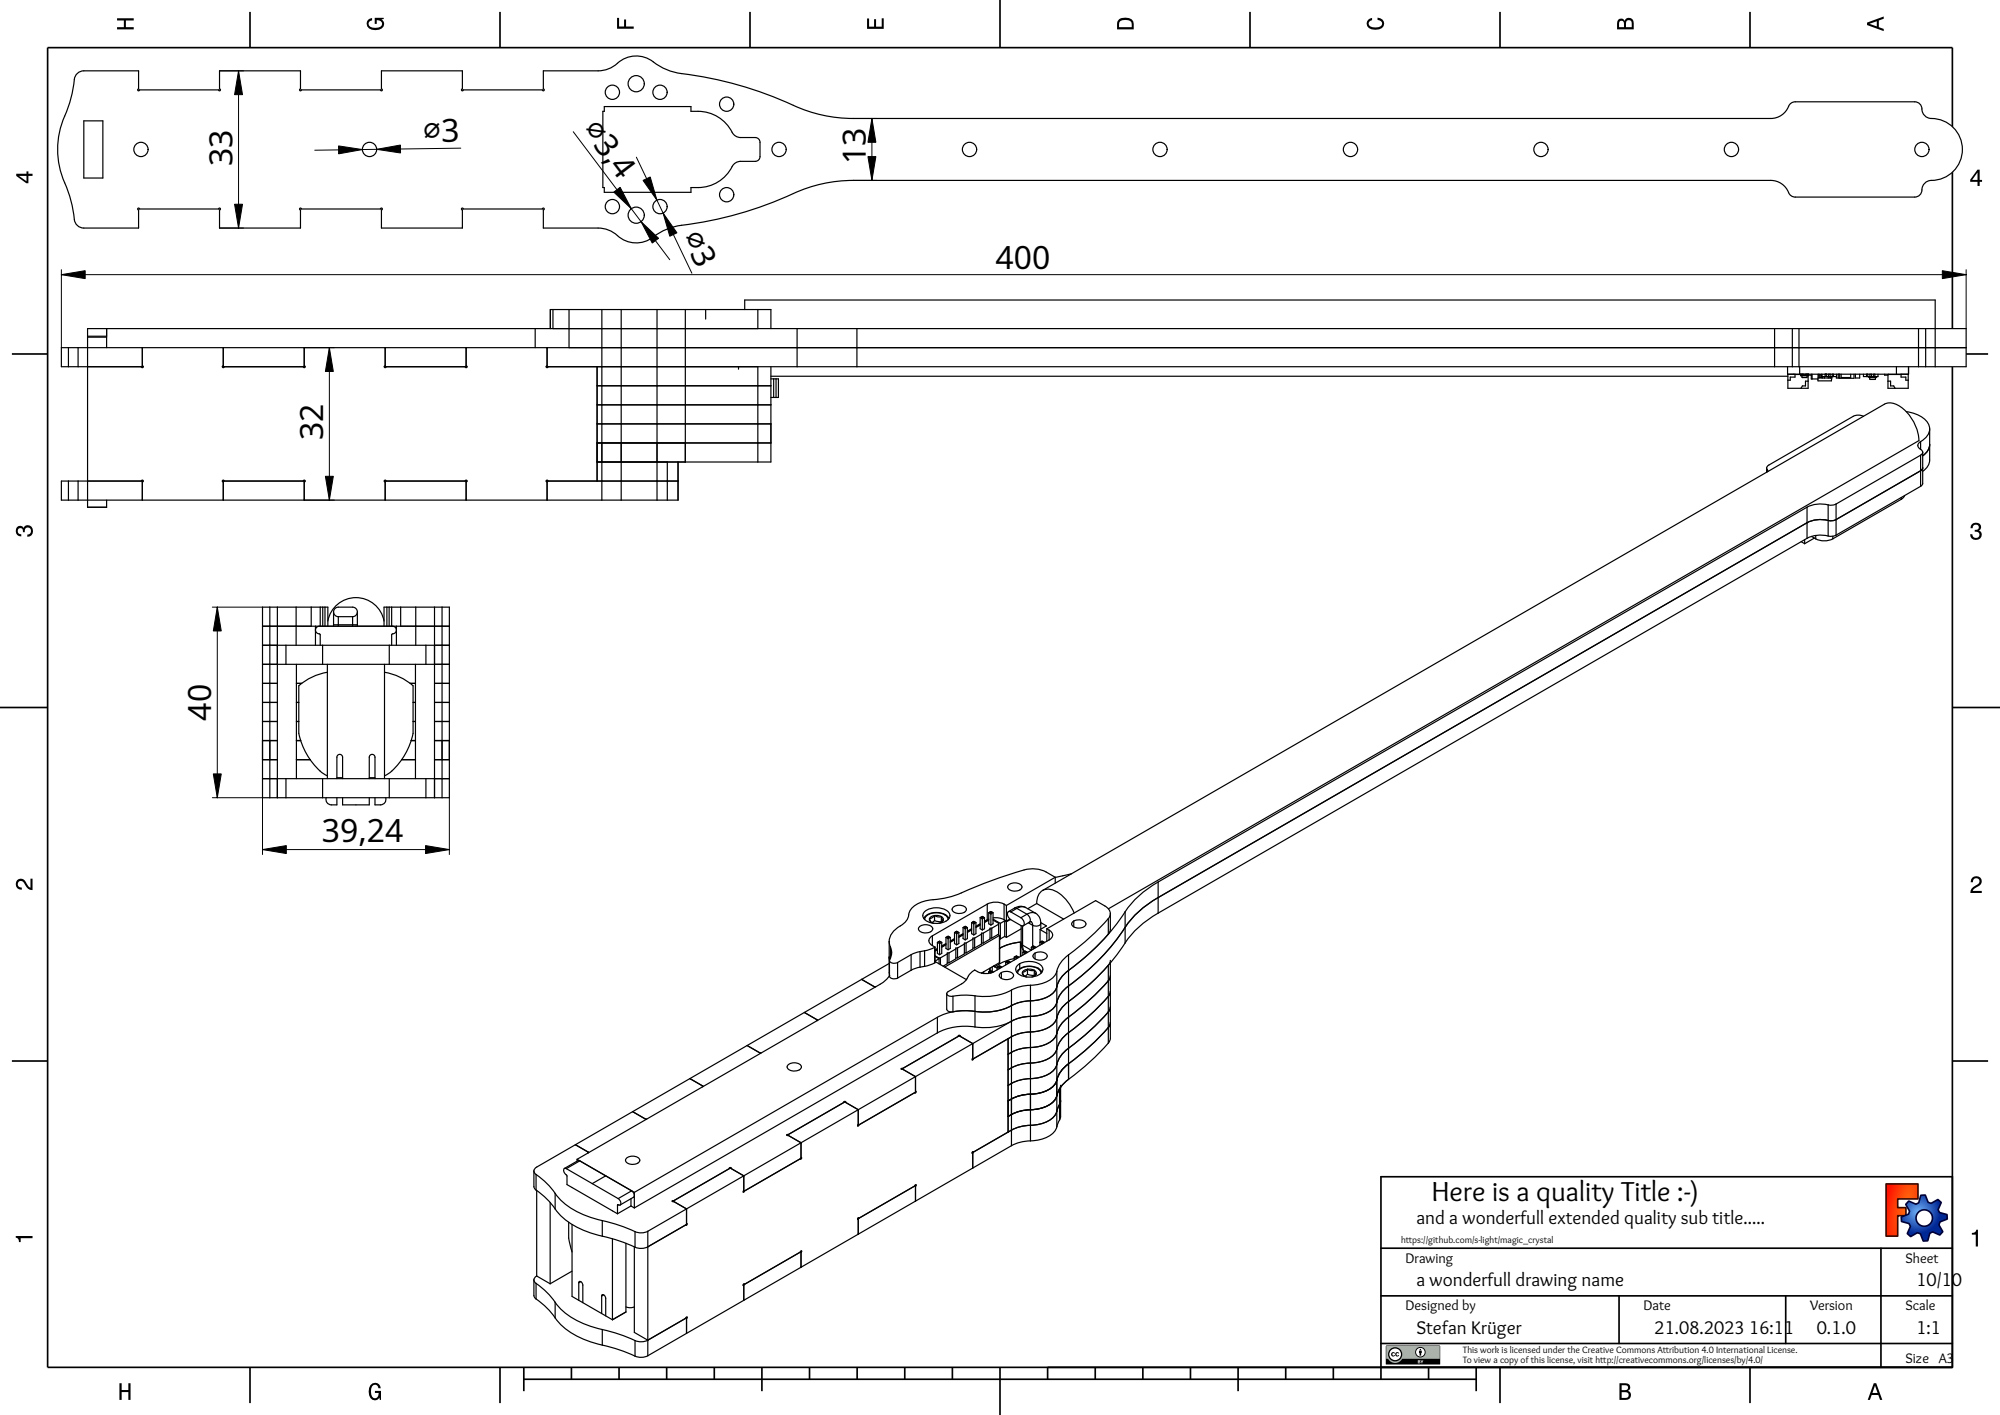
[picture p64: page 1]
a wonderfull drawing name

Here is a quality Title :-)
and a wonderfull extended quality sub title.....

https://github.com/s-light/magic_crystal
Drawing | Sheet

Designed by Stefan Krüger | Date 21.08.2023 16:11 | Version 0.1.0 | Scale 1:1

To view a copy of this license, visit http://creativecommons.org/licenses/by/4.0/ | | | A3 This work is licensed under the Creative Commons Attribution 4.0 International License. Size

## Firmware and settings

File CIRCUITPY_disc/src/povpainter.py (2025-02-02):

# POV Painter - POV Zauberstab
# SPDX-FileCopyrightText: 2023 Stefan Krüger s-light.eu
# SPDX-License-Identifier: MIT
# source https://github.com/s-light/cp_magic_painter/
#
# based on
#
# CircuitPython Painter
#     SPDX-FileCopyrightText: 2017 Limor Fried for Adafruit Industries
#     SPDX-License-Identifier: MIT
#     source: https://learn.adafruit.com/circuitpython-painter
#
# CLUE lightpainting
#     SPDX-FileCopyrightText: 2020 Phillip Burgess for Adafruit Industries
#     SPDX-License-Identifier: MIT
#     source: https://learn.adafruit.com/clue-light-paintstick/code-with-circuitpython


"""
POV Painter - POV Zauberstab

based on 
    CircuitPython Painter
        https://learn.adafruit.com/circuitpython-painter
    CLUE lightpainting 
        https://learn.adafruit.com/clue-light-paintstick/code-with-circuitpython


HW: some high speed processor...
    - QT Py ESP32-S3
    - Lis3dh
    - dotstar / APA102 compatible led strip
"""


##########################################
# imports


import gc
import time

import board
import busio
import digitalio
import displayio

import json

import adafruit_imageload
import ansi_escape_code as terminal
from ansi_escape_code.progressbar import ProgressBar

from mode_base import ModeBaseClass

from configdict import extend_deep

import helper

from bmp2led import BMP2LED, BMPError

from gesture_detector import (
    UNKNOWN,
    REST,
    REST_HORIZONTAL,
    REST_VERTICAL,
    TILT_LEFT,
    TILT_RIGHT,
    TAB_X,
    TAB_Y,
    TAB_Z,
    DIRECTION_CHANGED,
    SHAKE_X,
    SHAKE_Y,
    SHAKE_Z,
)

##########################################
# main class


class POVPainter(ModeBaseClass):
    """POVPainter."""

    __name__ = "POVPainter"

    config_defaults = {
        # QT Py ESP32-S3
        "POVPainter": {
            "paint_mode_classic": True,
            "image_folder": "/images",
            "temp_file": "/led.dat",
            "led_data_file_benchmark": "/led_benchmark.dat",
            # Correction for perceptually linear brightness
            "gamma": 2.4,
            # draw / stroke duration in seconds
            # "times": ["1/8", "1/4", "1/3", "1/2", "2/3", "1", "1.5", "2", "3", "4"],
            "draw_duration": 0.7,
            "brightness": 0.01,
            # Min, max brightness (0.0-1.0)
            # "brightness_range": (0.004, 0.75),
            "brightness_range": (0.2, 0.75),
            "loop": False,
        },
    }

    def __init__(self, *, config={}, print_fn, accel_sensor):
        super(POVPainter, self).__init__(config=config, print_fn=print_fn)
        self.print = print
        self.print(42 * "*")
        self.print("POVPainter")
        self.print("  https://github.com/s-light/cp_magic_painter")
        self.print(42 * "*")

        self.config_extend_with_defaults(defaults=self.config_defaults)
        # print(self.__class__, "config extended:")
        # self.config_print()

        self.accel_sensor = accel_sensor

        # prepare internals
        self.spi_init_done = False
        self.first_run = False
        self._brightness = None

        self.pixel_count = self.config["hw"]["pixel_count"]

        self.paint_mode_classic = self.config["POVPainter"]["paint_mode_classic"]
        if self.paint_mode_classic:
            self.load_image = self.load_image_v1
            self.paint = self.paint_v1
        else:
            self.load_image = self.load_image_v2
            self.paint = self.paint_v2

        self.fs_writeable = self.check_filesystem_writeable()
        print("fs_writeable ", self.fs_writeable)

        # OLD Draw version = classic
        # self.pixel_delay = 0.0014
        self.pixel_delay = 0.0010
        self.pixel_delay_max = 0.002
        self.pixel_delay_raw = self.pixel_delay
        # self.pixel_delay = 0.0
        self.paint_duration = 0

        self.image_buffer = bytearray(0)
        self.bmpHeight = 0
        self.bmpWidth = 0

        # Advanced CLUE version
        self.bmp2led = BMP2LED(
            pixel_count=self.pixel_count,
            color_order=self.config["hw"]["pixel_color_order"],
            gamma=self.config["POVPainter"]["gamma"],
        )
        self.path = self.config["POVPainter"]["image_folder"]
        self.tempfile = self.config["POVPainter"]["temp_file"]
        self.led_data_file_benchmark = self.config["POVPainter"][
            "led_data_file_benchmark"
        ]
        self.brightness_range = self.config["POVPainter"]["brightness_range"]

        # self.times = self.config["POVPainter"]["times"]
        # self.times.sort(key=eval)  # Ensure times are shortest-to-longest
        self.draw_duration = self.config["POVPainter"]["draw_duration"]

        # TODO: try https://github.com/adafruit/Adafruit_CircuitPython_DotStar/blob/main/examples/dotstar_image_pov.py
        # Get list of compatible BMP images in path
        self.images = self.bmp2led.scandir(self.path)
        if not self.images:
            print("no images found. using testpattern.")
            # TODO implement / generate test-pattern
            # https://docs.circuitpython.org/projects/display-shapes/en/latest/api.html#adafruit_display_shapes.rect.Rect
            # https://learn.adafruit.com/circuitpython-display-support-using-displayio/library-overview
            # https://docs.circuitpython.org/en/latest/shared-bindings/bitmaptools/index.html#bitmaptools.draw_line
        else:
            print("found images at '" + self.path + "':")
            for img in self.images:
                print("  ", img)

        self.image_num = 0  # Current selected image index in self.path
        self.filename = self.path + "/" + self.images[self.image_num]

        self.num_rows = 0  # Nothing loaded yet
        self.loop = self.config["POVPainter"]["loop"]  # Repeat image playback
        # LED brightness, 0.0 (off) to 1.0 (bright)
        self.brightness = self.config["POVPainter"]["brightness"]
        self.config_mode = 0  # Current setting being changed
        self.rect = None  # Multipurpose     progress/setting rect
        # self.time = (len(self.times) + 1) // 2  # default to center of range

        print("brightness: {:>4.3}".format(self.brightness))
        self.setup_hw()

        # only setup things..
        self.rows_per_second = -1
        self.row_size = -1

        # start pixel...
        self.spi_init()

        # next time spi_init is called we will do benchmark and image loading..
        self.first_run = True

        self.spi_deinit()

        # we need to to this as last action -
        # otherwise we get into dependency hell as not all things shown in status line are initialized..
        self.print = print_fn

    ##########################################
    # properties

    @property
    def brightness(self):
        # return super(ModeBaseClass, self).brightness * 2
        return helper.map_to_01(
            ModeBaseClass.brightness,
            self.brightness_range[0],
            self.brightness_range[1],
        )

    @brightness.setter
    def brightness(self, value):
        # super(POVPainter, self).brightness = value
        # https://github.com/python/cpython/issues/59170#issuecomment-1093581234
        # we need a workaround..
        # ModeBaseClass.brightness=value

        # value = helper.limit(value, 0.0, 1.0)
        # self._brightness = value

        # Remap brightness from 0.0-1.0 to brightness_range.
        ModeBaseClass.brightness = helper.map_01_to_constrained(
            value,
            self.brightness_range[0],
            self.brightness_range[1],
        )
        if self.spi_init_done:
            self.load_image()

    @property
    def brightness_mapped(self):
        return ModeBaseClass.brightness

    ##########################################
    # sub system init

    def first_run_init(self):
        # Determine filesystem-to-LEDs throughput (also clears LED strip)
        self.rows_per_second, self.row_size = self.benchmark()
        self.clear_strip()
        print(
            "rows_per_second: {}, row_size: {}".format(
                self.rows_per_second,
                self.row_size,
            )
        )

        self.load_image()

    def spi_init(self):
        # deactivate internal displays...
        # displayio.release_displays()
        self.dotstar = busio.SPI(
            clock=helper.get_pin(
                config=self.config, bus_name="pixel_spi_pins", pin_name="clock"
            ),
            MOSI=helper.get_pin(
                config=self.config, bus_name="pixel_spi_pins", pin_name="data"
            ),
        )
        while not self.dotstar.try_lock():
            pass
        self.dotstar.configure(baudrate=12000000)
        # initially set to black
        self.dotstar.write(bytearray([0x00, 0x00, 0x00, 0x00]))
        for r in range(36 * 5):
            self.dotstar.write(bytearray([0xFF, 0x00, 0x00, 0x00]))
        self.dotstar.write(bytearray([0xFF, 0xFF, 0xFF, 0xFF]))

        if self.first_run:
            self.first_run_init()
            self.first_run = False

        self.spi_init_done = True

    def spi_deinit(self):
        # https://github.com/adafruit/Adafruit_CircuitPython_DotStar/pull/65
        self.dotstar.unlock()
        self.dotstar.deinit()
        self.spi_init_done = False

    def setup_hw(self):
        # self.dotstar = busio.SPI(board.IO36, board.IO35)
        # https://docs.circuitpython.org/en/latest/shared-bindings/neopixel_write/index.html
        # import neopixel_write
        # import digitalio
        # pixel_pin = digitalio.DigitalInOut(board.NEOPIXEL)
        # pixel_pin.direction = digitalio.Direction.OUTPUT
        # neopixel_write.neopixel_write(pixel_pin, bytearray([1, 1, 1]))
        pass

    def setup_ui(self):
        # self.ui = ui.POVPainterUI(magicpainter=self)
        pass

    ##########################################
    # helper

    def check_filesystem_writeable(self):
        """
        check if filesystem is writeable.
        """
        writeable = False
        try:
            with open("writeable.test", "wb") as file:
                writeable = True
        except OSError as error:
            #  error.args[0] == 28:  # If the file system is full...
            if error.errno == 30:
                # Read-only filesystem
                print(error)
                writeable = False
            else:
                print(error)
                raise error
        return writeable

    ##########################################
    # dotstar helper

    def dotstar_set_pixel(self, *, begin, end, r, g, b):
        """
        Set range of dotstar pixel to color.
        """
        pixel_count = self.bmp2led.pixel_count
        begin = helper.limit(begin, 0, pixel_count - 1)
        end = helper.limit(end, 0, pixel_count - 1)
        pixel_on_count = (end - begin) + 1
        pixel_off_end_count = (pixel_count - 1) - end

        off_pixel = [255, 0, 0, 0]
        on_pixel = [255, 0, 0, 0]
        on_pixel[1 + self.bmp2led.red_index] = r
        on_pixel[1 + self.bmp2led.green_index] = g
        on_pixel[1 + self.bmp2led.blue_index] = b

        buffer = bytearray(
            # header
            [0] * 4
            # pixel data
            + off_pixel * begin
            + on_pixel * pixel_on_count
            + off_pixel * pixel_off_end_count
            # + off_pixel
            # tail
            + [255] * ((pixel_count + 15) // 16)
        )
        self.dotstar.write(buffer)

    def clear_strip(self):
        """
        Turn off all LEDs of the DotStar strip.
        """
        self.dotstar.write(
            bytearray(
                [0] * 4
                + [255, 0, 0, 0] * self.bmp2led.pixel_count
                + [255] * ((self.bmp2led.pixel_count + 15) // 16)
            )
        )

    def load_progress(self, amount):
        """
        Callback function for image loading, moves progress bar on display.
        Arguments:
            amount (float) : Current 'amount loaded' coefficient; 0.0 to 1.0
        """
        # self.rect.x = int(board.DISPLAY.width * (amount - 1.0))
        # self.terminal_progressbar.update(amount)
        num_on = int(amount * self.bmp2led.pixel_count + 0.5)
        self.dotstar_set_pixel(begin=0, end=num_on, r=0, g=1, b=0)
        # num_off = self.bmp2led.pixel_count - num_on
        # off_pixel = [255, 0, 0, 0]
        # on_pixel = [255, 0, 0, 0]
        # on_pixel[1 + self.bmp2led.green_index] = 1
        # self.dotstar.write(
        #     bytearray(
        #         [0] * 4
        #         + on_pixel * num_on
        #         + off_pixel * num_off
        #         + [255] * ((self.bmp2led.pixel_count + 15) // 16)
        #     )
        # )

    def dotstar_blink(self, blink_count=5, duration=1, r=1, g=0, b=0):
        blink_duration = duration / (blink_count * 2)
        for blink in range(blink_count):
            self.dotstar_set_pixel(begin=0, end=2, r=r, g=g, b=b)
            time.sleep(blink_duration)
            self.clear_strip()
            time.sleep(blink_duration)

    ##########################################
    # draw helper

    def paint_testpattern1(self, backwards=False):
        c_on = int(helper.map_01_to(self.brightness, 0x00, 0xFF))
        width = self.bmpHeight
        bmp_range = range(width)
        if backwards:
            bmp_range = range(width - 1, -1, -1)
        for col in bmp_range:
            row = bytearray([0xFF, 0x01, 0x00, 0x00] * self.bmpHeight)
            # if col == 0:
            #     row = bytearray([0xFF, c_on, 0x00, 0x00] * self.bmpHeight)
            # else:
            # row = bytearray(self.bmpHeight * 4)

            # paint a white diagonal line
            # row[col*4:col*4+4] = bytearray([0xFF, c_on, 0x00, 0x00])
            row[col * 4 : col * 4 + 4] = bytearray([0xFF, c_on, c_on, c_on])

            # last led with color coded direction
            # red forwards
            row[-4:] = bytearray([0xFF, 0x00, 0x00, c_on])
            if backwards:
                # green backwards
                row[-4:] = bytearray([0xFF, 0x00, c_on, 0x00])

            self.dotstar.write(bytearray([0x00, 0x00, 0x00, 0x00]))
            self.dotstar.write(row)
            self.dotstar.write(bytearray([0x00, 0x00, 0x00, 0x00]))
            time.sleep(self.pixel_delay)

        # clear it out
        self.dotstar.write(bytearray([0x00, 0x00, 0x00, 0x00]))
        for r in range(self.bmpHeight * 5):
            self.dotstar.write(bytearray([0xFF, 0x00, 0x00, 0x00]))
        self.dotstar.write(bytearray([0xFF, 0xFF, 0xFF, 0xFF]))
        gc.collect()

    ##########################################
    # load and draw v1

    # def load_image_v1_to_buffer(self, filename, self.image_buffer):
    def load_image_v1(self, filename=None):
        """
        Load image into buffer.

        Arguments:
            filename (string) : full filename (inkl. path) to load.
        """
        if filename is None:
            filename = self.filename
        print("load_image_v1: \n" "    file: '{}'\n" "".format(filename))
        try:
            with open("/" + filename, "rb") as f:
                print("File opened")
                if f.read(2) != b"BM":  # check signature
                    raise BMPError("Not BitMap file")

                bmpFileSize = read_le(f.read(4))
                f.read(4)  # Read & ignore creator bytes

                bmpImageoffset = read_le(f.read(4))  # Start of image data
                headerSize = read_le(f.read(4))
                self.bmpWidth = read_le(f.read(4))
                self.bmpHeight = read_le(f.read(4))
                flip = True

                print(
                    "Size: %d\nImage offset: %d\nHeader size: %d"
                    % (bmpFileSize, bmpImageoffset, headerSize)
                )
                print("Width: %d\nHeight: %d" % (self.bmpWidth, self.bmpHeight))

                if read_le(f.read(2)) != 1:
                    raise BMPError("Not singleplane")
                bmpDepth = read_le(f.read(2))  # bits per pixel
                print("Bit depth: %d" % (bmpDepth))
                if bmpDepth != 24:
                    raise BMPError("Not 24-bit")
                if read_le(f.read(2)) != 0:
                    raise BMPError("Compressed file")

                print("Image OK!")

                rowSize = (self.bmpWidth * 3 + 3) & ~3  # 32-bit line boundary

                # its huge! but its also fast :)
                self.image_buffer = bytearray(self.bmpWidth * self.bmpHeight * 4)
                print("loading...\n")
                # currently the ProgressBar crashes CP if not connected to the computer..
                # no idea why.. so for now - just do not use it..
                # maybe it is a memory overflow thing?!
                # TODO: add issue
                # self.terminal_progressbar = ProgressBar()
                for row in range(self.bmpHeight):  # For each scanline...
                    if flip:  # Bitmap is stored bottom-to-top order (normal BMP)
                        pos = bmpImageoffset + (self.bmpHeight - 1 - row) * rowSize
                    else:  # Bitmap is stored top-to-bottom
                        pos = bmpImageoffset + row * rowSize

                    # print ("seek to %d" % pos)
                    f.seek(pos)
                    for col in range(self.bmpWidth):
                        b, g, r = bytearray(f.read(3))  # BMP files store RGB in BGR
                        # front load brightness, gamma and reordering here!
                        order = [b, g, r]
                        idx = (col * self.bmpHeight + (self.bmpHeight - row - 1)) * 4
                        self.image_buffer[idx] = 0xFF  # first byte is 'brightness'
                        idx += 1
                        for color in order:
                            self.image_buffer[idx] = int(
                                pow((color * self.brightness_mapped) / 255, 2.7) * 255
                                + 0.5
                                # pow((color * 1.0) / 255, 2.7) * 255 + 0.5
                            )
                            idx += 1
                    self.load_progress(row / (self.bmpHeight - 1))

        except OSError as e:
            if e.args[0] == 28:
                raise OSError("OS Error 28 0.25")
            else:
                raise OSError("OS Error 0.5")
        except BMPError as e:
            print("Failed to parse BMP: " + e.args[0])

        gc.collect()
        print(gc.mem_free())
        print("Ready to go!")
        print("load_image_v1 " "('{}') " "done.\n" "".format(filename))
        self.clear_strip()

    def paint_v1(self, backwards=False):
        # print("Draw!")
        index = 0
        bmp_range = range(self.bmpWidth)
        if backwards:
            bmp_range = range(self.bmpWidth - 1, -1, -1)
        for col in bmp_range:
            row = self.image_buffer[index : index + self.bmpHeight * 4]

            # debug output
            # overwrite last led with color coded direction
            # red forwards
            # row[-4:] = bytearray([0xFF, 0x00, 0x00, 0x01])
            # if backwards:
            #     # green backwards
            #     row[-4:] = bytearray([0xFF, 0x00, 0x01, 0x00])

            self.dotstar.write(bytearray([0x00, 0x00, 0x00, 0x00]))
            self.dotstar.write(row)
            self.dotstar.write(bytearray([0x00, 0x00, 0x00, 0x00]))
            index += self.bmpHeight * 4
            time.sleep(self.pixel_delay)

        # clear it out
        self.dotstar.write(bytearray([0x00, 0x00, 0x00, 0x00]))
        for r in range(self.bmpHeight * 5):
            self.dotstar.write(bytearray([0xFF, 0x00, 0x00, 0x00]))
        self.dotstar.write(bytearray([0xFF, 0xFF, 0xFF, 0xFF]))
        gc.collect()

    ##########################################
    # CLUE V2 version
    def benchmark(self):
        """
        Estimate filesystem-to-LED-strip throughput.
        Returns: rows-per-second throughput (int), LED row size in bytes
        (including DotStar header and footer) (int).
        """

        # Generate a small temporary file equal to one full LED row,
        # all set 'off'.
        row_data = bytearray(
            [0] * 4
            + [255, 0, 0, 0] * self.bmp2led.pixel_count
            + [255] * ((self.bmp2led.pixel_count + 15) // 16)
        )
        row_size = len(row_data)

        if self.fs_writeable:
            try:
                with open(self.led_data_file_benchmark, "wb") as file:
                    file.write(row_data)
            except OSError as error:
                if error.errno == 30:
                    # Read-only filesystem
                    print(error)
                else:
                    raise error

        # For a period of 1 second, repeatedly seek to start of file,
        # read row of data and write to LED strip as fast as possible.
        # Not super precise, but good-enough guess of light painting speed.
        # (Bonus, this will turn off LED strip on startup).
        rows = 0
        with open(self.led_data_file_benchmark, "rb") as file:
            start_time = time.monotonic()
            while time.monotonic() - start_time < 1.0:
                file.seek(0)
                file.readinto(row_data)
                self.dotstar.write(row_data)
                time.sleep(0.001)  # See notes in paint()
                rows += 1

        return rows, row_size

    def load_image_v2(self, filename=None):
        if filename is None:
            filename = self.filename
        """
        Load BMP from image list, determined by variable self.image_num
        (not a passed argument). Data is converted and placed in
        self.tempfile.
        """
        print("loading...\n")
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

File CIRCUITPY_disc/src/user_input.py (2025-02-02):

# SPDX-FileCopyrightText: 2023 Stefan Krüger s-light.eu
# SPDX-License-Identifier: MIT

import time

import board

import digitalio
import touchio
import keypad
from adafruit_debouncer import Debouncer

import neopixel

import busio

import ansi_escape_code as terminal
import nonblocking_serialinput as nb_serial

import helper

from configdict import extend_deep
from gesture_detector import GestureDetector, gestures
from gesture_detector import (
    UNKNOWN,
    REST,
    REST_HORIZONTAL,
    REST_VERTICAL,
    TILT_LEFT,
    TILT_RIGHT,
    TAB_X,
    TAB_Y,
    TAB_Z,
    DIRECTION_CHANGED,
    SHAKE_X,
    SHAKE_Y,
    SHAKE_Z,
)


class AccelerationSensorNotFound(TypeError):
    pass


class TouchEvent(object):
    def __init__(self, *, touch_id, touch):
        self.touch_id = touch_id
        self.touch = touch

    def __str__(self):
        return "TouchEvent: id:{} touch:{}".format(self.touch_id, self.touch)


class UserInput(object):
    """UserInput."""

    config_defaults = {
        "hw": {
            "touch": {
                "pins": [
                    # board.D5,
                    # board.D6,
                    # board.D7,
                ],
                "threshold": 4000,
                "auto_calibration_delay": 30,
            },
            "button": {
                "pins": [
                    # board.A0,
                    # board.A1,
                    # board.A2,
                    # board.D5,
                    # board.D6,
                    # board.D7,
                    # board.D8,
                    # board.D9,
                    # board.D17,
                    # board.D18,
                ],
                "pin_gnd": board.D8,
            },
            "accel_i2c_pins": {
                "clock": "SCL1",
                "data": "SDA1",
            },
        },
    }

    def __init__(
        self, *, config, magicpainter, callback_button, callback_touch, callback_gesture
    ):
        super(UserInput, self).__init__()
        self.print = print
        self.print("init UserInput..")

        self.config = config
        ##########################################
        # handle board specific i2c pin usage

        if not self.config.get("hw"):
            self.config["hw"] = {
                "accel_i2c_pins": {
                    "clock": "SCL",
                    "data": "SDA",
                }
            }

            if "qtpy_esp32s3" in board.board_id:
                self.config["hw"]["accel_i2c_pins"] = {
                    "clock": "SCL1",
                    "data": "SDA1",
                }
        extend_deep(self.config, self.config_defaults.copy())

        self.magicpainter = magicpainter

        # this also sets self.print
        self.setup_serial()

        # status led
        self.status_pixel = neopixel.NeoPixel(board.NEOPIXEL, 1)
        self.status_pixel.fill((0, 0, 0))

        self.callback_button = callback_button
        self.callback_touch_main = callback_touch
        self.callback_gesture_main = callback_gesture

        self.init_userInput()
        self.touch_reset_threshold()

        self.accel_sensor_init()
        self.gesture = GestureDetector(
            accel_sensor=self.accel_sensor,
            callback_gesture=self.callback_gesture,
            print_fn=self.print,
        )
        # self.gesture.plot_data = True

        self.touch_active = False

    # ~~~~~~~~~~~~~~~~~~~~~~~~~~~~~~~~~~~~~~~~~~
    # sub init
    # ~~~~~~~~~~~~~~~~~~~~~~~~~~~~~~~~~~~~~~~~~~

    def init_userInput(self):
        self.button_init()

        self.touch_init()

    def button_init(self):
        print("button_init..")
        # https://learn.adafruit.com/key-pad-matrix-scanning-in-circuitpython/advanced-features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
        button_list = [board.BUTTON]
        button_list.extend(self.config["hw"]["button"]["pins"])
        print("  button_list", button_list)

        self.button_GND = digitalio.DigitalInOut(self.config["hw"]["button"]["pin_gnd"])
        self.button_GND.switch_to_output()
        self.button_GND.value = 0

        self.button = keypad.Keys(
            button_list,
            value_when_pressed=False,
            pull=True,
        )
        self.button_event = keypad.Event()

    def touch_init(self):
        print("touch_init..")
        self.touch_active = True
        self.touch_last_action = time.monotonic()
        self.touch_auto_calibration_delay = self.config["hw"]["touch"][
            "auto_calibration_delay"
        ]

        self.touch_pins = []
        self.touch_pins_debounced = []
        for touch_id, touch_pin in enumerate(self.config["hw"]["touch"]["pins"]):
            touch = touchio.TouchIn(touch_pin)
            # initialise threshold to maximum value.
            # we later fix this..
            # we need some time passed to be able to get correct readings.
            touch.threshold = 65535
            self.touch_pins.append(touch)
            self.touch_pins_debounced.append(Debouncer(touch))
            print(
                "{:>2} {:<9}: "
                "touch.raw_value {:>5}"
                "".format(
                    touch_id,
                    str(touch_pin),
                    touch.raw_value,
                )
            )
        print(f"setup {len(self.touch_pins)} touch inputs.")

    def accel_sensor_init(self):
        """Init the acceleration sensor."""
        print("accel_sensor_init..")
        self.i2c = busio.I2C(
            scl=helper.get_pin(
                config=self.config, bus_name="accel_i2c_pins", pin_name="clock"
            ),
            sda=helper.get_pin(
                config=self.config, bus_name="accel_i2c_pins", pin_name="data"
            ),
            frequency=400000,
        )
        print("  i2c scan:")
        print("  lock:", self.i2c.try_lock())
        i2c_address_list_hex = ["0x{:x}".format(adr) for adr in self.i2c.scan()]
        print("  i2c devices:", i2c_address_list_hex)
        print("  unlock:", self.i2c.unlock())
        # self.accel_sensor = slight_lsm303d_accel.LSM303D_Accel(self.i2c)

        if "0x18" in i2c_address_list_hex:
            import adafruit_lis3dh

            self.accel_sensor = adafruit_lis3dh.LIS3DH_I2C(self.i2c)
            self.accel_sensor.range = adafruit_lis3dh.RANGE_16_G
            self.accel_sensor.data_rate = (
                adafruit_lis3dh.DATARATE_LOWPOWER_5KHZ
            )  # → 0,2ms
        elif "0x62" in i2c_address_list_hex:
            from adafruit_msa3xx import MSA311

            self.accel_sensor = MSA311(self.i2c)
        elif "0x62" in i2c_address_list_hex:
            from adafruit_bno08x import (
                BNO_REPORT_ACCELEROMETER,
                BNO_REPORT_LINEAR_ACCELERATION,
                BNO_REPORT_STABILITY_CLASSIFIER,
            )
            from adafruit_bno08x.i2c import BNO08X_I2C
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

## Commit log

2023-03-03 basics working again..
    [export_shake.csv, material.ods]
2023-03-07 add pictures
    [material.ods]
2023-03-07 add hw information to readme
    [material.csv]
2023-05-11 updates and tests
    [export_shake2.csv, lis3dh_plot__config.csv, lis3dh_plot__export_shake.csv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]
2023-05-23 a big bunch of more tests and preparations
    [export_shake.csv, export_shake2.csv, lis3dh_plot__export_shake.csv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]
2023-05-23 add export
    [lis3dh_plot_with_shake_detection__export.csv]
2023-05-24 folder structure cleanup
    [lis3dh_plot__export_shake.csv, lis3dh_plot__export_shake.ods, lis3dh_plot_with_shake_detection__export.csv]
2023-05-29 and even more tests...
    [material.csv, material.ods, order.ods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]
2023-08-08 case cad construction
    [LIS3DH.FCStd, QT Py ESP32-S3.FCStd, case.FCStd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]
2023-08-19 hw case design done.
    [QT Py ESP32-S3.FCStd, case_drawings.FCStd, case_parts.dxf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]
2023-08-20 hw case - fix alignment hole size
    [case_drawings.FCStd, case_parts.dxf]
2023-08-21 fix & reexport hw case
    [case_assembly.FCStd, case_assembly_drawings.FCStd, case_drawings.FCStd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]
2023-08-27 rework full config system
    [config_base.py, helper.py, magicpainter.py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]
2023-08-27 HW some export tests
    [case_drawings.FCStd, case_parts__LCWorkbenchExport.dxf, case_parts_mod__test__R14.dxf]
2023-09-12 hw new version
    [LIS3DH.FCStd, QT Py ESP32-S3.FCStd, case_assembly.FCStd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]
2023-09-15 move fw things to fw directory
    [case_assembly.FCStd, lis3dh_plot__export_shake.ods]
2023-09-18 more docu
    [order.ods]
2023-09-18 rename `fw` subfolder to `CIRCUITPY_disc`
    [lis3dh_plot__export_shake.ods]
2023-09-18 move `tests` to root level `cp_tests`
    [lis3dh_plot__export_shake.ods]
2023-09-22 switch theme
2023-09-23 hw add cover layer
    [case_assembly.FCStd, case_drawings.FCStd]
2023-09-30 prepare gesture filter
2023-11-21 add multi acceleraion sensor setup..
2023-11-21 add display off handling for tft boards.
2023-11-21 laternen flacker mode
    [material.ods, order.ods]
2023-12-22 add docu update_firmware/de
2023-12-25 tried to fix backwards painting
    [povpainter.py]
2024-01-01 gesture done. giving up on tab detection. for povpainter: tilt right for image switch.
2024-05-16 small tweaks
    [material 2.ods]
2024-07-22 hw: prepare case mod
    [case_assembly.FCStd]
2024-07-27 hw case added buttons
    [OMRON_BF3-105x.FCStd, case_assembly.FCStd, case_assembly_drawings.FCStd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]
2024-07-28 fixed stand
    [case_assembly.FCStd, case_drawings.FCStd, case_parts.dxf]
2024-07-28 update export drawings
    [case_drawings.FCStd, case_parts_menueexport.dxf]
2024-08-01 updated powerbank button
    [QT Py ESP32-S3.FCStd, case_drawings.FCStd, case_parts_menueexport.dxf]
2024-08-01 added 2mm cover and buttons
    [QT Py ESP32-S3.FCStd, case_drawings.FCStd, case_parts.dxf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]
2024-08-01 add manually cleanud up exports
    [case_parts_2mm_mod mancleanup.dxf, case_parts_4mm_mod mancleanup.dxf]
2024-08-06 extended side walls
    [case_drawings.FCStd, case_parts_2mm.dxf, case_parts_4mm.dxf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]
2024-08-23 tweaks to case + export
    [case_drawings.FCStd, case_parts_1,5mm_Kraftplex.dxf, case_parts_2mm.dxf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]
2024-09-18 add buttons
2024-10-06 add dimensions sketch
    [case_assembly__layer-2-101.step, case_drawings.FCStd]
